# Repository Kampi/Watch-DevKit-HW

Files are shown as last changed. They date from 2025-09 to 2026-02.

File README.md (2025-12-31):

# ZSWatch-Watch-DevKit



## 📑 Table of Contents

- [ZSWatch-Watch-DevKit](#zswatch-watch-devkit)
  - [📑 Table of Contents](#-table-of-contents)
  - [📖 About](#-about)
  - [📂 Directory Breakdown](#-directory-breakdown)
  - [Purchasing](#purchasing)
  - [Ressources](#ressources)
  - [👨‍💻 Maintainer](#-maintainer)

## 📖 About

The **ZSWatch-Watch-DevKit** project provides the hardware design and production files for a smartwatch development board tailored to the ZSWatch ecosystem.
It is built with **KiCad** and integrates a full **CI/CD pipeline** using **KiBot**, ensuring reproducible outputs for documentation, manufacturing, and releases.

Key features:

- 🛠️ Open-source hardware design
- 📦 Automated generation of Gerber, BoM, and documentation via KiBot
- 🔄 Workflow stages (DRAFT → PRELIMINARY → CHECKED → RELEASED) for structured releases
- 📝 Clear documentation and changelog to track progress
- 🌍 Designed with collaboration and transparency in mind

Please check the [wiki](https://github.com/ZSWatch/ZSWatch/wiki) for more information about the project.

You can also view this project on [CADLAB.io](https://cadlab.io/project/29658). 

## 📂 Directory Breakdown

- **`.github`**: GitHub related files
- **`.gitignore`**: Ignored files list
- **`devkit`**: KiCad project for the devkit
- **`production`**: Manufacturing outputs (Gerbers, documentation, etc.)
- **`CHANGELOG.md`**: Version history
- **`LICENSE`**: Project license (GPL-3.0)
- **`README.md`**: Project overview

## Purchasing

TBD

## Ressources

- [KiBot Template](https://github.com/nguyen-v/KDT_Hierarchical_KiBot)

## 👨‍💻 Maintainer

- [Daniel Kampert](mailto:danielkameprt@kampis-elektroecke.de)

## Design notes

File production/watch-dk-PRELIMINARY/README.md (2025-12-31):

<p align="center" width="100%">
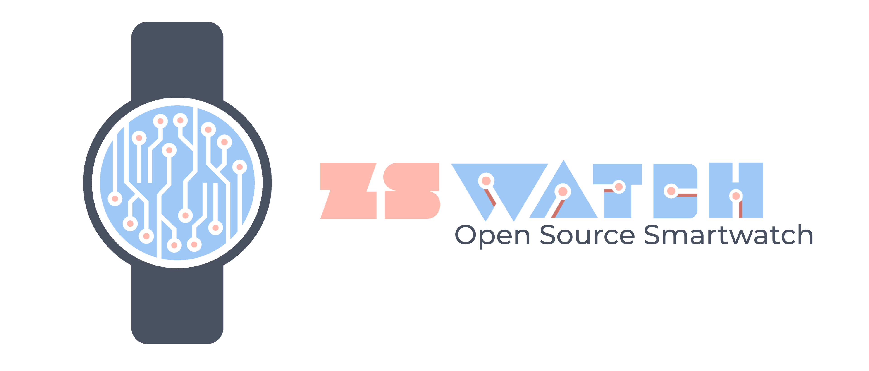
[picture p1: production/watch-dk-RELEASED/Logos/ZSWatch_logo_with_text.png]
  
</p>

<h1 align="center">Watch-DevKit-HW</h1>

<p align="center" width="100%">
  <a href="https://github.com/ZSWatch/Watch-DevKit-HW/actions/workflows/devkit.yaml">
    
  </a>
</p>

***

<p align="center">
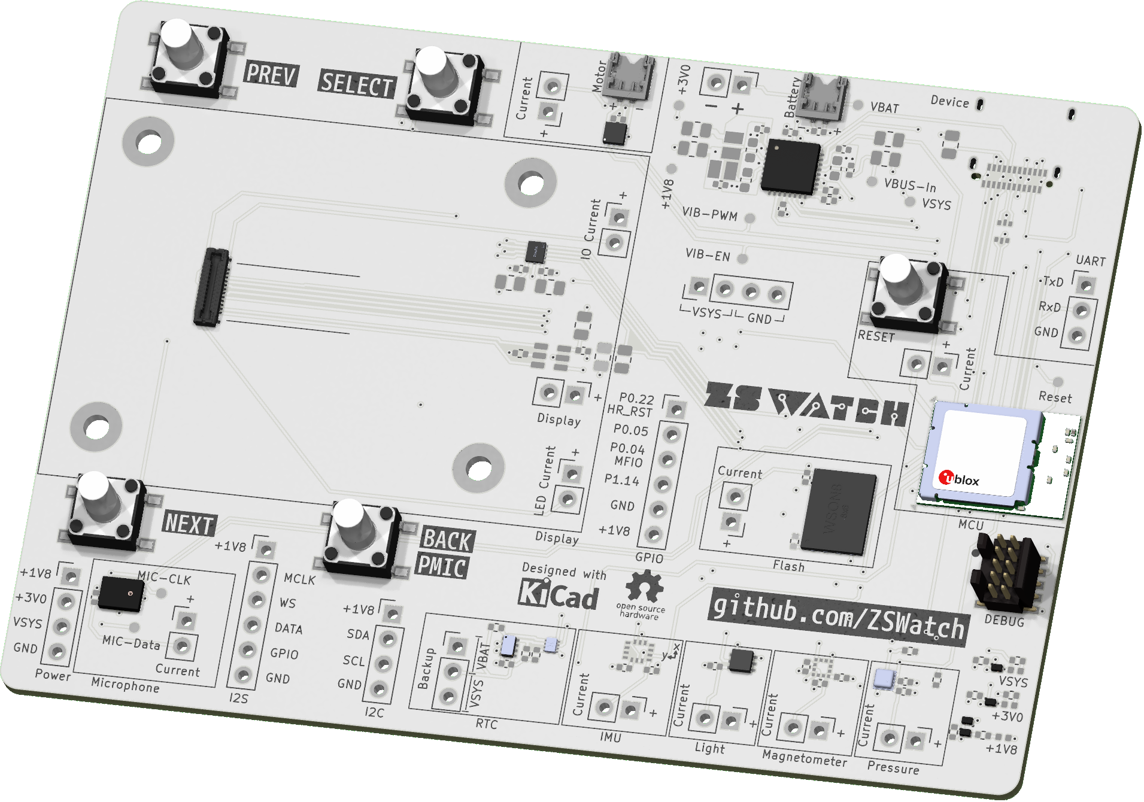
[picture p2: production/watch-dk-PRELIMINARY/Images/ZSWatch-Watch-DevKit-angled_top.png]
3D Top Angled
  
&nbsp; &nbsp; &nbsp; &nbsp;
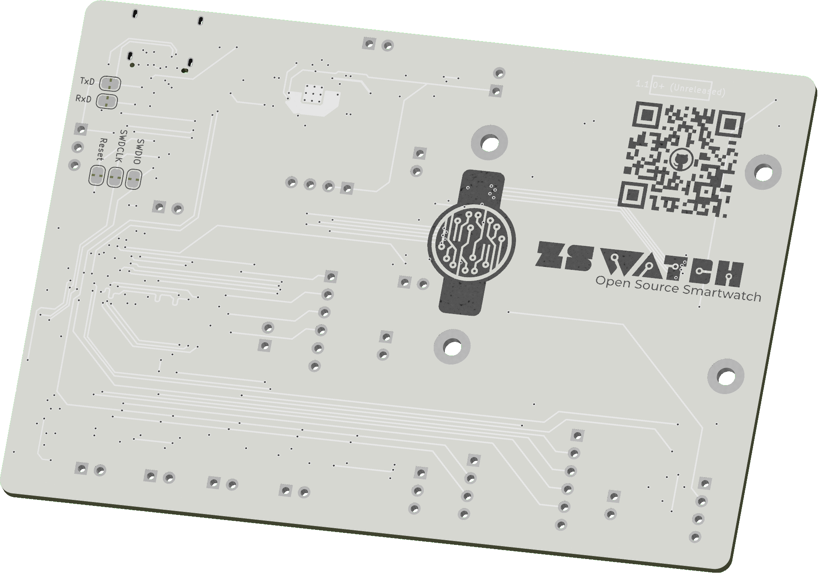
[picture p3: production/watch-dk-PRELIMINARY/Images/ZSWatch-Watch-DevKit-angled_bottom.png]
3D Bottom Angled
  
</p>

***

## SPECIFICATIONS

| Parameter | Value |
| --- | --- |
| Dimensions | 100.0 × 70.0 mm |

***

## DIRECTORY STRUCTURE

    .
    ├─ Computations       # Misc calculations
    ├─ HTML               # HTML files for generated webpage
    ├─ Images             # Pictures and renders
    │
    ├─ kibot_resources    # External resources for KiBot
    │  ├─ colors          # Color theme for KiCad
    │  ├─ fonts           # Fonts used in the project
    │  ├─ scripts         # External scripts used with KiBot
    │  └─ templates       # Templates for KiBot generated reports
    │
    ├─ kibot_yaml         # KiBot YAML config files
    ├─ KiRI               # KiRI (PCB diff viewer) files
    │
    ├─ lib                # KiCad footprint and symbol libraries
    │  ├─ 3d_models       # Component 3D models
    │  ├─ lib_fp          # Footprint libraries
    │  └─ lib_sym         # Symbol libraries
    │
    ├─ logos              # Logos
    │
    ├─ Manufacturing      # Assembly and fabrication documents
    │  ├─ Assembly        # Assembly documents (BoM, pos, notes)
    │  │
    │  └─ Fabrication     # Fabrication documents (ZIP, notes)
    │     ├─ Drill Tables # CSV drill tables
    │     └─ Gerbers      # Gerbers
    │
    ├─ Report             # Reports for ERC/DRC
    ├─ Schematic          # PDF of schematic
    ├─ templates          # Title block templates
    ├─ Testing
    │  └─ Testpoints      # Testpoints tables
    │
    └─ Variants           # Outputs for assembly variants

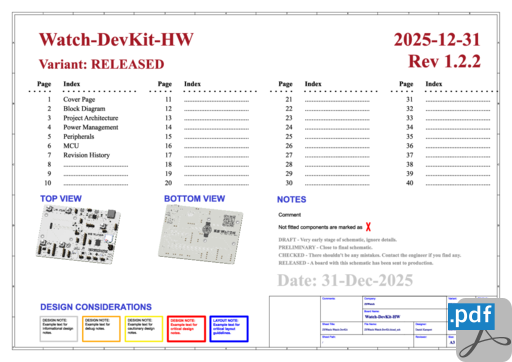
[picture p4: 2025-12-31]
production/watch-dk-RELEASED/HTML/images/cat_pdf_schematic_ZSWatch-Watch-DevKit-schematic.png

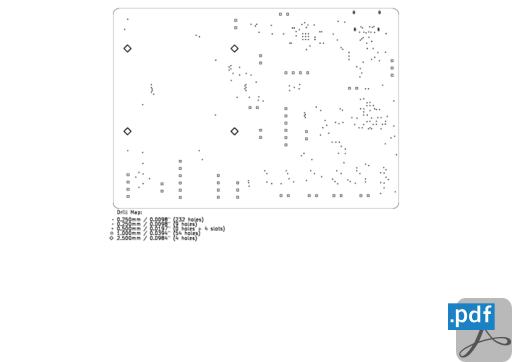
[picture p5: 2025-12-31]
production/watch-dk-RELEASED/HTML/images/cat_pdf_drill_map_ZSWatch-Watch-DevKit-PTH_drill_map.png

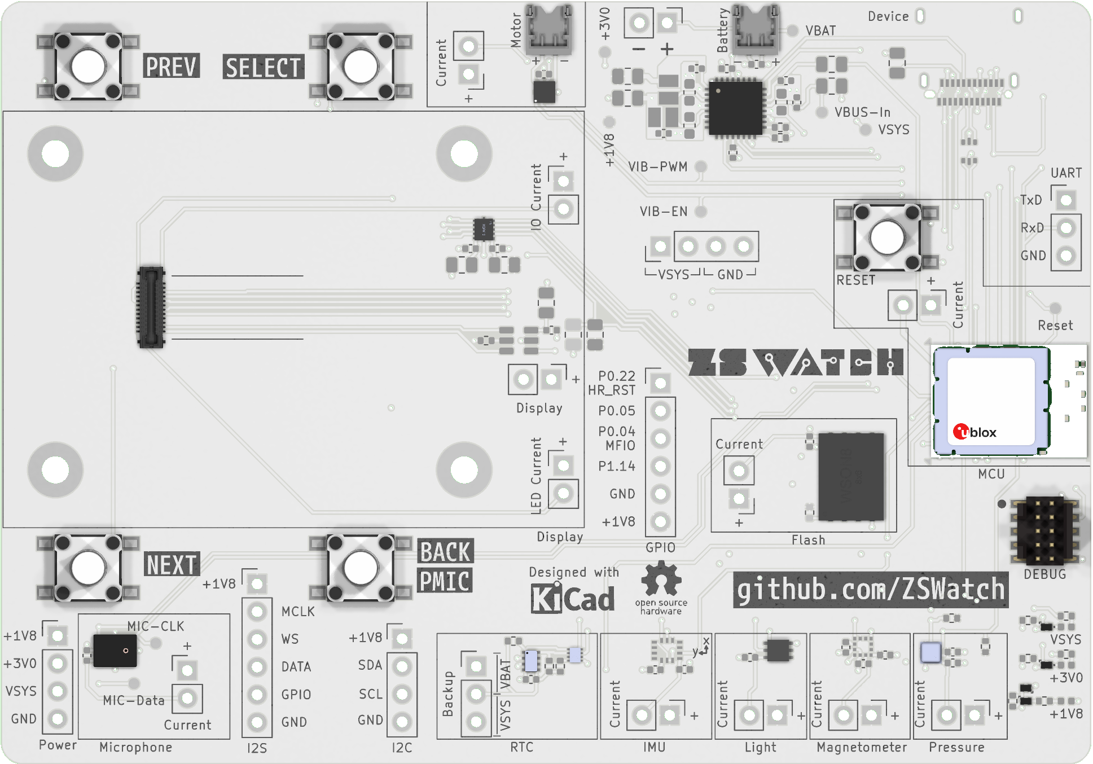
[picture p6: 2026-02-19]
production/watch-dk-PRELIMINARY/Images/ZSWatch-Watch-DevKit-top.png

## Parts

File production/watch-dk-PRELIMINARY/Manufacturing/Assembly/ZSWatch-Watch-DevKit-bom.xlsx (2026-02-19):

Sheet: BoM
Bill of Materials
Schematic: | ZSWatch-Watch-DevKit | Component Groups: | 50
Variant: | PRELIMINARY | Component Count: | 111 (81 SMD/ 19 THT)
Revision: |  | Fitted Components: | 111 (81 SMD/ 19 THT)
Date: | 2025-07-13 | Number of PCBs: | 1
KiCad Version: | 9.0.7+1 | Total Components: | 111
Row | Quantity Per PCB | References | manf | manf# | Datasheet | Footprint | Description
1 | 13 | C402 C501 C502 C503 C504 C507 C508 C509 C510 C511 C602 C603 C604 | KYOCERA AVX | 0402ZC104KAT4A | https://datasheets.kyocera-avx.com/KGM_X7R.pdf | C_0402_1005Metric | Unpolarized capacitor, small symbol
2 | 1 | C505 | KYOCERA AVX | 04023C224KAT2A | https://datasheets.kyocera-avx.com/KGM_X7R.pdf | C_0402_1005Metric | Unpolarized capacitor, small symbol
3 | 3 | C401 C405 C601 | KYOCERA AVX | 04023D105KAT2A | https://datasheets.kyocera-avx.com/cx5r.pdf | C_0402_1005Metric | Unpolarized capacitor, small symbol
4 | 1 | C403 | KYOCERA AVX | 0402ZD225MAT2A | https://datasheets.kyocera-avx.com/cx5r.pdf | C_0402_1005Metric | Unpolarized capacitor, small symbol
5 | 4 | C404 C406 C408 C506 | Murata Electronics | GRJ155R60J106ME11D | https://search.murata.co.jp/Ceramy/image/img/A01X/G101/ENG/GRJ155R60J106ME11-02A.pdf | C_0402_1005Metric | Unpolarized capacitor, small symbol
6 | 3 | C407 C409 C410 | KYOCERA AVX | KGM15CR50J106MT | https://datasheets.kyocera-avx.com/cx5r-KGM.pdf | C_0603_1608Metric | Unpolarized capacitor, small symbol
7 | 1 | D403 | Lumex | SML-LX0402SUGC-TR | https://www.mouser.de/datasheet/3/389/1/SSF-LXH100GD-RP.pdf | LED_0402_1005Metric | Light emitting diode
8 | 1 | D401 | Lumex | SML-LX0402SUGC-TR | https://www.mouser.de/datasheet/3/389/1/SSF-LXH100GD-RP.pdf | LED_0402_1005Metric | Light emitting diode
9 | 1 | D402 | Lumex | SML-LX0402SUGC-TR | https://www.mouser.de/datasheet/3/389/1/SSF-LXH100GD-RP.pdf | LED_0402_1005Metric | Light emitting diode
10 | 1 | IC501 | Broadcom / Avago | APDS-9306-065 | https://docs.broadcom.com/docs/AV02-4755EN | Broadcom_DFN-6_2x2mm_P0.65mm | Ambient Light Sensor, I2C interface, 1.7-3.6V, DFN-6
11 | 1 | IC502 | Bosch | BMI270 | https://www.bosch-sensortec.com/media/boschsensortec/downloads/datasheets/bst-bmi270-ds000.pdf | Bosch_LGA-14_3x2.5mm_P0.5mm_LayoutBorder3x4y
12 | 1 | IC504 | Bosch | BMP581 | https://www.bosch-sensortec.com/media/boschsensortec/downloads/datasheets/bst-bmp581-ds004.pdf | Bosch_LGA-10_2x2mm_P0.5mm_ClockwisePinNumbering
13 | 1 | IC505 | Texas Instruments | DRV2603RUNT | https://www.ti.com/lit/ds/symlink/drv2603.pdf?HQS=dis-mous-null-mousermode-dsf-pf-null-wwe&ts=1692200896697 | WQFN-10_2x2mm_P0.5mm
14 | 1 | IC601 | onsemi / Fairchild | FAN5622SX | https://www.onsemi.com/download/data-sheet/pdf/fan5626-d.pdf | TSOT-23-6
15 | 1 | IC503 | STMicroelectronics | LIS2MDLTR | http://www.st.com/content/ccc/resource/technical/document/datasheet/group3/29/13/d1/e0/9a/4d/4f/30/DM00395193/files/DM00395193.pdf/jcr:content/translations/en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 | LGA-12_2x2mm_P0.5mm
16 | 1 | IC603 | Macronix | MX25U51245GZ4I00 | https://www.mouser.de/datasheet/2/819/MX25U51245G_2c_1_8V_2c_512Mb_2c_v1_4-3371129.pdf | WSON-8-1EP_8x6mm_P1.27mm_EP3.4x4.3mm
17 | 1 | IC604 | NXP Semiconductors | NTS0104GU12,115 | https://www.nxp.com/docs/en/data-sheet/NTS0104.pdf | XQFN-12-1.7x2mm_P0.4mm
18 | 1 | IC506 | NXP Semiconductors | PCA9306JKZ | https://www.nxp.com/docs/en/data-sheet/PCA9306.pdf | XSON-8_0.65x0.17mm_P0.35mm | Dual bidirectional I2C Bus and SMBus voltage level translator
19 | 1 | IC507 | Micro Crystal | RV-8263-C8 32.768kHz-20PPM-TA-QA | https://www.microcrystal.com/fileadmin/Media/Products/RTC/Datasheet/RV-8263-C8.pdf | RV-8263-C8
20 | 1 | IC602 | STMicroelectronics | USBLC6-2P6 | https://www.st.com/resource/en/datasheet/usblc6-2.pdf | SOT-666 | Very low capacitance ESD protection diode, 2 data-line, SOT-666
21 | 1 | IC401 | Nordic Semiconductor | nPM1300-QEAA-R7 | https://infocenter.nordicsemi.com/index.jsp?topic=%2Fstruct_pmic%2Fstruct%2Fnpm1300.html | QFN-32-1EP_5x5mm_P0.5mm_EP3.6x3.6mm_ThermalVias
22 | 11 | J501 J502 J503 J504 J505 J506 J507 J601 J602 J603 J604 | Würth Elektronik | 60900213421 | https://www.we-online.com/katalog/datasheet/60900213421.pdf |  | Generic jumper cap
23 | 2 | L401 L402 | ABRACON | ASMPH-0806-2R2M-T | https://www.mouser.de/datasheet/3/184/1/ASMPH-0806.pdf | L_0806_2016 | Inductor
24 | 1 | M601 | u-blox | NORA-B106-00B | https://www.u-blox.com/docs/UBX-20027119 | NORA-B106
25 | 1 | MK501 | Knowles | SPK0641HT4H-1 | https://www.knowles.com/docs/default-source/default-document-library/sph0645lm4h-1-datasheet.pdf | SPK0641HT4H-1 | Digital MEMS Microphone
26 | 3 | Q401 Q402 Q403 | Nexperia | PMZ550UNEYL | https://assets.nexperia.com/documents/data-sheet/PMZ550UNE.pdf | DFN-1006-3 | 0.59A Id, 30V Vds, N-Channel MOSFET, DFN-1006-3
27 | 1 | Q404 | ROHM Semiconductor | PMZB320UPEYL | https://assets.nexperia.com/documents/data-sheet/PMZB320UPE.pdf | DFN-1006-3 | 1A Id, 30V Vds
28 | 8 | R409 R410 R411 R412 R602 R603 R615 R616 | Bourns | CR0805-J/-000ELF | https://www.mouser.de/datasheet/3/40/1/cr.pdf | R_0805_2012Metric | Resistor, small symbol
29 | 3 | R404 R405 R406 | YAGEO | RC0402FR-07560RL | https://www.mouser.com/catalog/specsheets/YAGEO_PYu_RC_Group_51_RoHS_L_12.pdf | R_0402_1005Metric | Resistor, small symbol
30 | 2 | R501 R502 | YAGEO | RC0402FR-071K8L | https://www.mouser.com/catalog/specsheets/YAGEO_PYu_RC_Group_51_RoHS_L_12.pdf | R_0402_1005Metric | Resistor, small symbol
31 | 2 | R504 R505 | YAGEO | RC0402FR-073K3L | https://www.mouser.com/catalog/specsheets/YAGEO_PYu_RC_Group_51_RoHS_L_12.pdf | R_0402_1005Metric | Resistor, small symbol
32 | 1 | R601 | YAGEO | RC0402FR-0712KL | https://www.mouser.com/catalog/specsheets/YAGEO_PYu_RC_Group_51_RoHS_L_12.pdf | R_0402_1005Metric | Resistor, small symbol
33 | 1 | R407 | YAGEO | RC0402FR-0747KL | https://www.mouser.com/catalog/specsheets/YAGEO_PYu_RC_Group_51_RoHS_L_12.pdf | R_0402_1005Metric | Resistor, small symbol
34 | 4 | R401 R402 R403 R408 | YAGEO | RC0402FR-07100KL | https://www.mouser.com/catalog/specsheets/YAGEO_PYu_RC_Group_51_RoHS_L_12.pdf | R_0402_1005Metric | Resistor, small symbol
35 | 1 | R613 | YAGEO | RC0805FR-07100KL | https://www.mouser.com/catalog/specsheets/YAGEO_PYu_RC_Group_51_RoHS_L_12.pdf | R_0805_2012Metric | Resistor, small symbol
36 | 1 | R503 | YAGEO | RC0402FR-07200KL | https://www.mouser.com/catalog/specsheets/YAGEO_PYu_RC_Group_51_RoHS_L_12.pdf | R_0402_1005Metric | Resistor, small symbol
37 | 1 | S601 | Wurth Elektronik | 430182050816 | https://www.we-online.com/components/products/datasheet/430182050816.pdf | WS-TASV-6x6 | Push button switch, generic, two pins
38 | 1 | S501 | Wurth Elektronik | 430182050816 | https://www.we-online.com/components/products/datasheet/430182050816.pdf | WS-TASV-6x6 | Push button switch, generic, two pins
39 | 1 | S502 | Wurth Elektronik | 430182050816 | https://www.we-online.com/components/products/datasheet/430182050816.pdf | WS-TASV-6x6 | Push button switch, generic, two pins
40 | 1 | S503 | Wurth Elektronik | 430182050816 | https://www.we-online.com/components/products/datasheet/430182050816.pdf | WS-TASV-6x6 | Push button switch, generic, two pins
41 | 1 | S504 | Wurth Elektronik | 430182050816 | https://www.we-online.com/components/products/datasheet/430182050816.pdf | WS-TASV-6x6 | Push button switch, generic, two pins
42 | 12 | X401 X501 X503 X505 X506 X507 X508 X602 X606 X607 X609 X610 | Amphenol FCI | 77311-818-02LF | https://cdn.amphenol-cs.com/media/wysiwyg/files/documentation/datasheet/boardwiretoboard/bwb_bergstik.pdf | PinHeader_1x02_P2.54mm_Vertical | Generic connector, single row, 01x02, script generated (kicad-library-utils/schlib/autogen/connector/)
43 | 2 | X402 X509 | Molex | 78171-0002 | https://www.molex.com/en-us/products/part-detail-pdf/781710002?display=pdf | 78171-0002 | Generic connector, single row, 01x02, script generated (kicad-library-utils/schlib/autogen/connector/)
44 | 2 | X510 X604 | Amphenol FCI | 77311-818-03LF | ~ | PinHeader_1x03_P2.54mm_Vertical | Generic connector, single row, 01x03, script generated (kicad-library-utils/schlib/autogen/connector/)
45 | 1 | X601 | GCT | BD125-10-A-0305-0580-L-B | https://gct.co/files/drawings/BD125.pdf | SHF-105-01-L-D-SM-TR | Cortex Debug Connector, standard ARM Cortex-M SWD and JTAG interface
46 | 1 | X603 | Amphenol Commercial Products | 12401610E4#2A | https://www.usb.org/sites/default/files/documents/usb_type-c.zip | USB_C_Receptacle_Amphenol_12401610E4-2A | USB Full-Featured Type-C Receptacle connector
47 | 1 | X608 | EastRising | OK-24F024-04 | https://www.buydisplay.com/download/manual/ER-TFT1.28-2_Datasheet.pdf | ER-CON0.4-24P
48 | 1 | X605 | Amphenol FCI | 77311-802-06LF | ~https://cdn.amphenol-cs.com/media/wysiwyg/files/documentation/datasheet/boardwiretoboard/bwb_bergstik.pdf | PinHeader_1x06_P2.54mm_Vertical | Generic connector, single row, 01x06, script generated (kicad-library-utils/schlib/autogen/connector/)
49 | 1 | X502 | Amphenol FCI | 77311-818-06LF | ~ | PinHeader_1x06_P2.54mm_Vertical | Generic connector, single row, 01x06, script generated (kicad-library-utils/schlib/autogen/connector/)
50 | 3 | X403 X404 X504 | Amphenol FCI | 77311-818-04LF | https://cdn.amphenol-cs.com/media/wysiwyg/files/documentation/datasheet/boardwiretoboard/bwb_bergstik.pdf | PinHeader_1x04_P2.54mm_Vertical | Generic connector, single row, 01x04, script generated (kicad-library-utils/schlib/autogen/connector/)

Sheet: Costs
Bill of Materials
Schematic: | ZSWatch-Watch-DevKit |  |  |  |  | Board Qty: | 1
Variant: | PRELIMINARY |  |  |  |  | Unit Cost: | $50.52
Revision: |  |  |  |  |  | Total Cost: | $50.52 |  |  |  |  | $50.52 | 45 of 50 parts found
Date: | 2025-07-13
KiCad Version: | 9.0.7+1
Global Part Info |  |  |  |  |  |  |  | Mouser
References | Value | Footprint | Manf | Manf# | Build Quantity | Unit$ | Ext$ | Avail | Purch | Unit$ | MOQ | Ext$ | Cat#
C402 C501 C502 C503 C504 C507 C508 C509 C510 C511 C602 C603 C604 | 100n | C_0402_1005Metric | KYOCERA AVX | 0402ZC104KAT4A (https://datasheets.kyocera-avx.com/KGM_X7R.pdf) | 13 | $0.033 | $0.43 | 137684 |  | $0.033 | 1 | $0.43 | 581-0402ZC104KAT4A (https://www.mouser.de/ProductDetail/KYOCERA-AVX/0402ZC104KAT4A?qs=U0WCSYU1dIfUbdc9rwYMdg%3D%3D)
C505 | 220n | C_0402_1005Metric | KYOCERA AVX | 04023C224KAT2A (https://datasheets.kyocera-avx.com/KGM_X7R.pdf) | 1 | $0.377 | $0.38 | 13143 |  | $0.377 | 1 | $0.38 | 581-04023C224KAT2A (https://www.mouser.de/ProductDetail/KYOCERA-AVX/04023C224KAT2A?qs=5aG0NVq1C4xPiFAUpyWZQQ%3D%3D)
C401 C405 C601 | 1u | C_0402_1005Metric | KYOCERA AVX | 04023D105KAT2A (https://datasheets.kyocera-avx.com/cx5r.pdf) | 3 | $0.184 | $0.55 | 119113 |  | $0.184 | 1 | $0.55 | 581-04023D105KAT2A (https://www.mouser.de/ProductDetail/KYOCERA-AVX/04023D105KAT2A?qs=%252BdQmOuGyFcETexelcKkD5g%3D%3D)
C403 | 2u2 | C_0402_1005Metric | KYOCERA AVX | 0402ZD225MAT2A (https://datasheets.kyocera-avx.com/cx5r.pdf) | 1 | $0.133 | $0.13 | 14420 |  | $0.133 | 1 | $0.13 | 581-0402ZD225MAT2A (https://www.mouser.de/ProductDetail/KYOCERA-AVX/0402ZD225MAT2A?qs=ZBeOGGPQgEESIGO3bvTmzg%3D%3D)
C404 C406 C408 C506 | 10u | C_0402_1005Metric | Murata Electronics | GRJ155R60J106ME11D (https://search.murata.co.jp/Ceramy/image/img/A01X/G101/ENG/GRJ155R60J106ME11-02A.pdf) | 4
C407 C409 C410 | 10u | C_0603_1608Metric | KYOCERA AVX | KGM15CR50J106MT (https://datasheets.kyocera-avx.com/cx5r-KGM.pdf) | 3 | $0.184 | $0.55 | NonStk |  | $0.184 | 1 | $0.55 | 581-KGM15CR50J106MT (https://www.mouser.de/ProductDetail/KYOCERA-AVX/KGM15CR50J106MT?qs=Jm2GQyTW%2Fbif%2Fz3WIqU0uQ%3D%3D)
D403 | +1V8 | LED_0402_1005Metric | Lumex | SML-LX0402SUGC-TR (https://www.mouser.de/datasheet/3/389/1/SSF-LXH100GD-RP.pdf) | 1 | $0.611 | $0.61 | 90351 |  | $0.611 | 1 | $0.61 | 696-SML-LX0402SUGCTR (https://www.mouser.de/ProductDetail/Lumex/SML-LX0402SUGC-TR?qs=CpNDN%2FcFIdcI%252BZNfbfZN3g%3D%3D)
D401 | +3V0 | LED_0402_1005Metric | Lumex | SML-LX0402SUGC-TR (https://www.mouser.de/datasheet/3/389/1/SSF-LXH100GD-RP.pdf) | 1 | $0.611 | $0.61 | 90351 |  | $0.611 | 1 | $0.61 | 696-SML-LX0402SUGCTR (https://www.mouser.de/ProductDetail/Lumex/SML-LX0402SUGC-TR?qs=CpNDN%2FcFIdcI%252BZNfbfZN3g%3D%3D)
D402 | VSYS | LED_0402_1005Metric | Lumex | SML-LX0402SUGC-TR (https://www.mouser.de/datasheet/3/389/1/SSF-LXH100GD-RP.pdf) | 1 | $0.611 | $0.61 | 90351 |  | $0.611 | 1 | $0.61 | 696-SML-LX0402SUGCTR (https://www.mouser.de/ProductDetail/Lumex/SML-LX0402SUGC-TR?qs=CpNDN%2FcFIdcI%252BZNfbfZN3g%3D%3D)
IC501 | APDS-9306-065 | Broadcom_DFN-6_2x2mm_P0.65mm | Broadcom / Avago | APDS-9306-065 (https://docs.broadcom.com/docs/AV02-4755EN) | 1 | $0.999 | $1.00 | 49005 |  | $0.999 | 1 | $1.00 | 630-APDS-9306-065 (https://www.mouser.de/ProductDetail/Broadcom-Avago/APDS-9306-065?qs=JUmsgfbaopRTut8Cx4p19A%3D%3D)
IC502 | BMI270 | Bosch_LGA-14_3x2.5mm_P0.5mm_LayoutBorder3x4y | Bosch | BMI270 (https://www.bosch-sensortec.com/media/boschsensortec/downloads/datasheets/bst-bmi270-ds000.pdf) | 1 | $3.802 | $3.80 | 3646 |  | $3.802 | 1 | $3.80 | 262-BMI270 (https://www.mouser.de/ProductDetail/Bosch-Sensortec/BMI270?qs=u16ybLDytRYIj%252BjQEee88A%3D%3D)
IC504 | BMP581 | Bosch_LGA-10_2x2mm_P0.5mm_ClockwisePinNumbering | Bosch | BMP581 (https://www.bosch-sensortec.com/media/boschsensortec/downloads/datasheets/bst-bmp581-ds004.pdf) | 1 | $3.032 | $3.03 | 3148 |  | $3.032 | 1 | $3.03 | 262-BMP581 (https://www.mouser.de/ProductDetail/Bosch-Sensortec/BMP581?qs=Li%252BoUPsLEntPL9tlFmcgXg%3D%3D)
IC505 | DRV2603RUNT | WQFN-10_2x2mm_P0.5mm | Texas Instruments | DRV2603RUNT (https://www.ti.com/lit/ds/symlink/drv2603.pdf?HQS=dis-mous-null-mousermode-dsf-pf-null-wwe&ts=1692200896697) | 1 | $1.646 | $1.65 | 709 |  | $1.646 | 1 | $1.65 | 595-DRV2603RUNT (https://www.mouser.de/ProductDetail/Texas-Instruments/DRV2603RUNT?qs=y0LsnOHuQQ66fXxKAgGo4A%3D%3D)
IC601 | FAN5622SX | TSOT-23-6 | onsemi / Fairchild | FAN5622SX (https://www.onsemi.com/download/data-sheet/pdf/fan5626-d.pdf) | 1 | $0.662 | $0.66 | 7331 |  | $0.662 | 1 | $0.66 | 512-FAN5622SX (https://www.mouser.de/ProductDetail/onsemi/FAN5622SX?qs=kDD%2FdQe9TTcQ2FOj0Q0xJA%3D%3D)
IC503 | LIS2MDLTR | LGA-12_2x2mm_P0.5mm | STMicroelectronics | LIS2MDLTR (http://www.st.com/content/ccc/resource/technical/document/datasheet/group3/29/13/d1/e0/9a/4d/4f/30/DM00395193/files/DM00395193.pdf/jcr:content/translations/en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) | 1 | $2.594 | $2.59 | NonStk |  | $2.594 | 1 | $2.59 | 511-LIS2MDLTR (https://www.mouser.de/ProductDetail/STMicroelectronics/LIS2MDLTR?qs=5aG0NVq1C4wS0n6b5NiBNQ%3D%3D)
IC603 | MX25U51245GZ4I00 | WSON-8-1EP_8x6mm_P1.27mm_EP3.4x4.3mm | Macronix | MX25U51245GZ4I00 (https://www.mouser.de/datasheet/2/819/MX25U51245G_2c_1_8V_2c_512Mb_2c_v1_4-3371129.pdf) | 1 |  |  | NonStk |  |  | 4800 |  | 95-25U51245GZ4I00T (https://www.mouser.de/ProductDetail/Macronix/MX25U51245GZ4I00-T?qs=mELouGlnn3eDhn5HUfyQFw%3D%3D)
IC604 | NTS0104GU12 | XQFN-12-1.7x2mm_P0.4mm | NXP Semiconductors | NTS0104GU12,115 (https://www.nxp.com/docs/en/data-sheet/NTS0104.pdf) | 1 | $1.100 | $1.10 | 7162 |  | $1.100 | 1 | $1.10 | 771-NTS0104GU12115 (https://www.mouser.de/ProductDetail/NXP-Semiconductors/NTS0104GU12115?qs=A1cBxND5mHLxKBBpk2Em8w%3D%3D)
IC506 | PCA9306JK | XSON-8_0.65x0.17mm_P0.35mm | NXP Semiconductors | PCA9306JKZ (https://www.nxp.com/docs/en/data-sheet/PCA9306.pdf) | 1 | $0.713 | $0.71 | 4843 |  | $0.713 | 1 | $0.71 | 771-PCA9306JKZ (https://www.mouser.de/ProductDetail/NXP-Semiconductors/PCA9306JKZ?qs=2SLPxufLcgDRMLW40GZIdg%3D%3D)
IC507 | RV-8263-C8 | RV-8263-C8 | Micro Crystal | RV-8263-C8 32.768kHz-20PPM-TA-QA (https://www.microcrystal.com/fileadmin/Media/Products/RTC/Datasheet/RV-8263-C8.pdf) | 1 | $2.132 | $2.13 | 190 |  | $2.132 | 1 | $2.13 | 428-204291-MC01 (https://www.mouser.de/ProductDetail/Micro-Crystal/RV-8263-C8-32.768kHz-20PPM-TA-QA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)
IC602 | USBLC6-2P6 | SOT-666 | STMicroelectronics | USBLC6-2P6 (https://www.st.com/resource/en/datasheet/usblc6-2.pdf) | 1 | $0.448 | $0.45 | 77385 |  | $0.448 | 1 | $0.45 | 511-USBLC6-2P6 (https://www.mouser.de/ProductDetail/STMicroelectronics/USBLC6-2P6?qs=6ARB0lp6jlViGcbUSvj1Mw%3D%3D)
IC401 | nPM1300-QEXX | QFN-32-1EP_5x5mm_P0.5mm_EP3.6x3.6mm_ThermalVias | Nordic Semiconductor | nPM1300-QEAA-R7 (https://infocenter.nordicsemi.com/index.jsp?topic=%2Fstruct_pmic%2Fstruct%2Fnpm1300.html) | 1 | $1.564 | $1.56 | 3589 |  | $1.564 | 1 | $1.56 | 949-NPM1300-QEAA-R7 (https://www.mouser.de/ProductDetail/Nordic-Semiconductor/nPM1300-QEAA-R7?qs=3pZoU%2F6IRTj0hxAp51B2zA%3D%3D)
J501 J502 J503 J504 J505 J506 J507 J601 J602 J603 J604 | Jumper |  | Würth Elektronik | 60900213421 (https://www.we-online.com/katalog/datasheet/60900213421.pdf) | 11 | $0.316 | $3.48 | 61104 |  | $0.316 | 1 | $3.48 | 710-60900213421 (https://www.mouser.de/ProductDetail/Wurth-Elektronik/60900213421?qs=W%252B2sBeLta1bsO5t19%2FBN7Q%3D%3D)
L401 L402 | 2u2 | L_0806_2016 | ABRACON | ASMPH-0806-2R2M-T (https://www.mouser.de/datasheet/3/184/1/ASMPH-0806.pdf) | 2 | $0.235 | $0.47 | 4740 |  | $0.235 | 1 | $0.47 | 815-ASMPH-0806-2R2MT (https://www.mouser.de/ProductDetail/ABRACON/ASMPH-0806-2R2M-T?qs=73bO73rho2gUhCeImyNTuw%3D%3D)
M601 | NORA-B106 | NORA-B106 | u-blox | NORA-B106-00B (https://www.u-blox.com/docs/UBX-20027119) | 1 | $9.275 | $9.27 | 2577 |  | $9.275 | 1 | $9.27 | 377-NORA-B106-00B (https://www.mouser.de/ProductDetail/u-blox/NORA-B106-00B?qs=T94vaHKWudSCPE72v3os%252Bg%3D%3D)
MK501 | SPK0641HT4H-1 | SPK0641HT4H-1 | Knowles | SPK0641HT4H-1 (https://www.knowles.com/docs/default-source/default-document-library/sph0645lm4h-1-datasheet.pdf) | 1 | $1.931 | $1.93 | 12260 |  | $1.931 | 1 | $1.93 | 721-SPK0641HT4H-1 (https://www.mouser.de/ProductDetail/Syntiant/SPK0641HT4H-1?qs=fAHHVMwC%252BbgQkuKPcedJGQ%3D%3D)
Q401 Q402 Q403 | PMZ550UNEYL | DFN-1006-3 | Nexperia | PMZ550UNEYL (https://assets.nexperia.com/documents/data-sheet/PMZ550UNE.pdf) | 3 | $0.316 | $0.95 | NonStk |  | $0.316 | 1 | $0.95 | 771-PMZ550UNEYL (https://www.mouser.de/ProductDetail/Nexperia/PMZ550UNEYL?qs=d7b8vw%252BBfo0cI9ZzM5Blzg%3D%3D)
Q404 | PMZB320UPEYL | DFN-1006-3 | ROHM Semiconductor | PMZB320UPEYL (https://assets.nexperia.com/documents/data-sheet/PMZB320UPE.pdf) | 1 | $0.387 | $0.39 | 549 |  | $0.387 | 1 | $0.39 | 771-PMZB320UPEYL (https://www.mouser.de/ProductDetail/Nexperia/PMZB320UPEYL?qs=d7b8vw%252BBfo3qFKLhpfjnHw%3D%3D)
R409 R410 R411 R412 R602 R603 R615 R616 | 0R | R_0805_2012Metric | Bourns | CR0805-J/-000ELF (https://www.mouser.de/datasheet/3/40/1/cr.pdf) | 8 | $0.142 | $1.14 | 58195 |  | $0.142 | 1 | $1.14 | 652-CR0805-J/-000ELF (https://www.mouser.de/ProductDetail/Bourns/CR0805-J-000ELF?qs=wKk%252BLl0qPROQEEzWY8Q13A%3D%3D)
R404 R405 R406 | 560R | R_0402_1005Metric | YAGEO | RC0402FR-07560RL (https://www.mouser.com/catalog/specsheets/YAGEO_PYu_RC_Group_51_RoHS_L_12.pdf) | 3 | $0.102 | $0.31 | 263421 |  | $0.102 | 1 | $0.31 | 603-RC0402FR-07560RL (https://www.mouser.de/ProductDetail/YAGEO/RC0402FR-07560RL?qs=Is6ZsIPfHkaar5c8drXNXg%3D%3D)
R501 R502 | 1k8 | R_0402_1005Metric | YAGEO | RC0402FR-071K8L (https://www.mouser.com/catalog/specsheets/YAGEO_PYu_RC_Group_51_RoHS_L_12.pdf) | 2 | $0.102 | $0.20 | 152031 |  | $0.102 | 1 | $0.20 | 603-RC0402FR-071K8L (https://www.mouser.de/ProductDetail/YAGEO/RC0402FR-071K8L?qs=YUgVZYePFqBqgTt42z3XkQ%3D%3D)
R504 R505 | 3k3 | R_0402_1005Metric | YAGEO | RC0402FR-073K3L (https://www.mouser.com/catalog/specsheets/YAGEO_PYu_RC_Group_51_RoHS_L_12.pdf) | 2 | $0.102 | $0.20 | 1102854 |  | $0.102 | 1 | $0.20 | 603-RC0402FR-073K3L (https://www.mouser.de/ProductDetail/YAGEO/RC0402FR-073K3L?qs=V1yeUXFNrkl65xQvAbNjdg%3D%3D)
R601 | 12k | R_0402_1005Metric | YAGEO | RC0402FR-0712KL (https://www.mouser.com/catalog/specsheets/YAGEO_PYu_RC_Group_51_RoHS_L_12.pdf) | 1 | $0.102 | $0.10 | 111624 |  | $0.102 | 1 | $0.10 | 603-RC0402FR-0712KL (https://www.mouser.de/ProductDetail/YAGEO/RC0402FR-0712KL?qs=sxZXDnvRBEiY5XbuK7n6Dw%3D%3D)
R407 | 47k | R_0402_1005Metric | YAGEO | RC0402FR-0747KL (https://www.mouser.com/catalog/specsheets/YAGEO_PYu_RC_Group_51_RoHS_L_12.pdf) | 1 | $0.102 | $0.10 | 1441673 |  | $0.102 | 1 | $0.10 | 603-RC0402FR-0747KL (https://www.mouser.de/ProductDetail/YAGEO/RC0402FR-0747KL?qs=V1yeUXFNrklslMUO6Zhx5g%3D%3D)
R401 R402 R403 R408 | 100k | R_0402_1005Metric | YAGEO | RC0402FR-07100KL (https://www.mouser.com/catalog/specsheets/YAGEO_PYu_RC_Group_51_RoHS_L_12.pdf) | 4 | $0.102 | $0.41 | 4336570 |  | $0.102 | 1 | $0.41 | 603-RC0402FR-07100KL (https://www.mouser.de/ProductDetail/YAGEO/RC0402FR-07100KL?qs=mnq%2FyloZIXzTlUn7JAHSWg%3D%3D)
R613 | 100k | R_0805_2012Metric | YAGEO | RC0805FR-07100KL (https://www.mouser.com/catalog/specsheets/YAGEO_PYu_RC_Group_51_RoHS_L_12.pdf) | 1 | $0.102 | $0.10 | 407165 |  | $0.102 | 1 | $0.10 | 603-RC0805FR-07100KL (https://www.mouser.de/ProductDetail/YAGEO/RC0805FR-07100KL?qs=8Y8p%252BasKcI7rEWn6FcVdAA%3D%3D)
R503 | 200k | R_0402_1005Metric | YAGEO | RC0402FR-07200KL (https://www.mouser.com/catalog/specsheets/YAGEO_PYu_RC_Group_51_RoHS_L_12.pdf) | 1 | $0.113 | $0.11 | 85713 |  | $0.113 | 1 | $0.11 | 603-RC0402FR-07200KL (https://www.mouser.de/ProductDetail/YAGEO/RC0402FR-07200KL?qs=V1yeUXFNrkmv6KaPQn%2FXDg%3D%3D)
S601 | RESET | WS-TASV-6x6 | Wurth Elektronik | 430182050816 (https://www.we-online.com/components/products/datasheet/430182050816.pdf) | 1 | $0.540 | $0.54 | 5724 |  | $0.540 | 1 | $0.54 | 710-430182050816 (https://www.mouser.de/ProductDetail/Wurth-Elektronik/430182050816?qs=wr8lucFkNMUyle0jQPgWGw%3D%3D)
S501 | SW1 | WS-TASV-6x6 | Wurth Elektronik | 430182050816 (https://www.we-online.com/components/products/datasheet/430182050816.pdf) | 1 | $0.540 | $0.54 | 5724 |  | $0.540 | 1 | $0.54 | 710-430182050816 (https://www.mouser.de/ProductDetail/Wurth-Elektronik/430182050816?qs=wr8lucFkNMUyle0jQPgWGw%3D%3D)
S502 | SW2 | WS-TASV-6x6 | Wurth Elektronik | 430182050816 (https://www.we-online.com/components/products/datasheet/430182050816.pdf) | 1 | $0.540 | $0.54 | 5724 |  | $0.540 | 1 | $0.54 | 710-430182050816 (https://www.mouser.de/ProductDetail/Wurth-Elektronik/430182050816?qs=wr8lucFkNMUyle0jQPgWGw%3D%3D)
S503 | SW3 | WS-TASV-6x6 | Wurth Elektronik | 430182050816 (https://www.we-online.com/components/products/datasheet/430182050816.pdf) | 1 | $0.540 | $0.54 | 5724 |  | $0.540 | 1 | $0.54 | 710-430182050816 (https://www.mouser.de/ProductDetail/Wurth-Elektronik/430182050816?qs=wr8lucFkNMUyle0jQPgWGw%3D%3D)
S504 | SW4 | WS-TASV-6x6 | Wurth Elektronik | 430182050816 (https://www.we-online.com/components/products/datasheet/430182050816.pdf) | 1 | $0.540 | $0.54 | 5724 |  | $0.540 | 1 | $0.54 | 710-430182050816 (https://www.mouser.de/ProductDetail/Wurth-Elektronik/430182050816?qs=wr8lucFkNMUyle0jQPgWGw%3D%3D)
X401 X501 X503 X505 X506 X507 X508 X602 X606 X607 X609 X610 | Battery | PinHeader_1x02_P2.54mm_Vertical | Amphenol FCI | 77311-818-02LF (https://cdn.amphenol-cs.com/media/wysiwyg/files/documentation/datasheet/boardwiretoboard/bwb_bergstik.pdf) | 12 | $0.162 | $1.95 | 11486 |  | $0.162 | 1 | $1.95 | 649-77311-818-02LF (https://www.mouser.de/ProductDetail/Amphenol-FCI/77311-818-02LF?qs=xJiur%252Bgubk3jL1kv%252BllNUg%3D%3D)
X402 X509 | Battery | 78171-0002 | Molex | 78171-0002 (https://www.molex.com/en-us/products/part-detail-pdf/781710002?display=pdf) | 2 | $0.529 | $1.06 | 151277 |  | $0.529 | 1 | $1.06 | 538-78171-0002 (https://www.mouser.de/ProductDetail/Molex/78171-0002?qs=Gs2o0dzr3RhBbmnwhRVwhg%3D%3D)
X510 X604 | Current | PinHeader_1x03_P2.54mm_Vertical | Amphenol FCI | 77311-818-03LF | 2 | $0.244 | $0.49 | 18083 |  | $0.244 | 1 | $0.49 | 649-77311-818-03LF (https://www.mouser.de/ProductDetail/Amphenol-FCI/77311-818-03LF?qs=xJiur%252Bgubk0LOJz9%252B0pvdw%3D%3D)
X601 | DEBUG | SHF-105-01-L-D-SM-TR | GCT | BD125-10-A-0305-0580-L-B (https://gct.co/files/drawings/BD125.pdf) | 1 | $1.386 | $1.39 | 11268 |  | $1.386 | 1 | $1.39 | 640-BD12510A305580LB (https://www.mouser.de/ProductDetail/GCT/BD125-10-A-0305-0580-L-B?qs=amGC7iS6iy%252BPUE%252B5wV8wFA%3D%3D)
X603 | Device | USB_C_Receptacle_Amphenol_12401610E4-2A | Amphenol Commercial Products | 12401610E4#2A (https://www.usb.org/sites/default/files/documents/usb_type-c.zip) | 1 | $1.208 | $1.21 | 21611 |  | $1.208 | 1 | $1.21 | 523-12401610E4#2A (https://www.mouser.de/ProductDetail/Amphenol-Commercial-Products/12401610E42A?qs=EgDjlb95zqAWvChv41w5lg%3D%3D)
X608 | Display | ER-CON0.4-24P | EastRising | OK-24F024-04 (https://www.buydisplay.com/download/manual/ER-TFT1.28-2_Datasheet.pdf) | 1
X605 | GPIO | PinHeader_1x06_P2.54mm_Vertical | Amphenol FCI | 77311-802-06LF | 1
X502 | I2S | PinHeader_1x06_P2.54mm_Vertical | Amphenol FCI | 77311-818-06LF | 1
X403 X404 X504 | Power | PinHeader_1x04_P2.54mm_Vertical | Amphenol FCI | 77311-818-04LF (https://cdn.amphenol-cs.com/media/wysiwyg/files/documentation/datasheet/boardwiretoboard/bwb_bergstik.pdf) | 3
 | USD($)/EUR(€): | 1.1845 |  |  |  | Total Purchase: | $0.00 | Buy here (https://mouser.com/bom/) |  |  |  | $0.00
 |  |  |  |  |  | Purchase description:
Created: | 2026-02-19 11:29:11
KiCost® v1.1.20 + KiBot v1.8.5

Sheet: Colors
Columns colors
KiCad Fields (default)
Generated Fields
User Fields
Empty Fields
Costs sheet colors
Best price
No manufacturer or distributor code
Not available
Purchase quantity is more than what is available
Minimum order quantity not respected
Total available part quantity is less than needed
Total purchased part quantity is less than needed
This part is obsolete
This part is listed but is not normally stocked

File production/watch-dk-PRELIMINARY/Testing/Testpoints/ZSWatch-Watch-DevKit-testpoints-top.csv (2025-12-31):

Ref. | Net | X [mm] | Y [mm]
TP401 | VBUS-In | 233.30 | -124.20
TP402 | VBAT | 230.60 | -116.72
TP403 | VSYS | 237.30 | -125.80
TP404 | +1V8 | 213.80 | -125.10
TP405 | +3V0 | 213.40 | -118.70
TP501 | MIC-CLK | 172.20 | -172.90
TP502 | MIC-DATA | 170.20 | -176.60
TP503 | VIB-EN | 222.20 | -133.30
TP504 | VIB-PWM | 222.20 | -129.20
TP601 | RESETn | 254.70 | -142.20

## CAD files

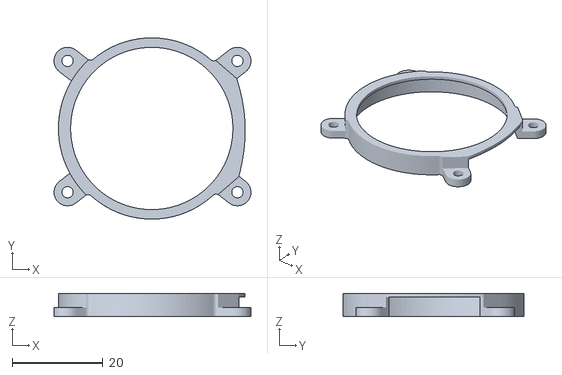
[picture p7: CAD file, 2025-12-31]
cad/Display_Holder.stl
43.5 x 40.0 x 5.13

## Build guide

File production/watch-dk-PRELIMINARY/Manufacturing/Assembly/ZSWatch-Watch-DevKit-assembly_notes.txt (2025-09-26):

ASSEMBLY NOTES (UNLESS OTHERWISE SPECIFIED)

1)	DO NOT POPULATE PARTS ARE MARKED WITH A RED CROSS.

2)	DO NOT POPULATE PARTS ARE NOT PRESENT IN THE BOM.

3)	IF CONFLICTING INFORMATION IS FOUND BETWEEN THE ASSEMBLY
	FILE AND BOM, BOM SHOULD BE USED AS THE MAIN SOURCE.

4)	CONFORMAL COATING IS NOT REQUIRED.

5)	DOT IDENTIFIES PIN #1 LOCATION AND DEVICE ORIENTATION
	WHEN VIEWED FROM THE TOP.

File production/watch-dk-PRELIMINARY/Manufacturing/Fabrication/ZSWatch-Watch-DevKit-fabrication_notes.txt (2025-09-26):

FABRICATION NOTES (UNLESS OTHERWISE SPECIFIED)

1)	FABRICATE PER IPC-6012A CLASS 2.

2)	OUTLINE DEFINED IN SEPARATE GERBER FILE WITH
	"Edge_Cuts.GBR" SUFFIX.

	DIMENSIONS OF CIRCUMSIZED RECTANGLE SHOWN ON THIS
	DRAWING FOR REFERENCE ONLY.

3)	SEE SEPARATE DRILL FILES WITH ".DRL" SUFFIX 
	FOR HOLE LOCATIONS.

	SELECTED HOLE LOCATIONS SHOWN ON THIS DRAWING 
	FOR REFERENCE ONLY.

4)	SURFACE FINISH: HAL LEAD-FREE

5)	SOLDERMASK ON BOTH SIDES OF THE BOARD SHALL 
	BE LPI, COLOR WHITE.

6)	SILK SCREEN LEGEND TO BE APPLIED PER LAYER 
	STACKUP USING BLACK NON-CONDUCTIVE EPOXY INK.

7)	ALL VIAS ARE TENTED ON BOTH SIDES UNLESS 
	SOLDERMASK OPENED IN GERBER.

8)	VENDOR SHOULD FOLLOW ROHS COMPLIANT PROCESS 
	AND Pb FREE FOR MANUFACTURING

9)	PCB MATERIAL REQUIREMENTS:

	A.	FLAMMABILITY RATING MUST MEET OR EXCEED 
		UL94V-0 REQUIREMENTS.
	B.	Tg 150 C OR EQUIVALENT.

10)	DESIGN GEOMETRY MINIMUM FEATURE SIZES:

	BOARD SIZE				100.000 × 70.000 mm
	BOARD THICKNESS		1.582 mm
	TRACE WIDTH			0.127 mm
	TRACE TO TRACE		0.125 mm
	MIN. HOLE (PTH)			0.250 mm
	MIN. HOLE (NPTH)		0.650 mm
	ANNULAR RING			0.100 mm
	COPPER TO HOLE		0.125 mm
	COPPER TO EDGE		0.125 mm
	HOLE TO HOLE			0.250 mm

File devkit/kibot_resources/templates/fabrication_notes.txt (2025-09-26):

FABRICATION NOTES (UNLESS OTHERWISE SPECIFIED)

1)	FABRICATE PER IPC-6012A CLASS 2.

2)	OUTLINE DEFINED IN SEPARATE GERBER FILE WITH
	"Edge_Cuts.GBR" SUFFIX.

	DIMENSIONS OF CIRCUMSIZED RECTANGLE SHOWN ON THIS
	DRAWING FOR REFERENCE ONLY.

3)	SEE SEPARATE DRILL FILES WITH ".DRL" SUFFIX 
	FOR HOLE LOCATIONS.

	SELECTED HOLE LOCATIONS SHOWN ON THIS DRAWING 
	FOR REFERENCE ONLY.

4)	SURFACE FINISH: ${pcb_finish_cap}

5)	SOLDERMASK ON BOTH SIDES OF THE BOARD SHALL 
	BE LPI, COLOR ${solder_mask_color_text_cap}.

6)	SILK SCREEN LEGEND TO BE APPLIED PER LAYER 
	STACKUP USING ${silk_screen_color_text_cap} NON-CONDUCTIVE EPOXY INK.

7)	ALL VIAS ARE TENTED ON BOTH SIDES UNLESS 
	SOLDERMASK OPENED IN GERBER.

8)	VENDOR SHOULD FOLLOW ROHS COMPLIANT PROCESS 
	AND Pb FREE FOR MANUFACTURING

9)	PCB MATERIAL REQUIREMENTS:

	A.	FLAMMABILITY RATING MUST MEET OR EXCEED 
		UL94V-0 REQUIREMENTS.
	B.	Tg 150 C OR EQUIVALENT.

10)	DESIGN GEOMETRY MINIMUM FEATURE SIZES:

	BOARD SIZE				${bb_w_mm} × ${bb_h_mm} mm
	BOARD THICKNESS		${thickness_mm} mm
	TRACE WIDTH			${track_mm} mm
	TRACE TO TRACE		${clearance_mm} mm
	MIN. HOLE (PTH)			${drill_pth_real_mm} mm
	MIN. HOLE (NPTH)		${drill_npth_real_mm} mm
	ANNULAR RING			${oar_mm} mm
	COPPER TO HOLE		${c2h_mm} mm
	COPPER TO EDGE		${c2e_mm} mm
	HOLE TO HOLE			${h2h_mm} mm
#?stackup and impedance_controlled

#?stackup and impedance_controlled
11)	REFER TO IMPEDANCE TABLE FOR IMPEDANCE CONTROL REQUIREMENTS.
#?stackup and impedance_controlled

#?stackup and impedance_controlled
12)	CONFIRM SPACE WIDTHS AND SPACINGS.

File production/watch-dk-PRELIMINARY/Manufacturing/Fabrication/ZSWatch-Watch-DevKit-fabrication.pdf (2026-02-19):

# Top Fabrication (Scale 1:1)

# Watch-DevKit-HW Fabrication Document

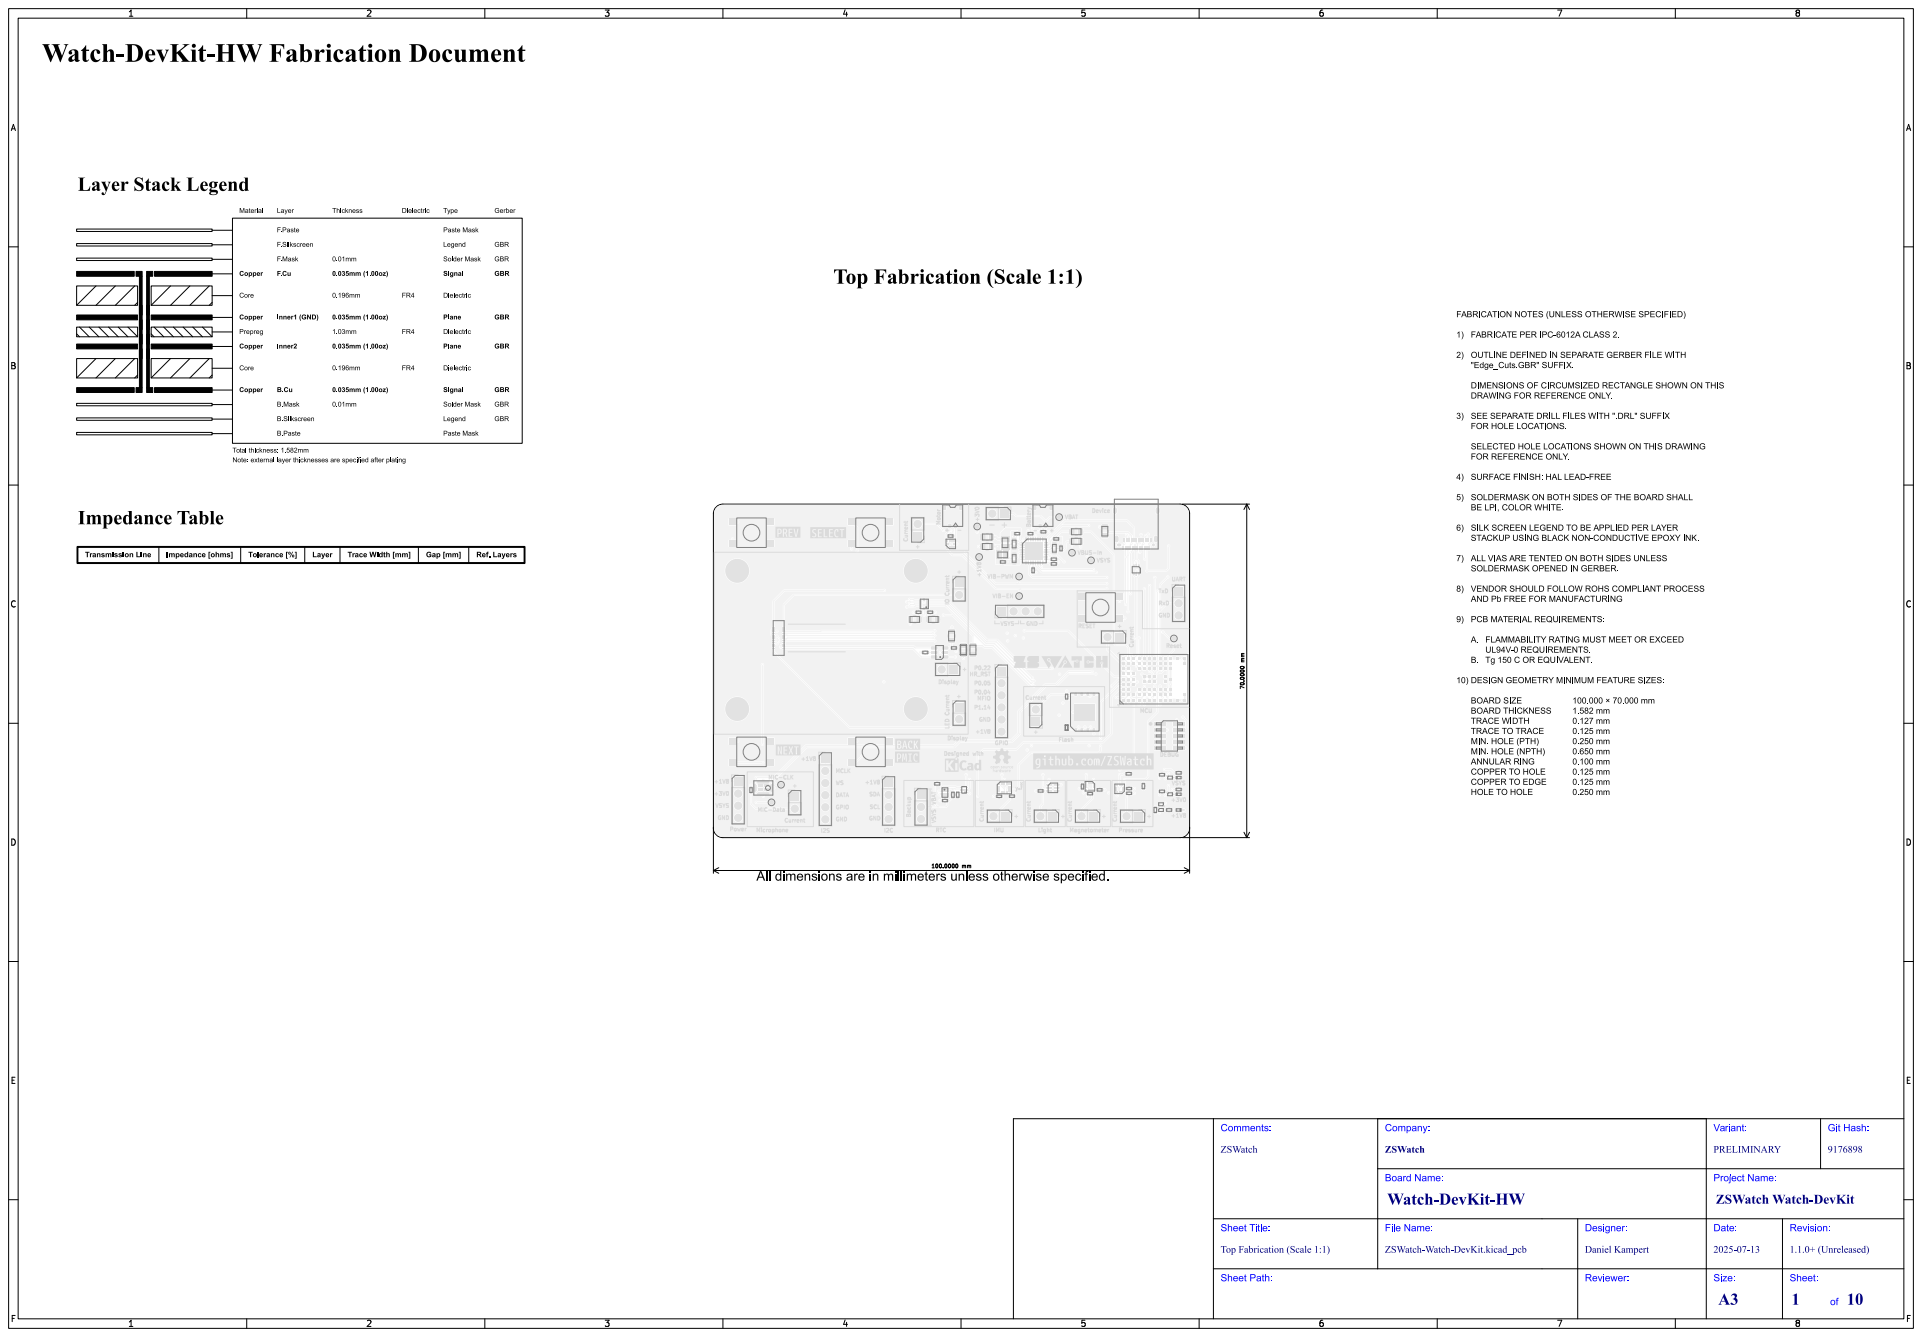
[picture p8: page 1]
Git Hash:; ZSWatch; Comments:; Sheet Path:; Sheet Title:; File Name:; Watch-DevKit-HW; ZSWatch Watch-DevKit; Company:; PRELIMINARY; Variant:; Board Name:; ZSWatch-Watch-DevKit.kicad_pcb; Daniel Kampert; Designer:; Reviewer:; Project Name:; Date:; 1.1.0+ (Unreleased); Revision:; Size:; Sheet:; Current; RESET; VSYS; VBUS-In; VBAT; GPIO; MIC-Data; Display; MIC-CLK; Reset; Device; VIB-EN; Battery; UART; IO Current; Power; LED Current; Motor; DEBUG; VIB-PWM; HR_RST; DATA; Pressure; GND; Flash; RxD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

Top Fabrication (Scale 1:1)

# Bottom Fabrication (Scale 1:1)

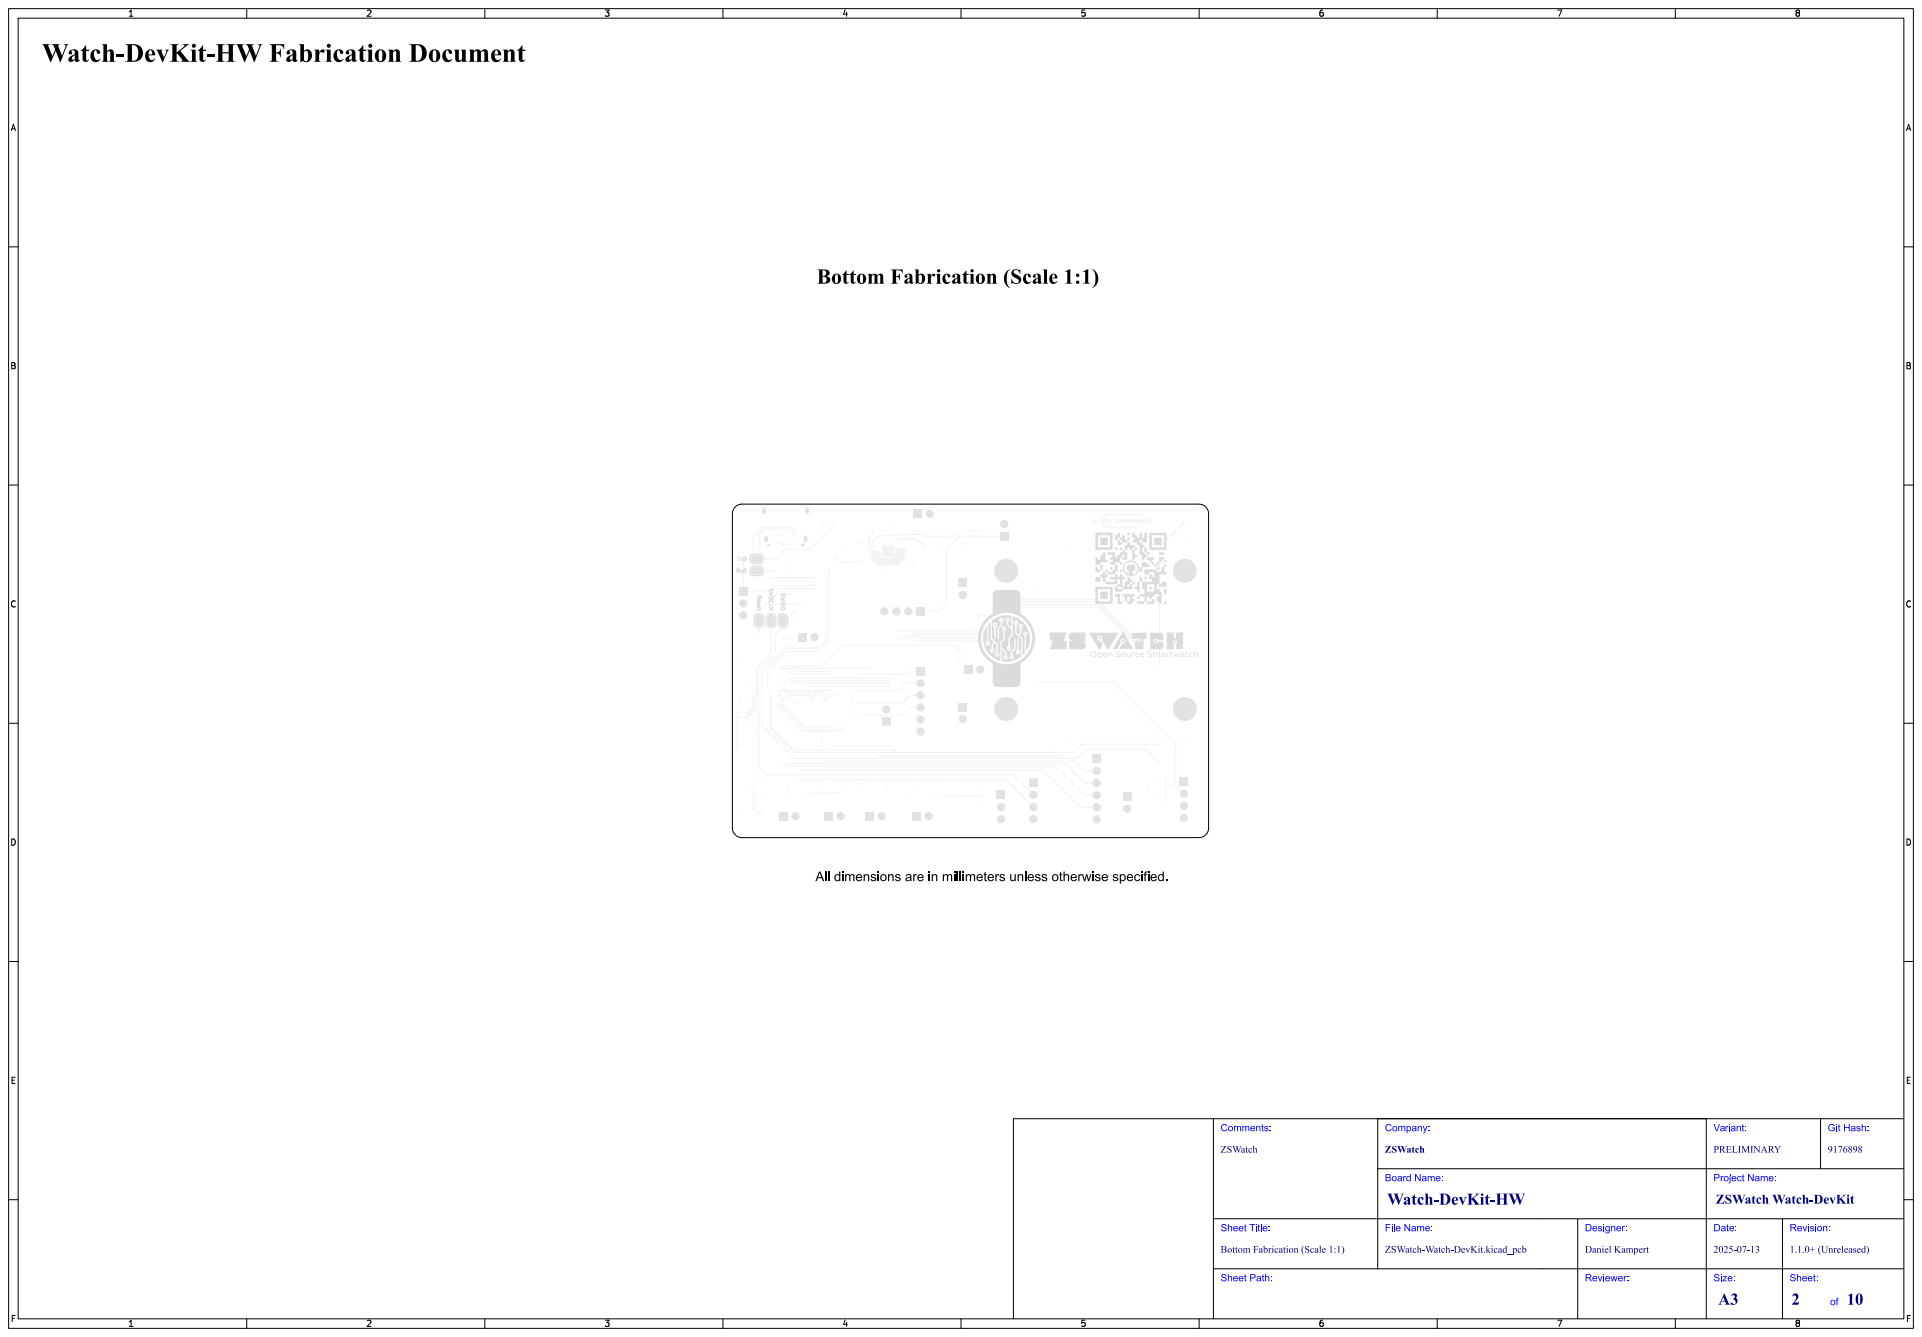
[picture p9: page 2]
Git; Hash:; ZSWatch; Comments:; Sheet Title:; File Name:; Watch-DevKit-HW; ZSWatch Watch-DevKit; Company:; PRELIMINARY; Variant:; Board Name:; ZSWatch-Watch-DevKit.kicad_pcb; Daniel Kampert; Designer:; Project Name:; Date:; 1.1.0+ (Unreleased); Revision:; 8 Reset; SWDIO; TxD; SWDCLK; RxD

Bottom Fabrication (Scale 1:1)

# Drill Drawing L1 - L4 (Scale 1:1)

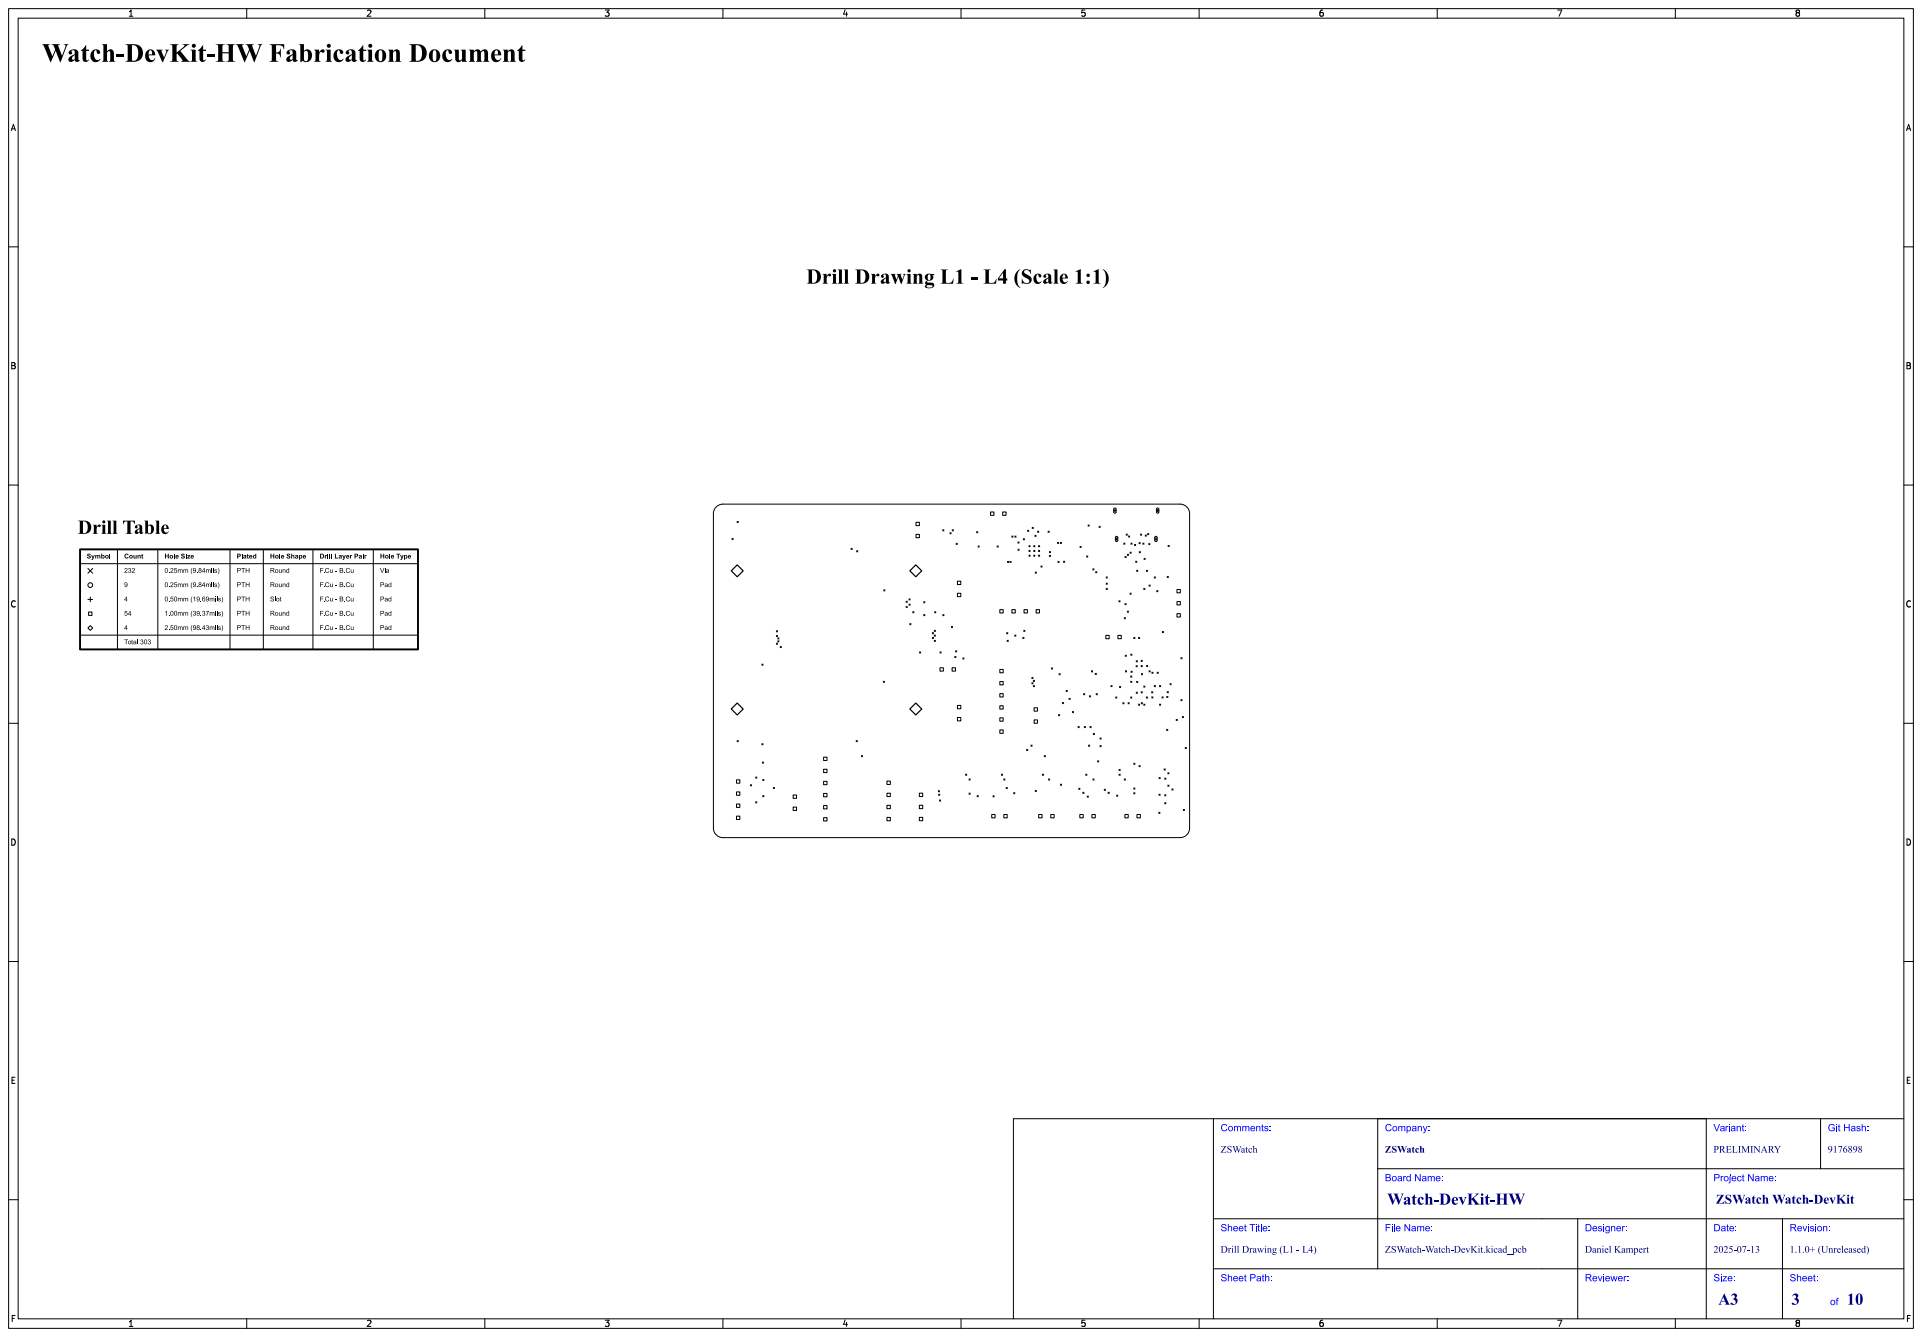
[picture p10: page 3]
Git; Hash:; ZSWatch; Comments:; Drill Drawing (L1 - L4); Sheet Title:; File Name:; Watch-DevKit-HW; ZSWatch Watch-DevKit; Company:; PRELIMINARY; Variant:; Board Name:; ZSWatch-Watch-DevKit.kicad_pcb; Daniel Kampert; Designer:; Project Name:; Date:; 1.1.0+ (Unreleased); Revision:

# Drill Drawing L1 - L4 (Scale 1:1)

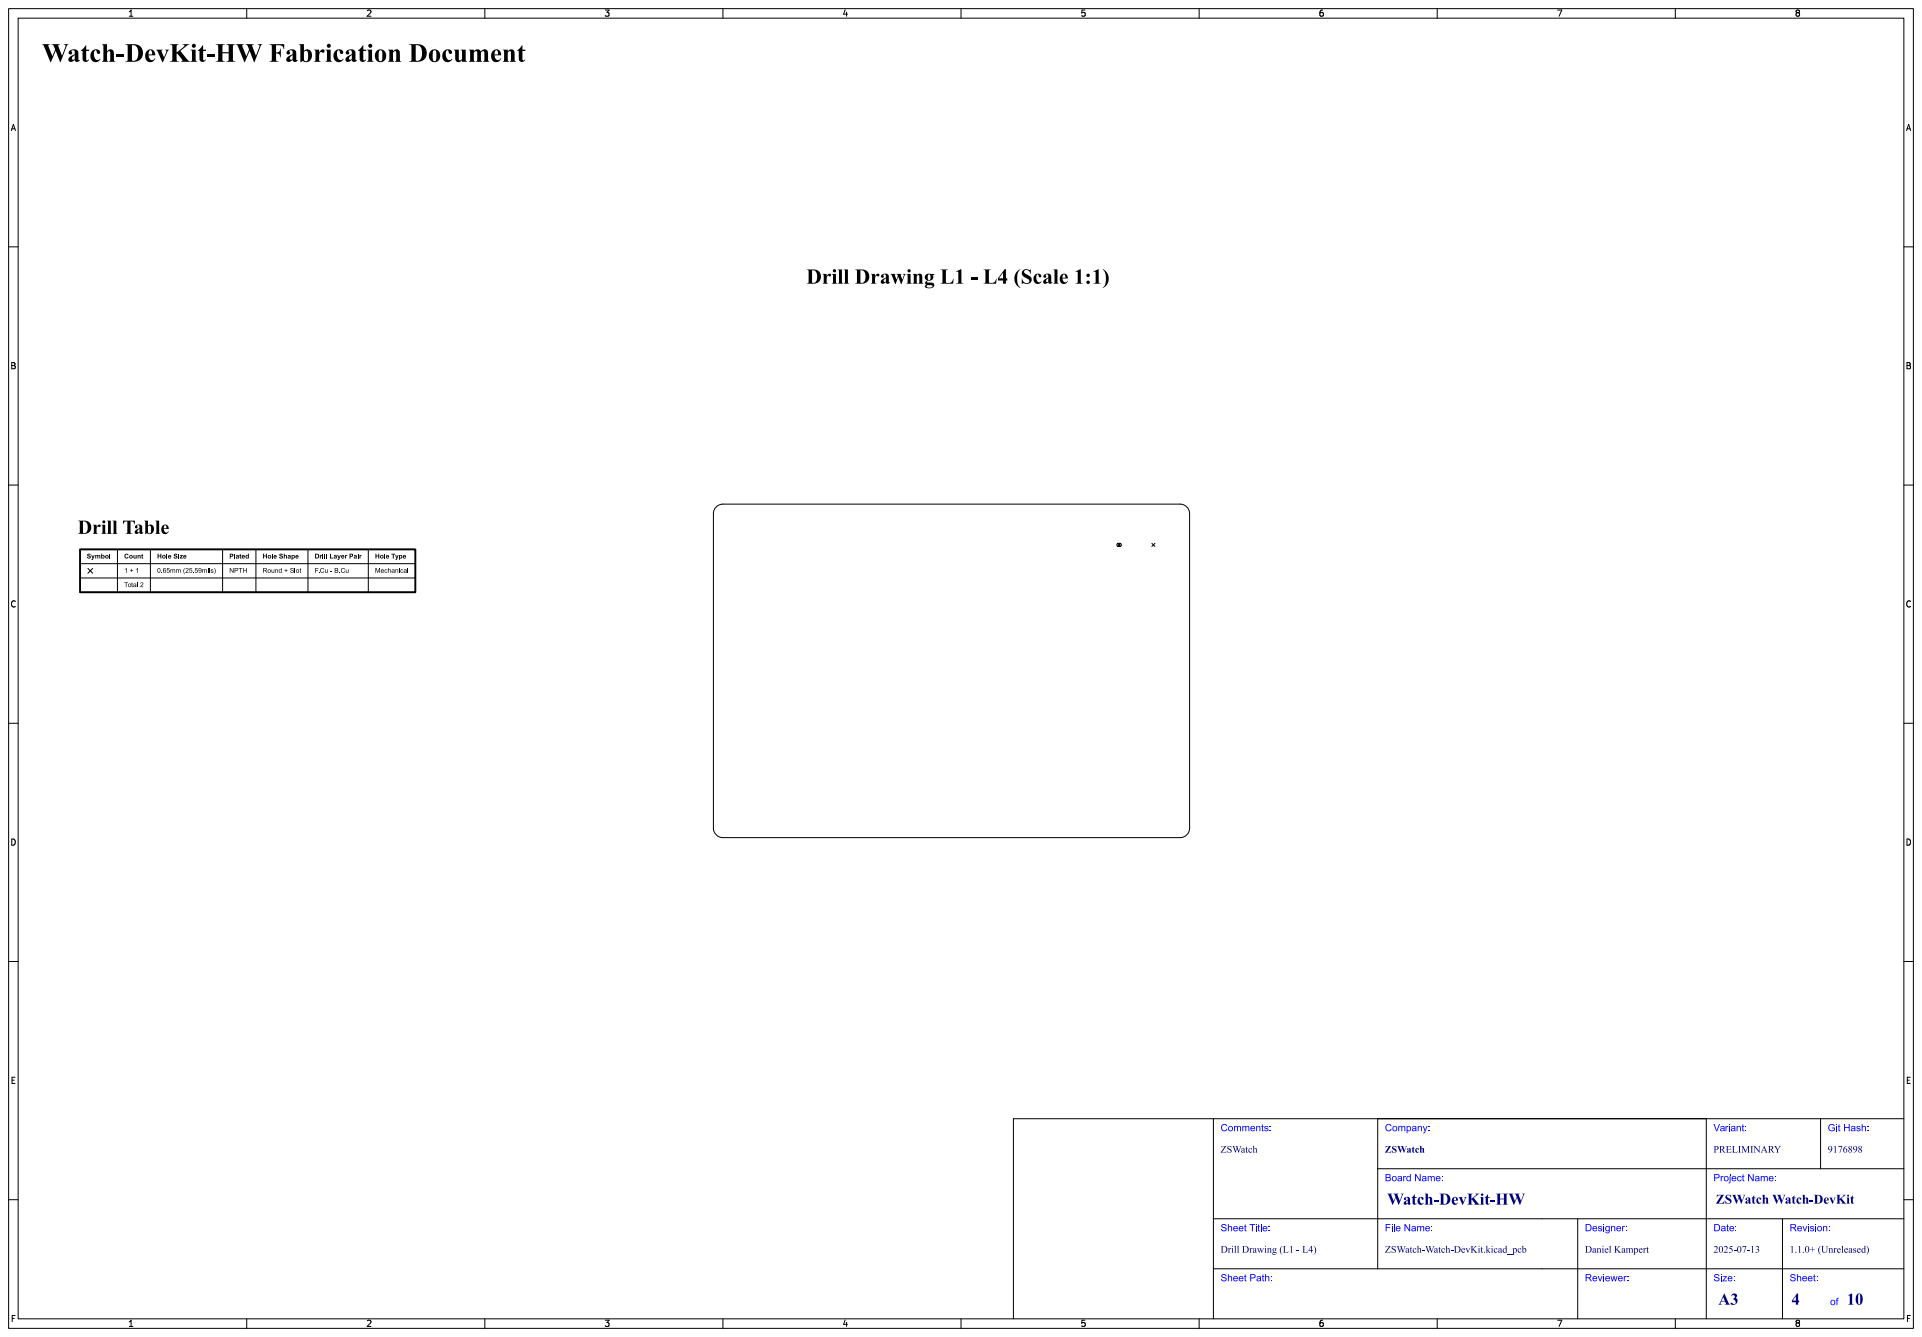
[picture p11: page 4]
Git; Hash:; ZSWatch; Comments:; Drill Drawing (L1 - L4); Sheet Title:; File Name:; Watch-DevKit-HW; ZSWatch Watch-DevKit; Company:; PRELIMINARY; Variant:; Board Name:; ZSWatch-Watch-DevKit.kicad_pcb; Daniel Kampert; Designer:; Project Name:; Date:; 1.1.0+ (Unreleased); Revision:

# Top Test Points (Scale 1:1)

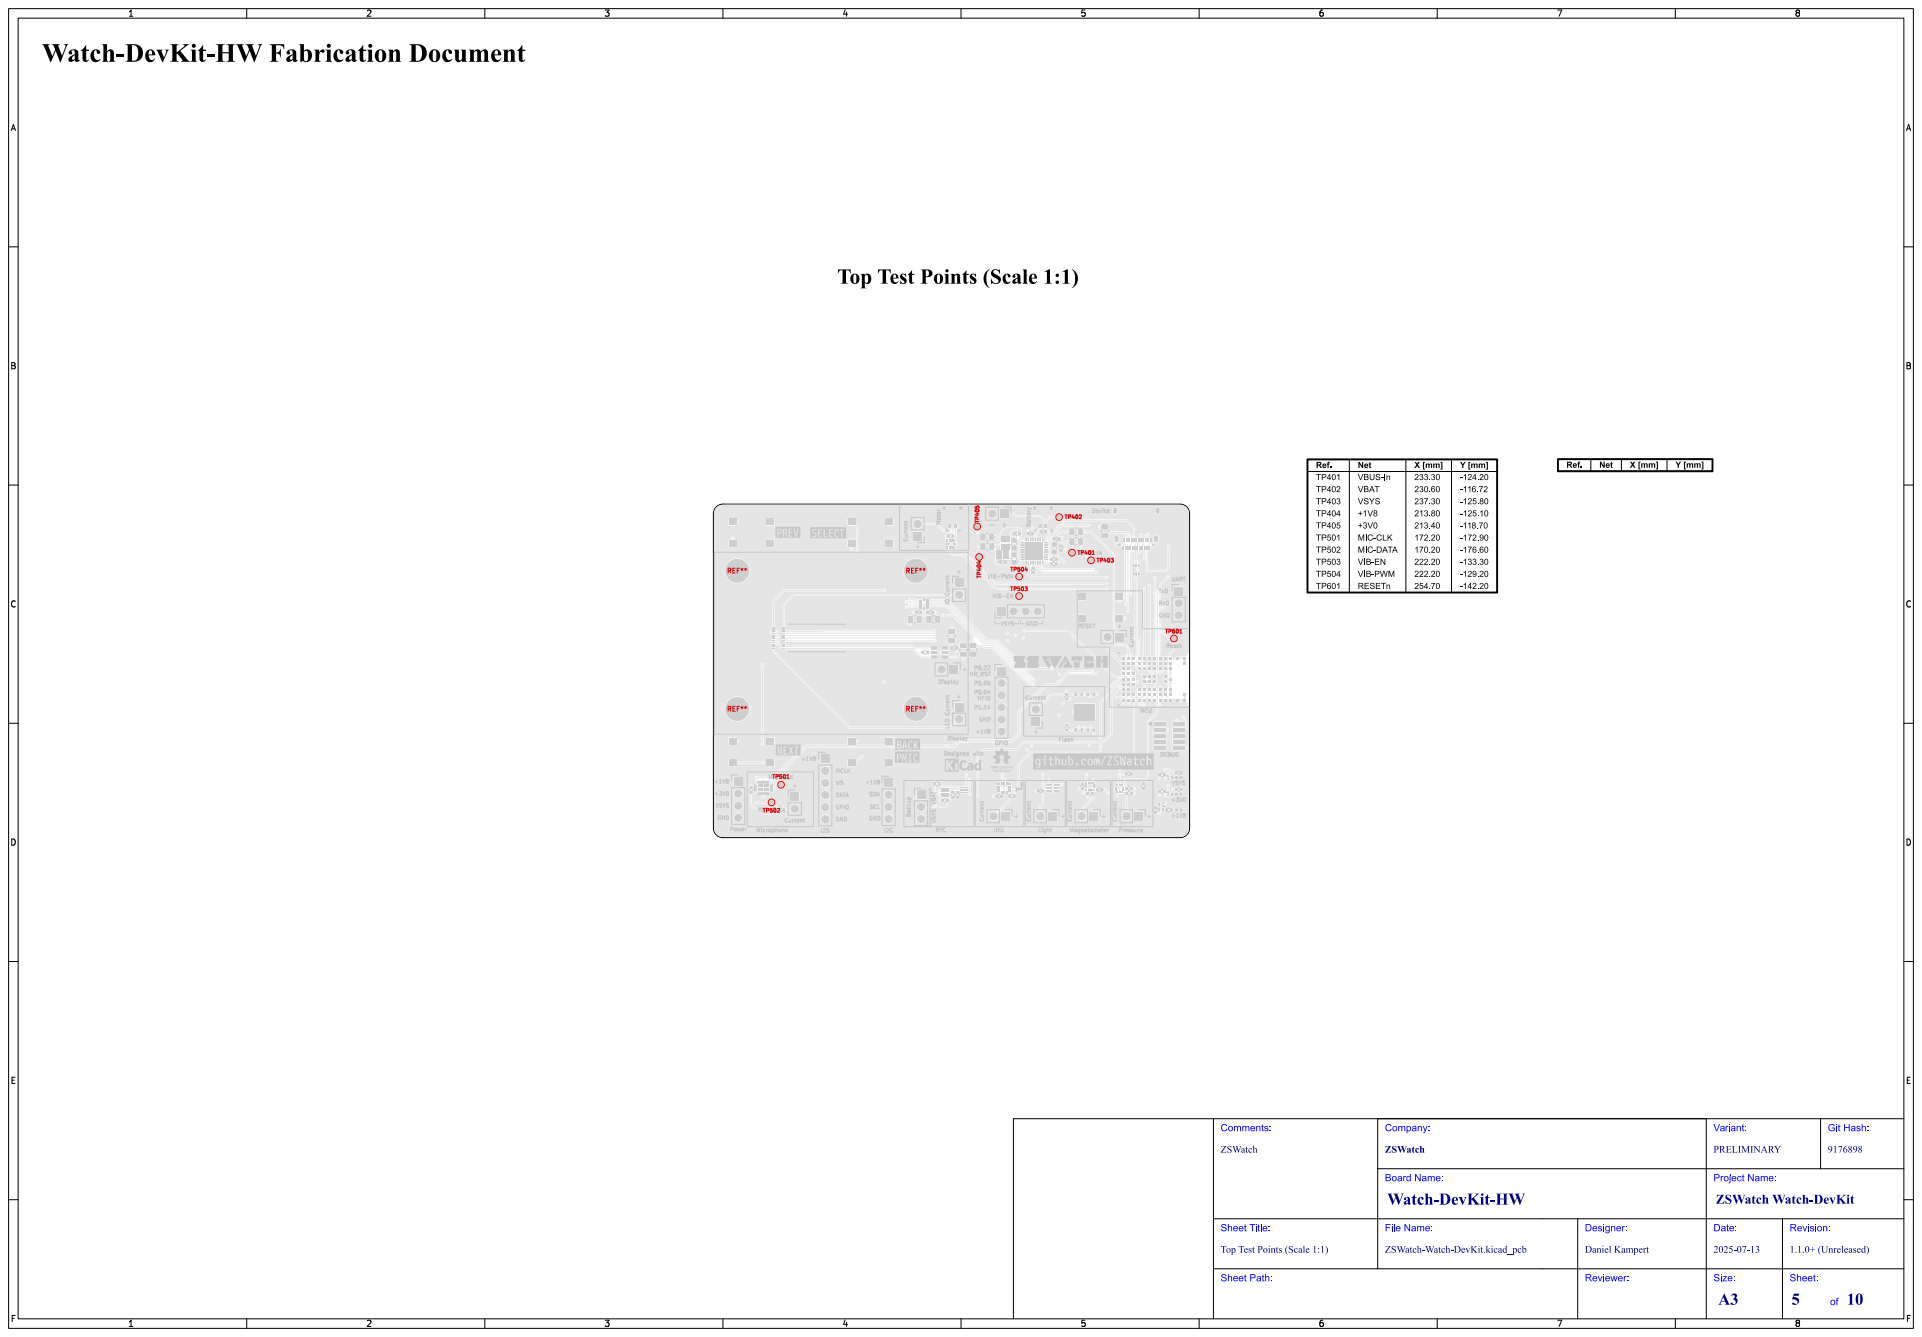
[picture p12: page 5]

Top Test Points (Scale 1:1)

# Bottom Test Points (Scale 1:1)

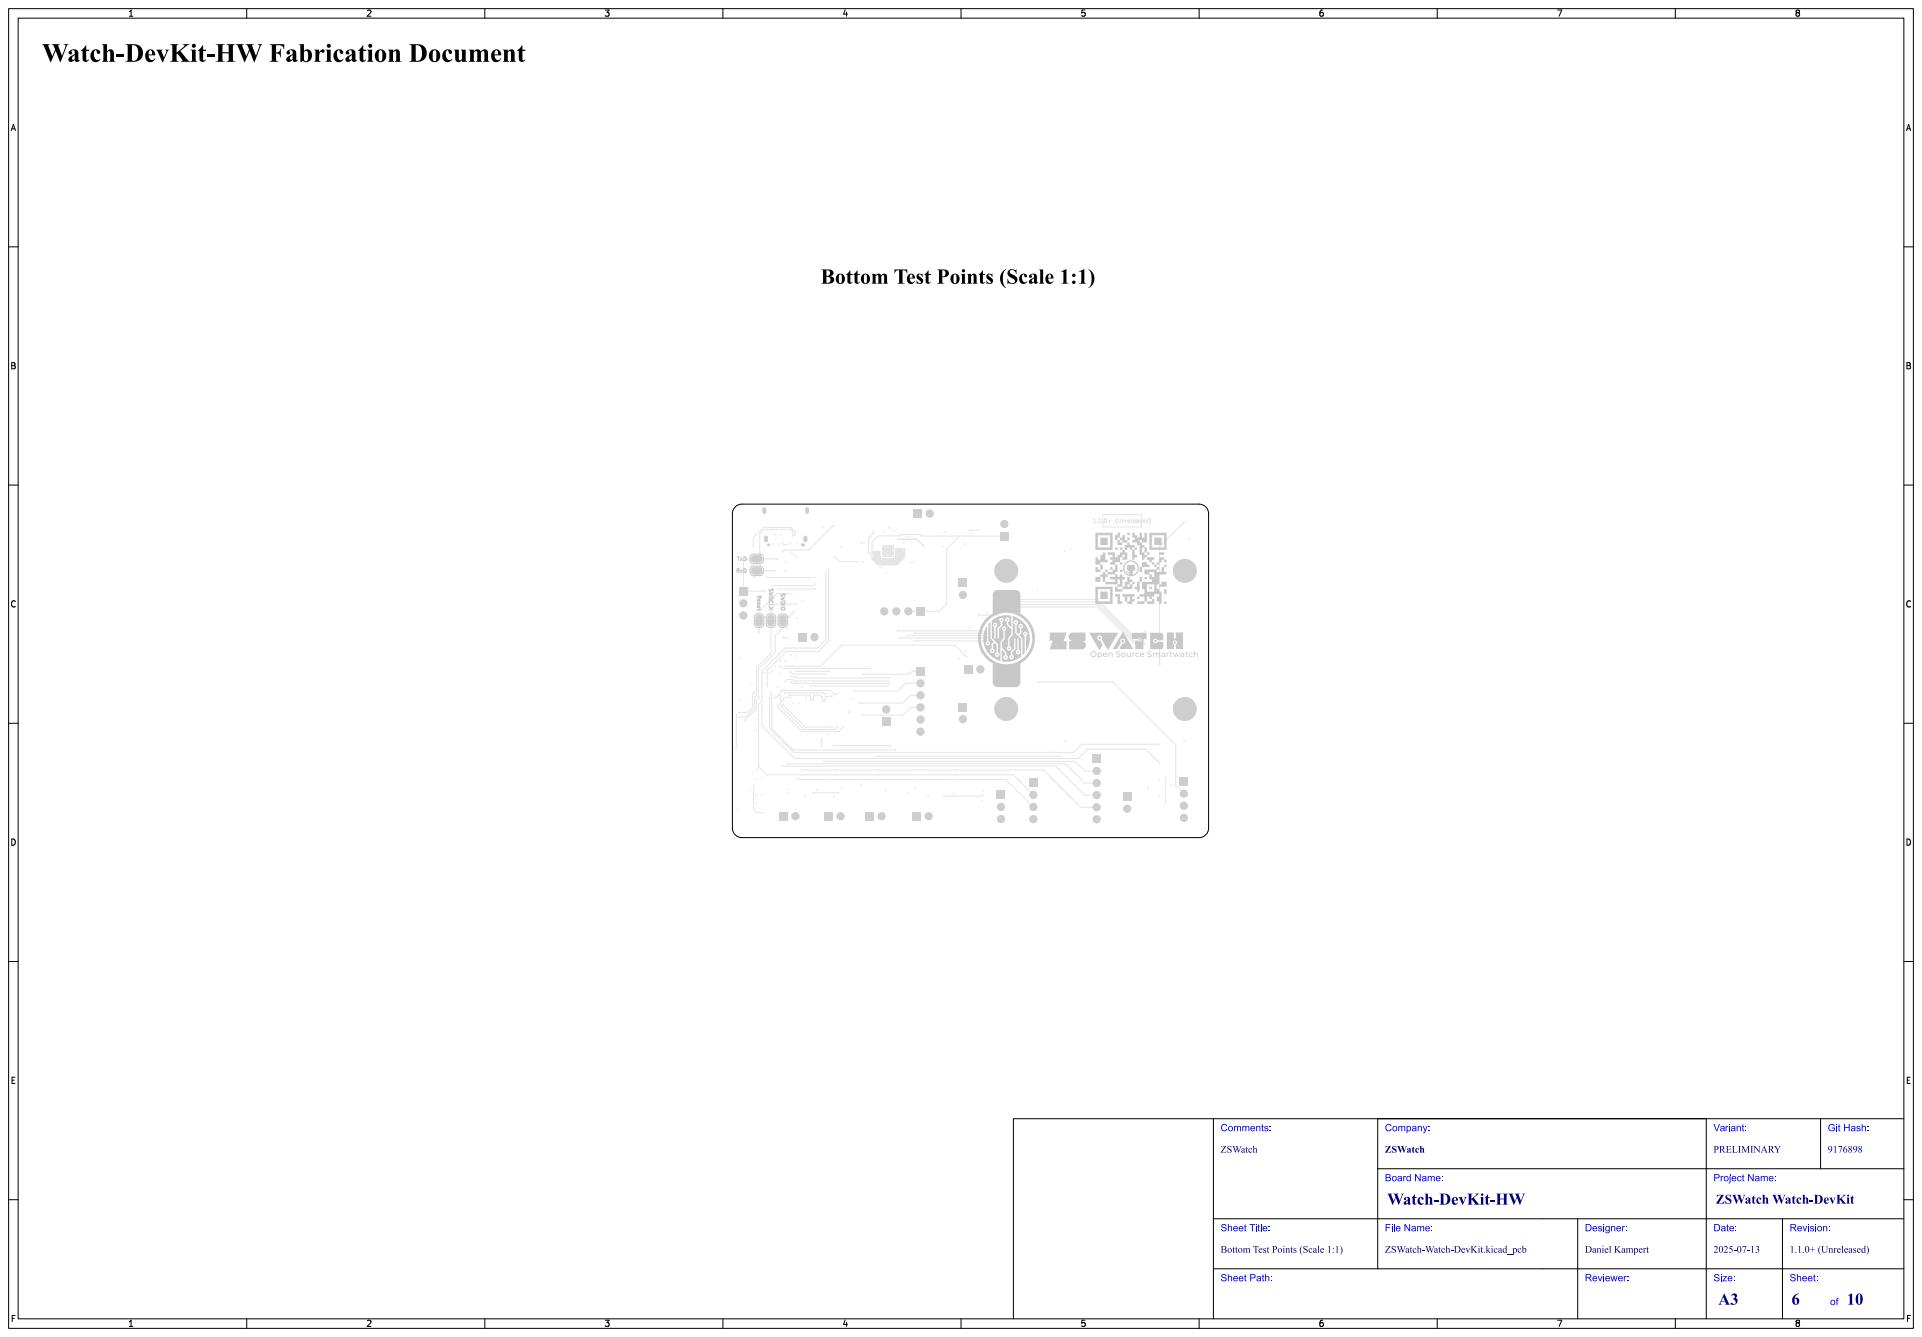
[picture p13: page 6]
Git; Hash:; ZSWatch; Comments:; Sheet Title:; File Name:; Watch-DevKit-HW; ZSWatch Watch-DevKit; Company:; PRELIMINARY; Variant:; Board Name:; ZSWatch-Watch-DevKit.kicad_pcb; Daniel Kampert; Designer:; Project Name:; Date:; 1.1.0+ (Unreleased); Revision:; 8 Reset; SWDIO; TxD; SWDCLK; RxD

Bottom Test Points (Scale 1:1)

# F.Cu (Scale 1:1)

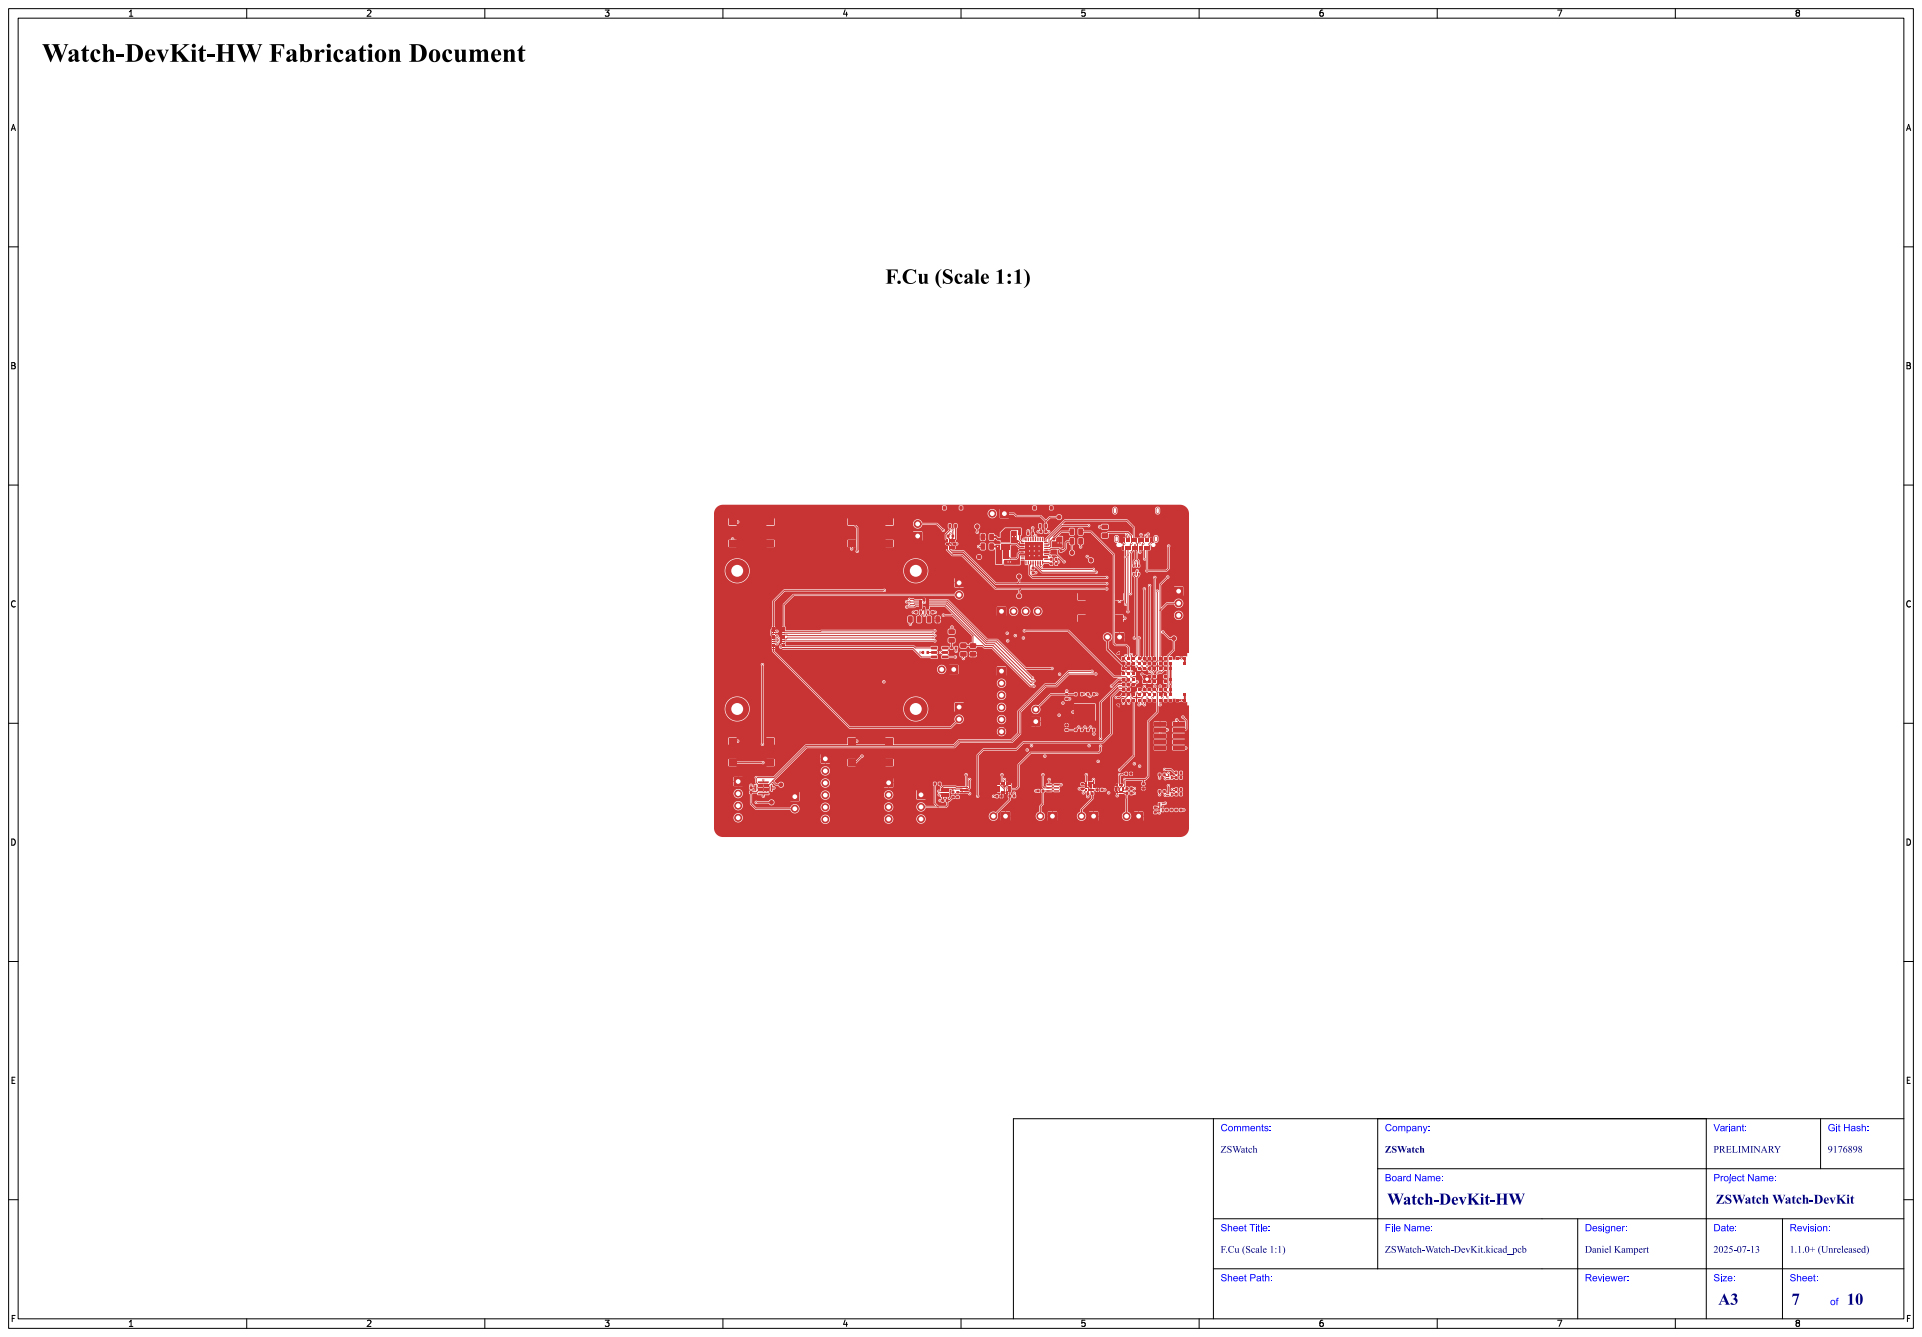
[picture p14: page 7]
Git; Hash:; ZSWatch; Comments:; F.Cu (Scale 1:1); Sheet Title:; File Name:; Watch-DevKit-HW; ZSWatch Watch-DevKit; Company:; PRELIMINARY; Variant:; Board Name:; ZSWatch-Watch-DevKit.kicad_pcb; Daniel Kampert; Designer:; Project Name:; Date:; 1.1.0+ (Unreleased); Revision:

# Inner1 (GND) (Scale 1:1)

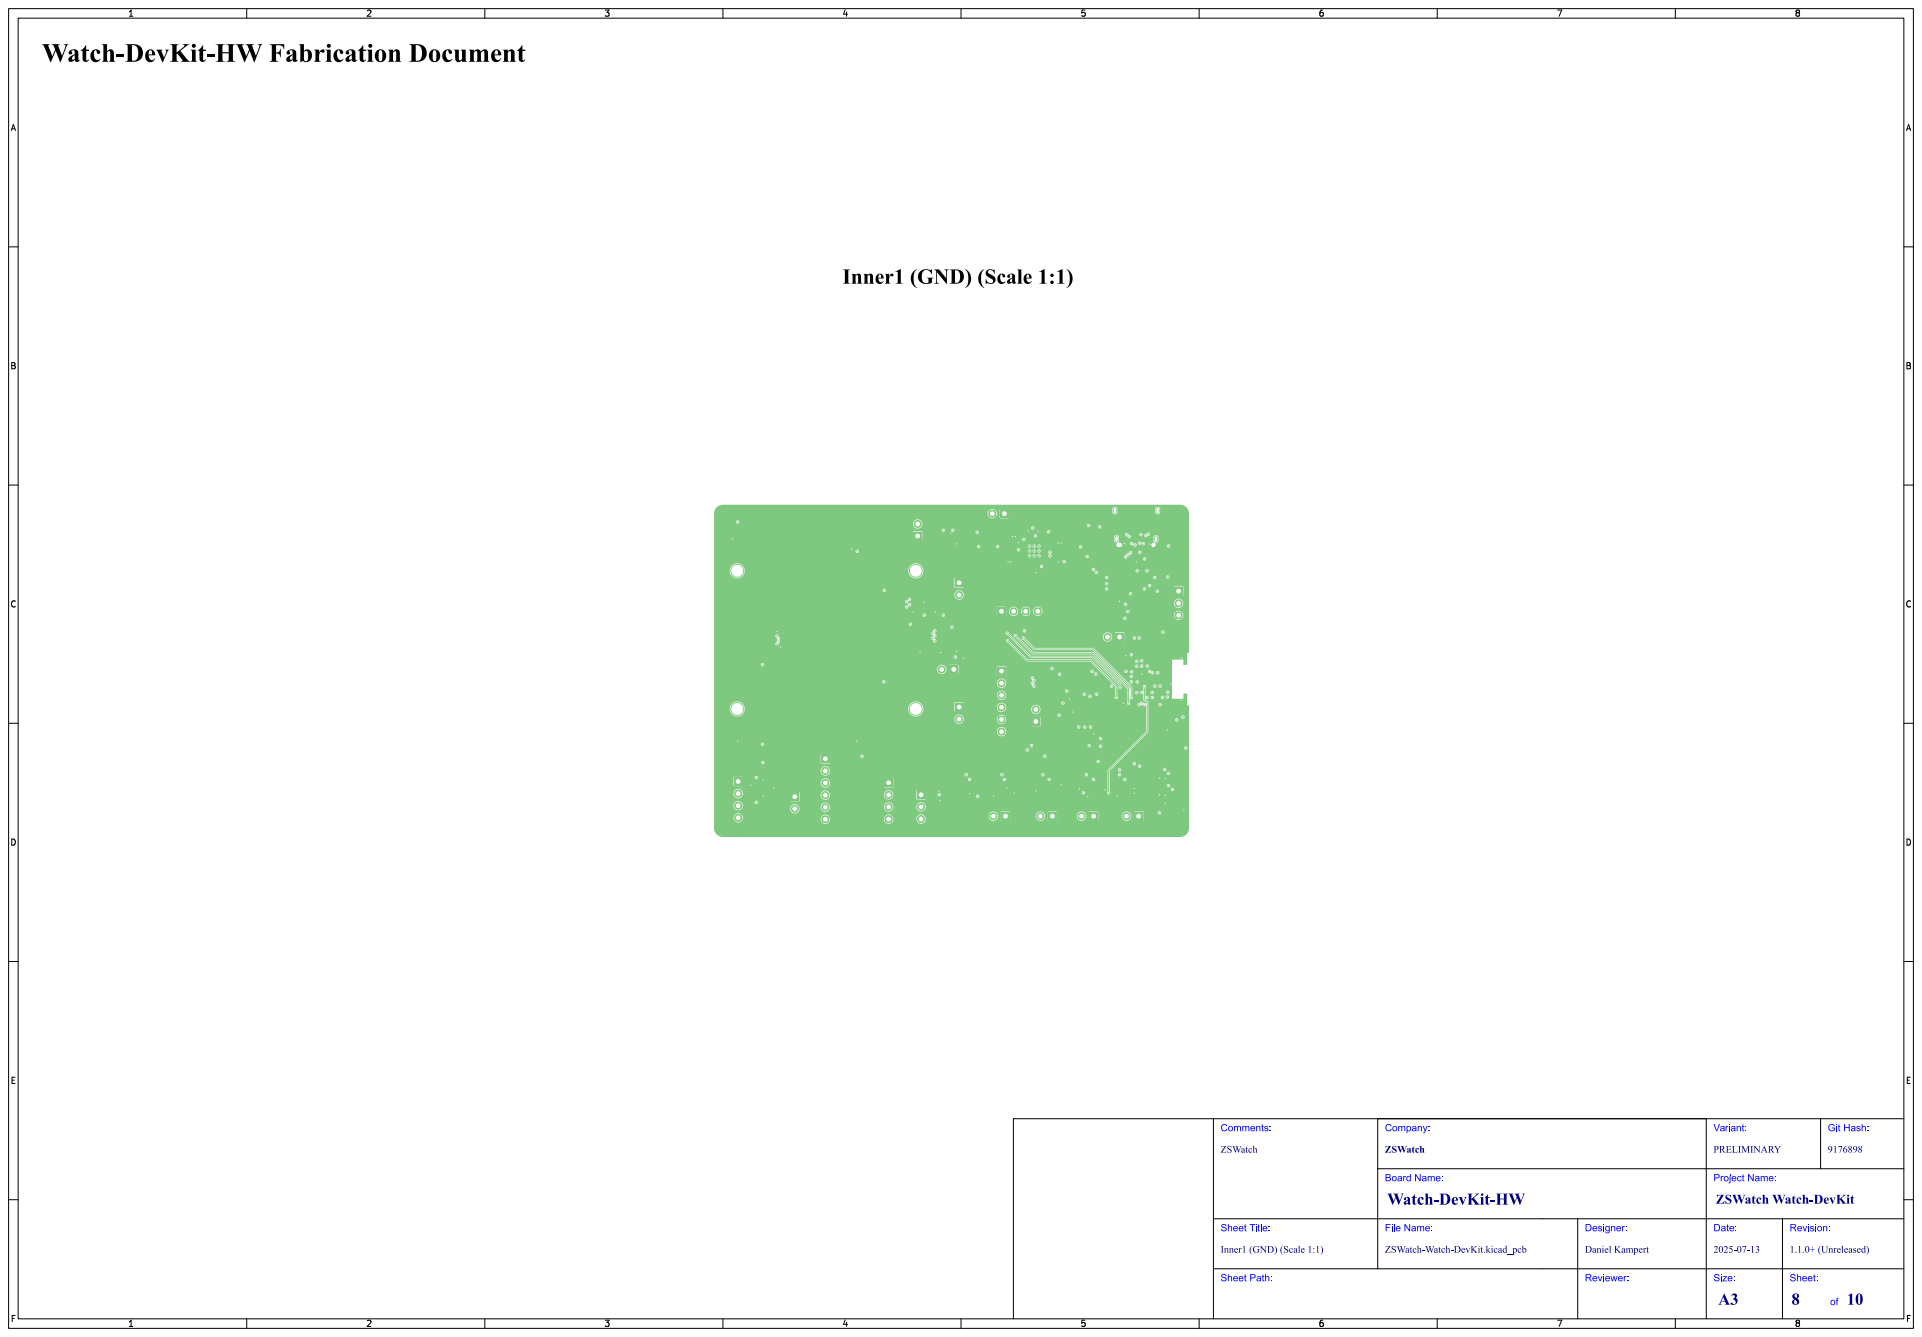
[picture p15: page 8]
Git; Hash:; ZSWatch; Comments:; Inner1 (GND) (Scale 1:1); Sheet Title:; File Name:; Watch-DevKit-HW; ZSWatch Watch-DevKit; Company:; PRELIMINARY; Variant:; Board Name:; ZSWatch-Watch-DevKit.kicad_pcb; Daniel Kampert; Designer:; Project Name:; Date:; 1.1.0+ (Unreleased); Revision:

# Inner2 (Scale 1:1)

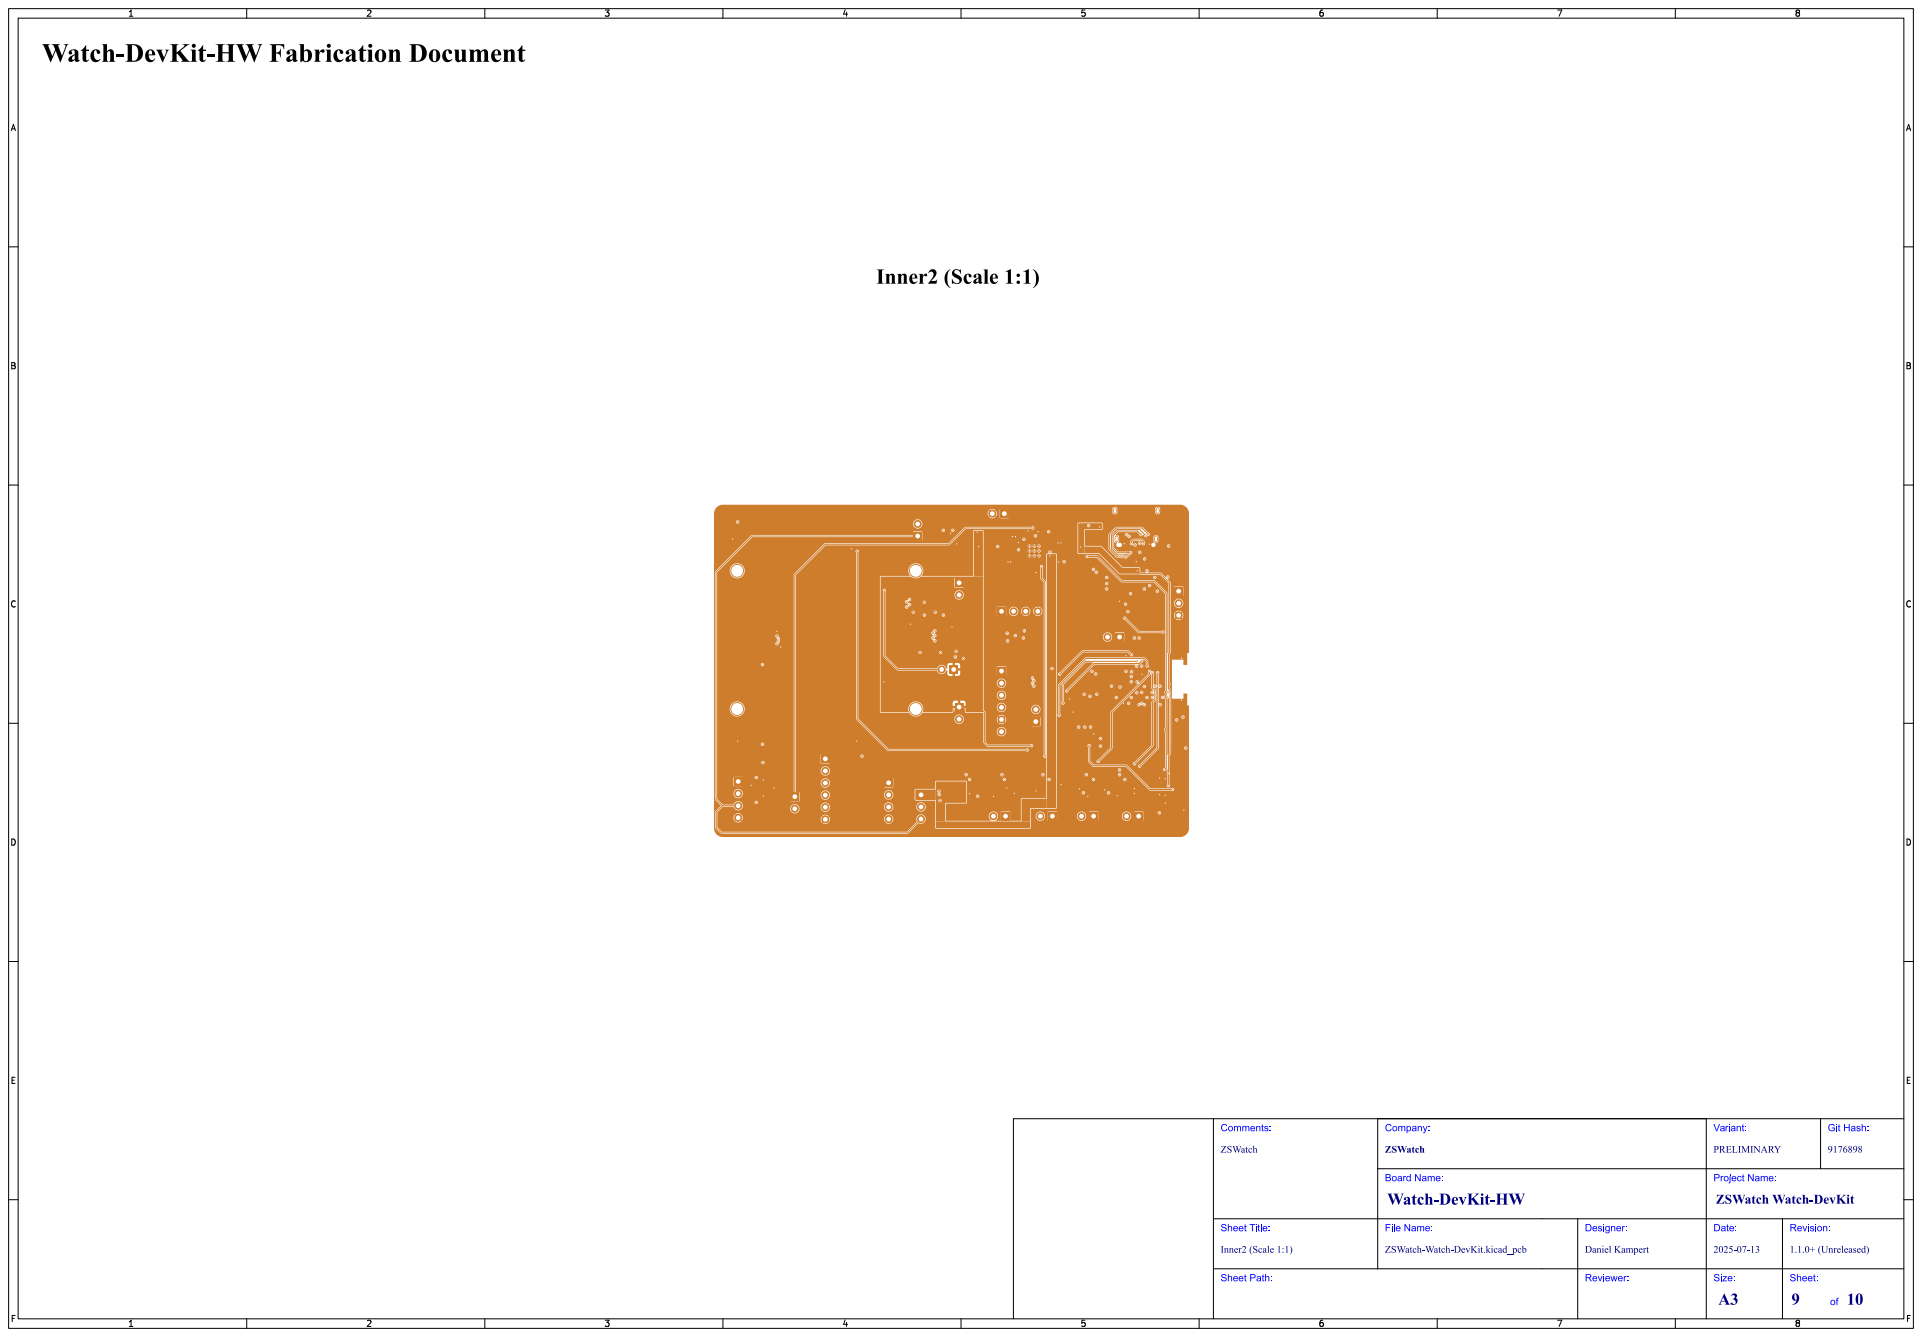
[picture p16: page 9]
Git; Hash:; ZSWatch; Comments:; Inner2 (Scale 1:1); Sheet Title:; File Name:; Watch-DevKit-HW; ZSWatch Watch-DevKit; Company:; PRELIMINARY; Variant:; Board Name:; ZSWatch-Watch-DevKit.kicad_pcb; Daniel Kampert; Designer:; Project Name:; Date:; 1.1.0+ (Unreleased); Revision:

# B.Cu (Scale 1:1)

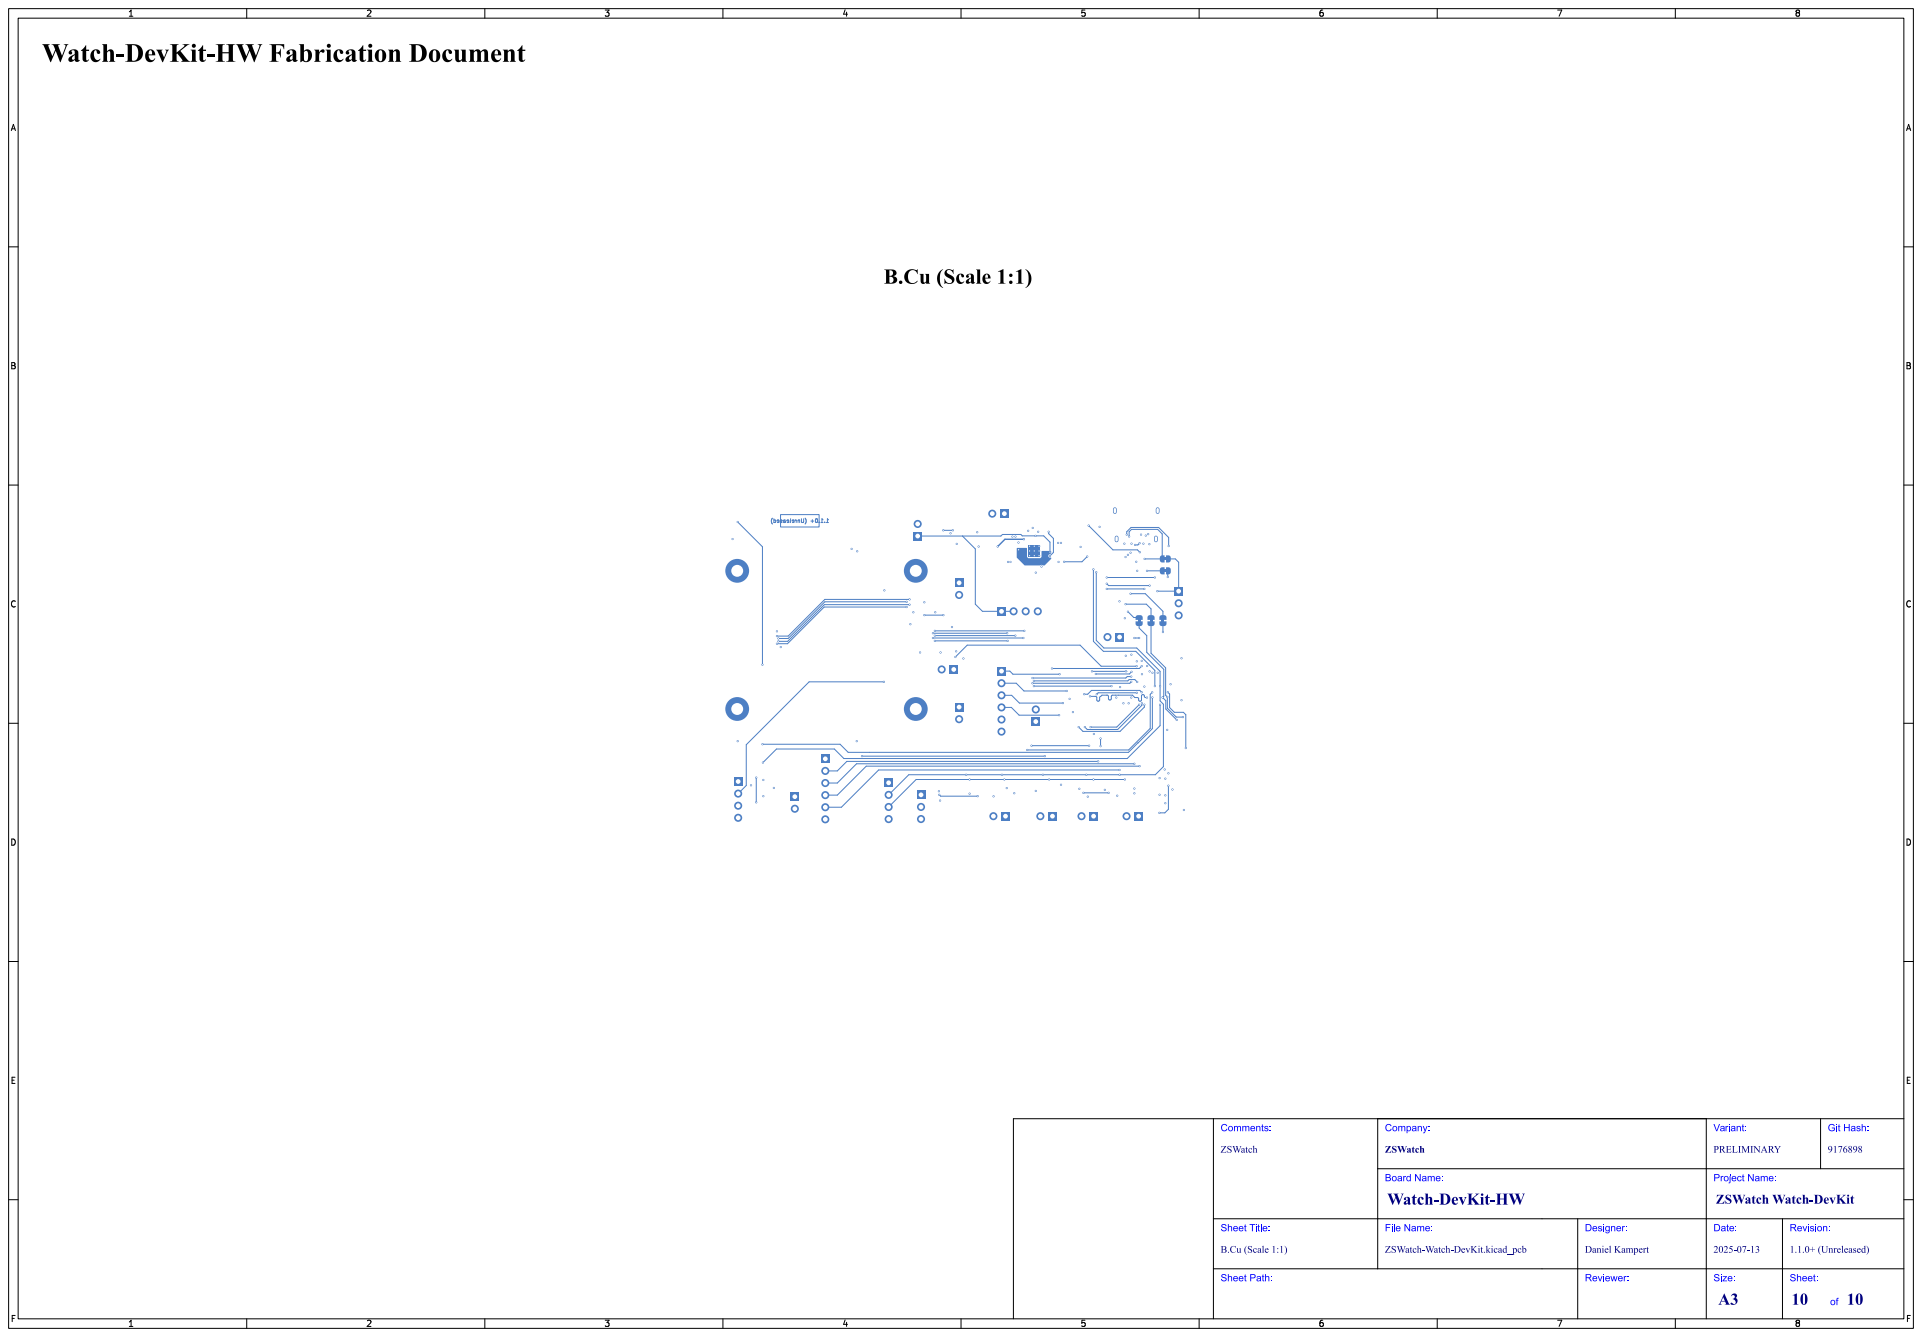
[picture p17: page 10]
Git; Hash:; ZSWatch; Comments:; B.Cu (Scale 1:1); Sheet Title:; File Name:; Watch-DevKit-HW; ZSWatch Watch-DevKit; Company:; PRELIMINARY; Variant:; Board Name:; ZSWatch-Watch-DevKit.kicad_pcb; Daniel Kampert; Designer:; Project Name:; Date:; 1.1.0+ (Unreleased); Revision:

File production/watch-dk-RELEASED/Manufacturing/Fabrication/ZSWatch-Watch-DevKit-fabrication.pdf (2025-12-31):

# Top Fabrication (Scale 1:1)

# Watch-DevKit-HW Fabrication Document

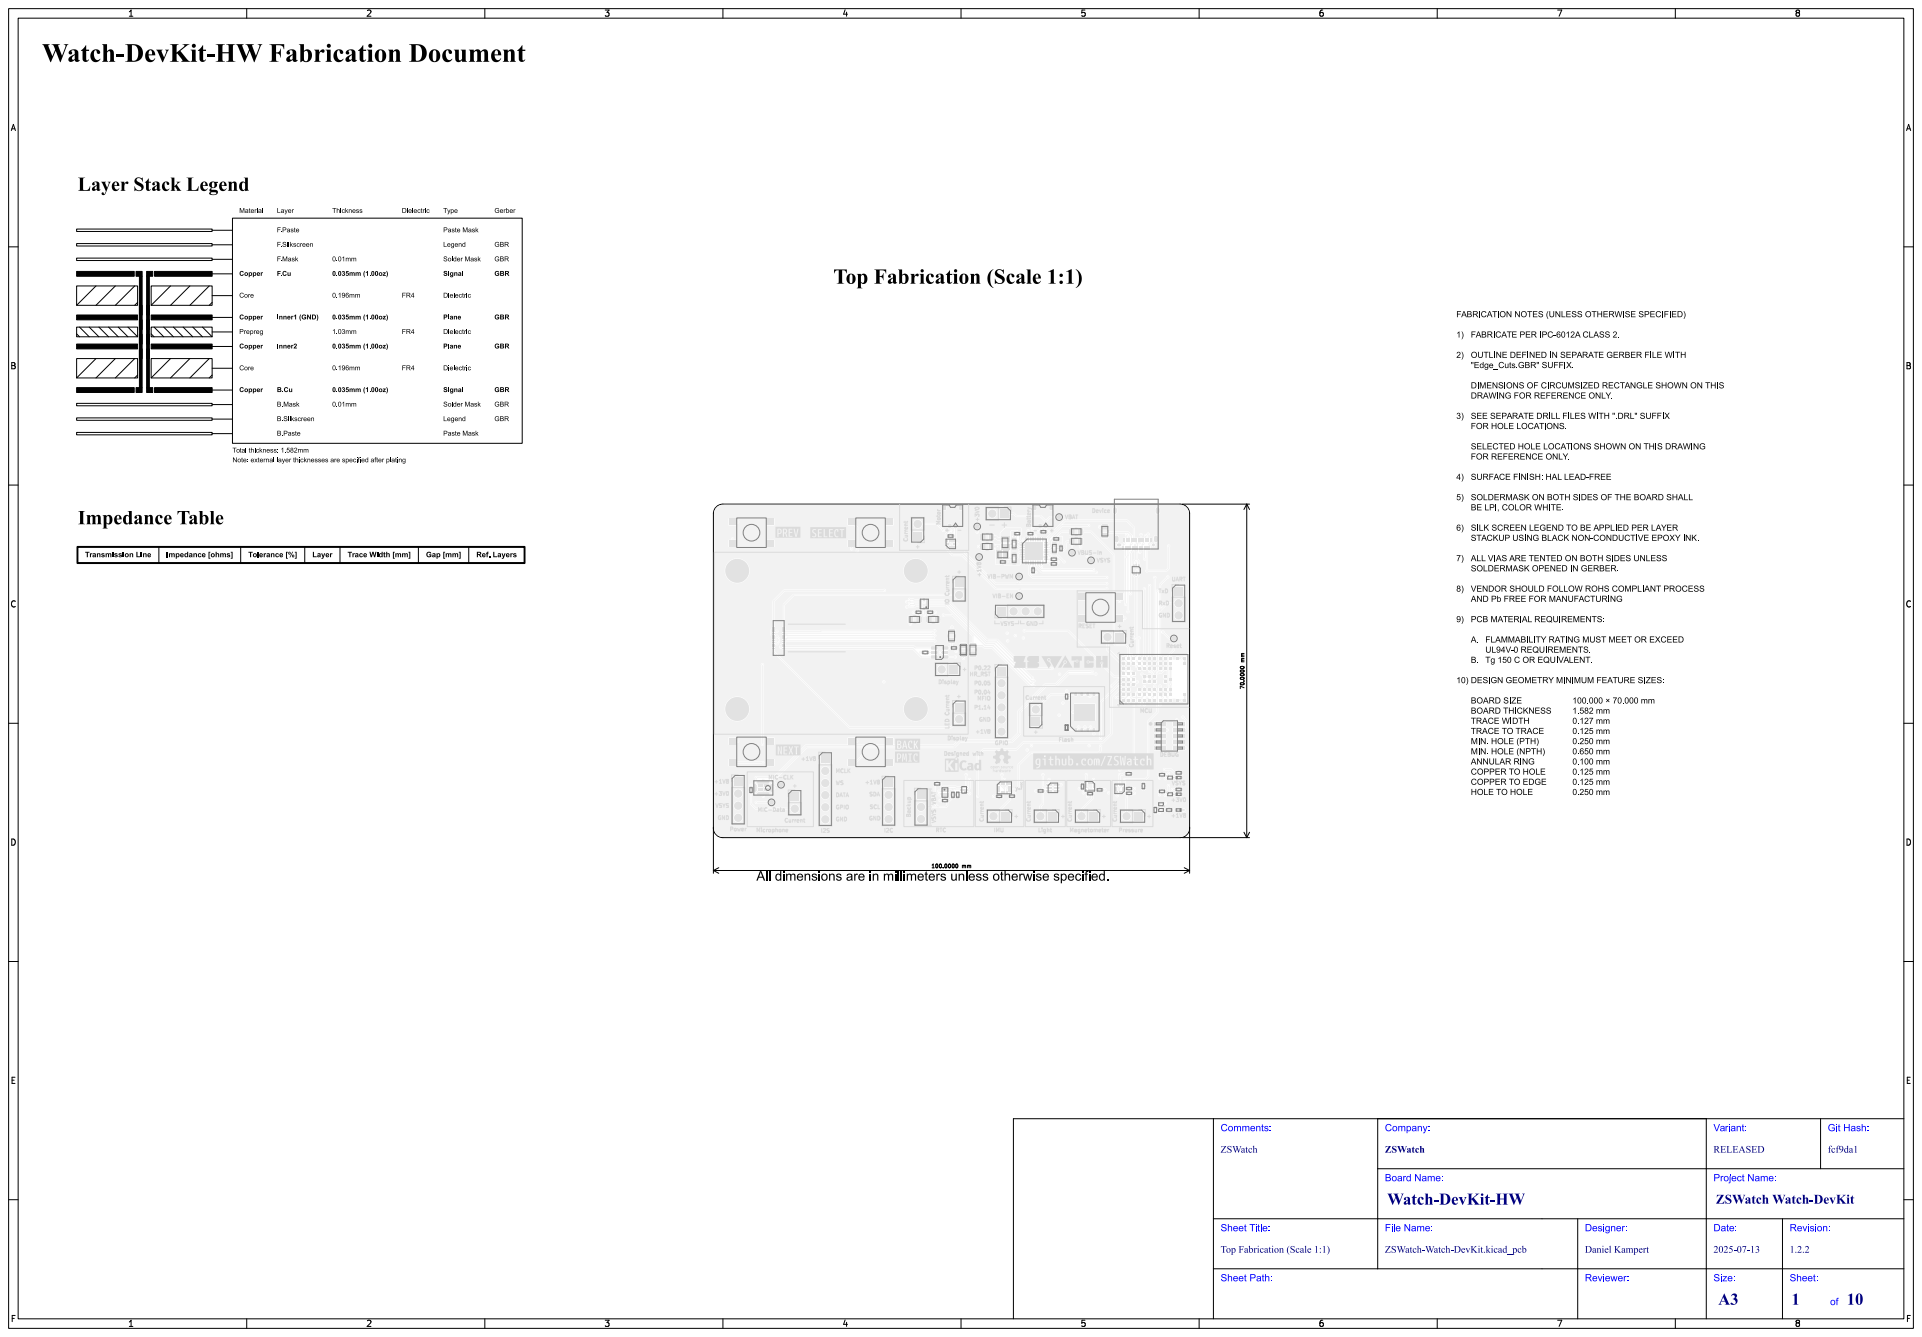
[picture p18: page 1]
Git Hash:; fcf9da1; ZSWatch; Comments:; Sheet Path:; Sheet Title:; File Name:; Watch-DevKit-HW; ZSWatch Watch-DevKit; Company:; RELEASED; Variant:; Board Name:; ZSWatch-Watch-DevKit.kicad_pcb; Daniel Kampert; Designer:; Reviewer:; Project Name:; Date:; Revision:; Size:; Sheet:; Current; RESET; VSYS; VBUS-In; VBAT; GPIO; MIC-Data; Display; MIC-CLK; Reset; Device; VIB-EN; Battery; UART; IO Current; Power; LED Current; Motor; DEBUG; VIB-PWM; HR_RST; DATA; Pressure; GND; Flash; RxD; Light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

Top Fabrication (Scale 1:1)

# Bottom Fabrication (Scale 1:1)

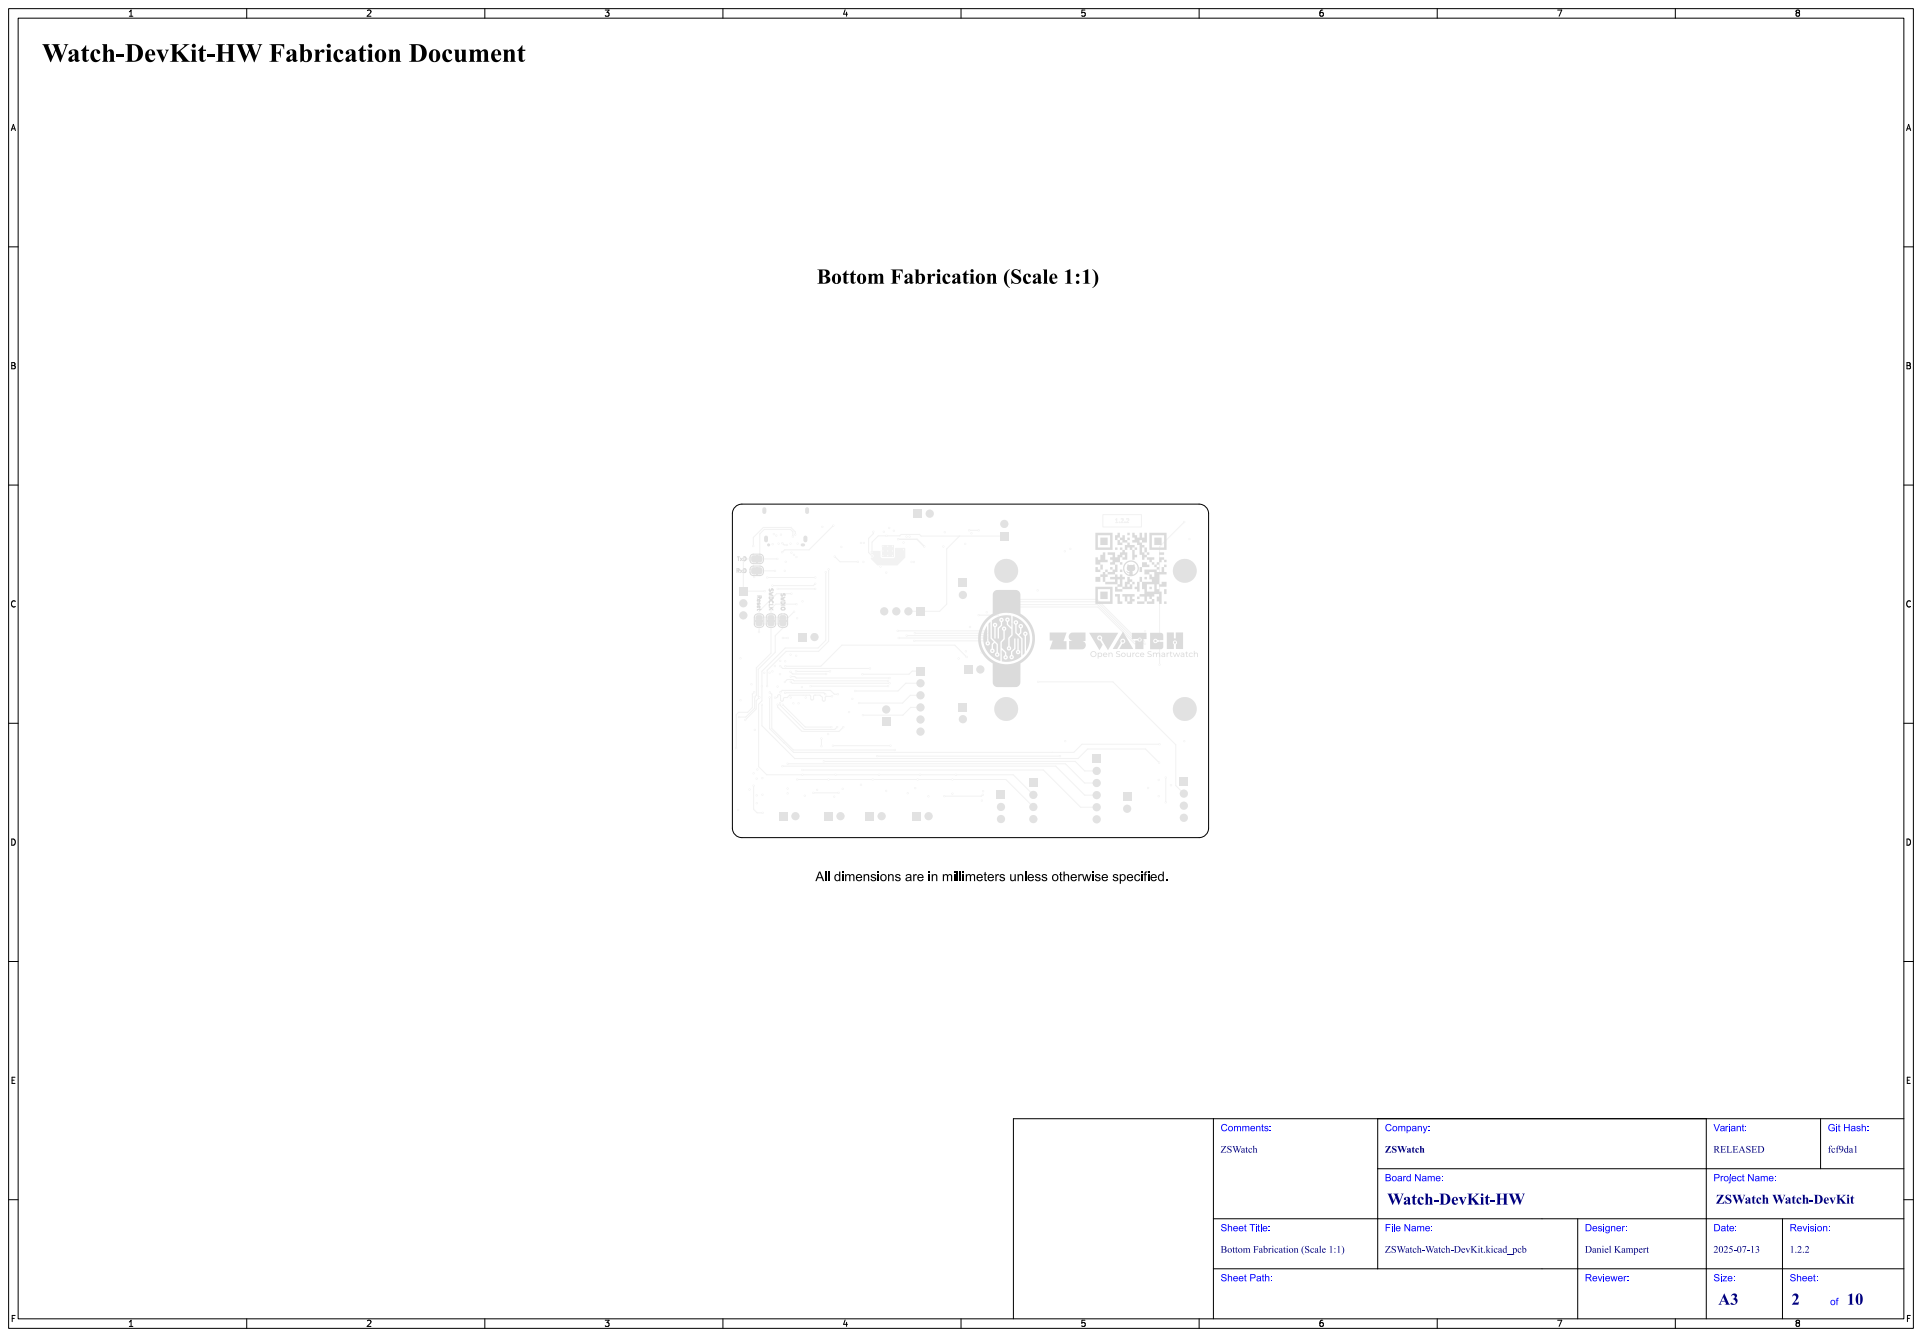
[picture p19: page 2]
Git; Hash:; fcf9da1; ZSWatch; Comments:; Sheet Title:; File Name:; Watch-DevKit-HW; ZSWatch Watch-DevKit; Company:; RELEASED; Variant:; Board Name:; ZSWatch-Watch-DevKit.kicad_pcb; Daniel Kampert; Designer:; Project Name:; Date:; Revision:; 8 Reset; SWDIO; TxD; SWDCLK; RxD

Bottom Fabrication (Scale 1:1)

# Drill Drawing L1 - L4 (Scale 1:1)

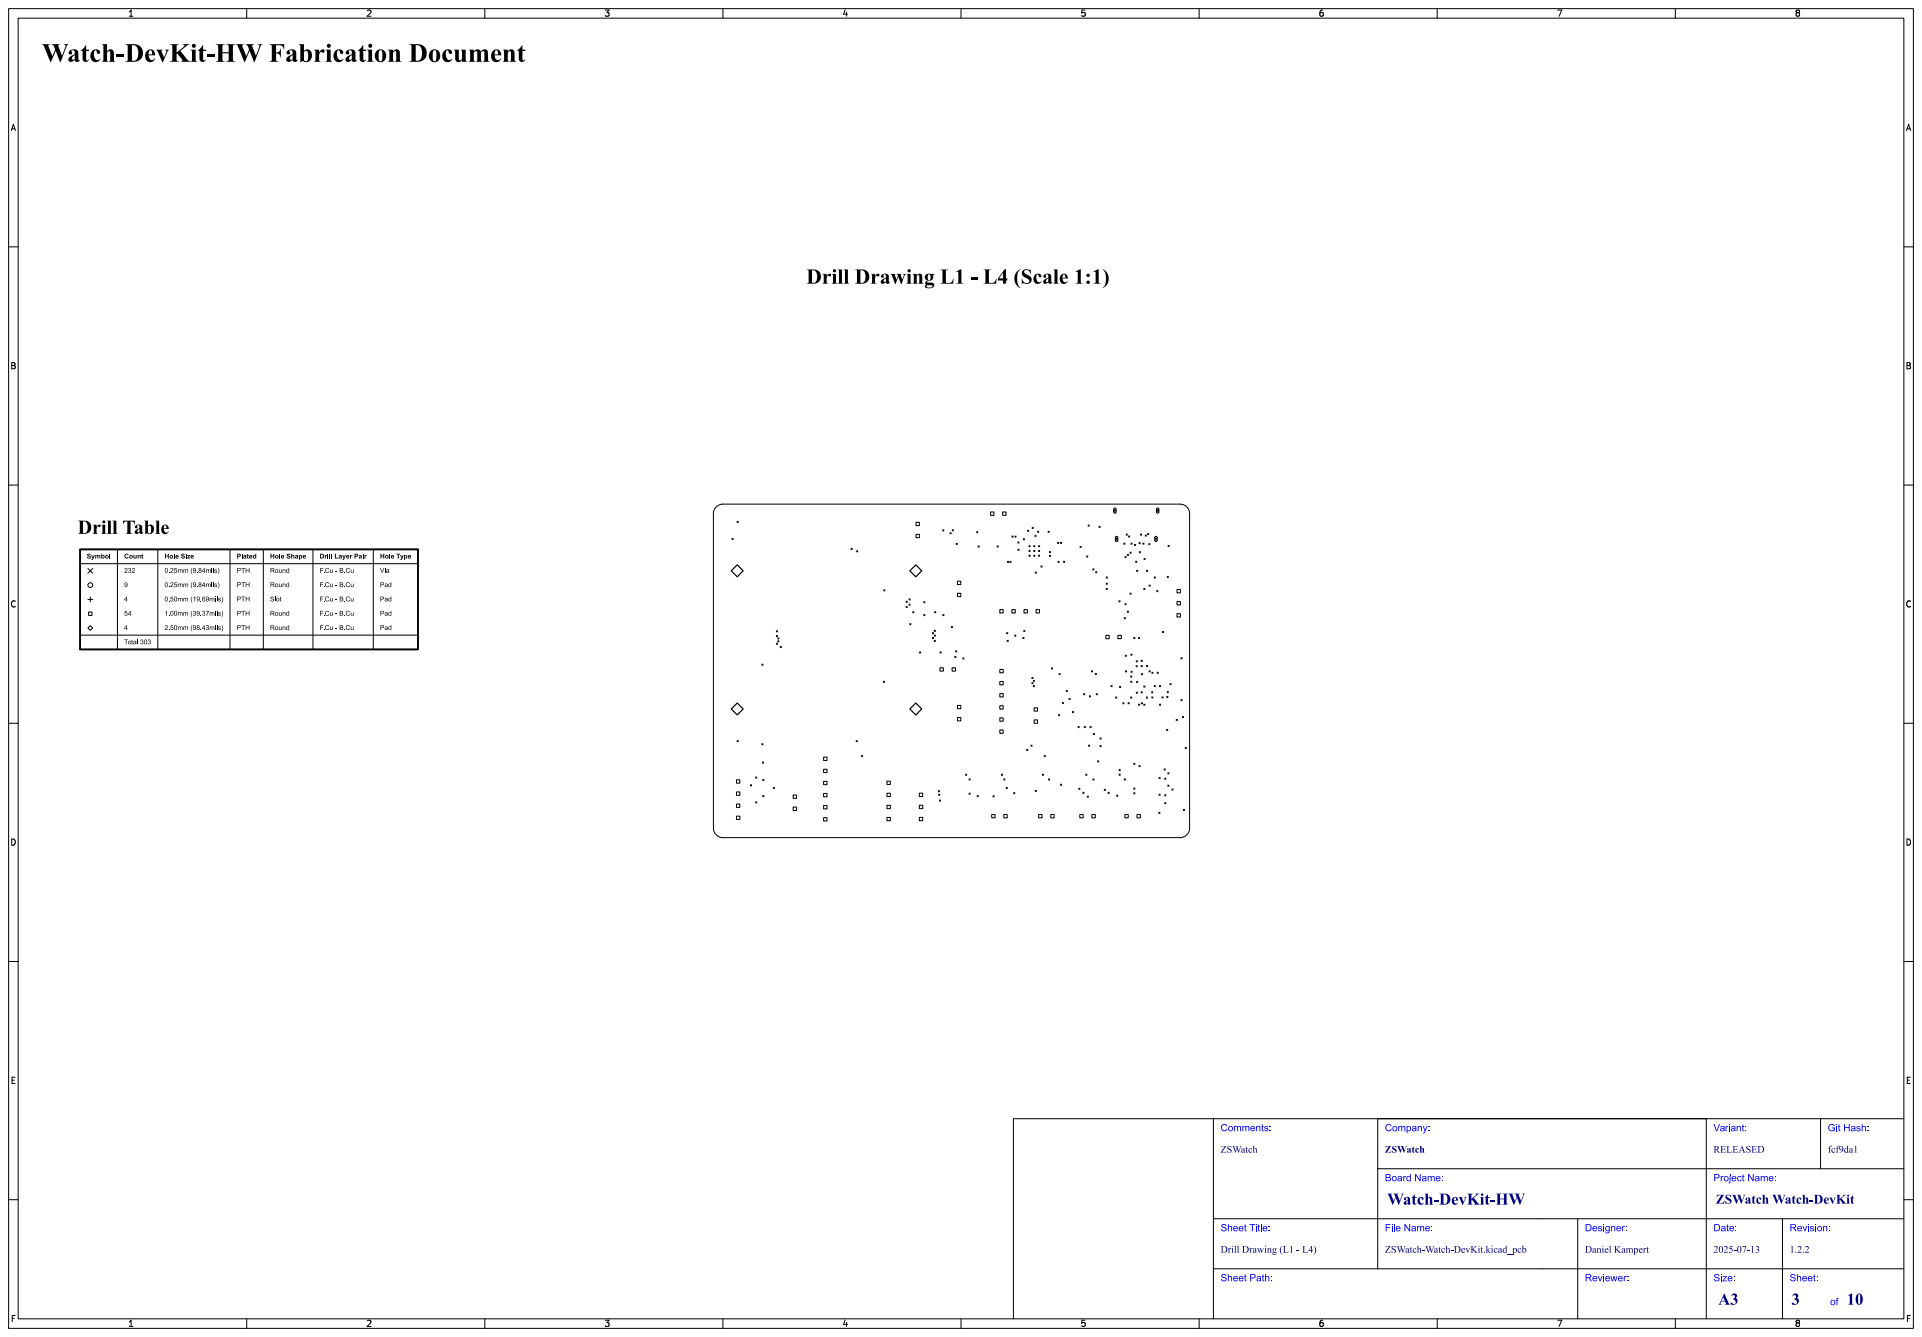
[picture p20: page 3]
Git; Hash:; fcf9da1; ZSWatch; Comments:; Drill Drawing (L1 - L4); Sheet Title:; File Name:; Watch-DevKit-HW; ZSWatch Watch-DevKit; Company:; RELEASED; Variant:; Board Name:; ZSWatch-Watch-DevKit.kicad_pcb; Daniel Kampert; Designer:; Project Name:; Date:; Revision:

# Drill Drawing L1 - L4 (Scale 1:1)

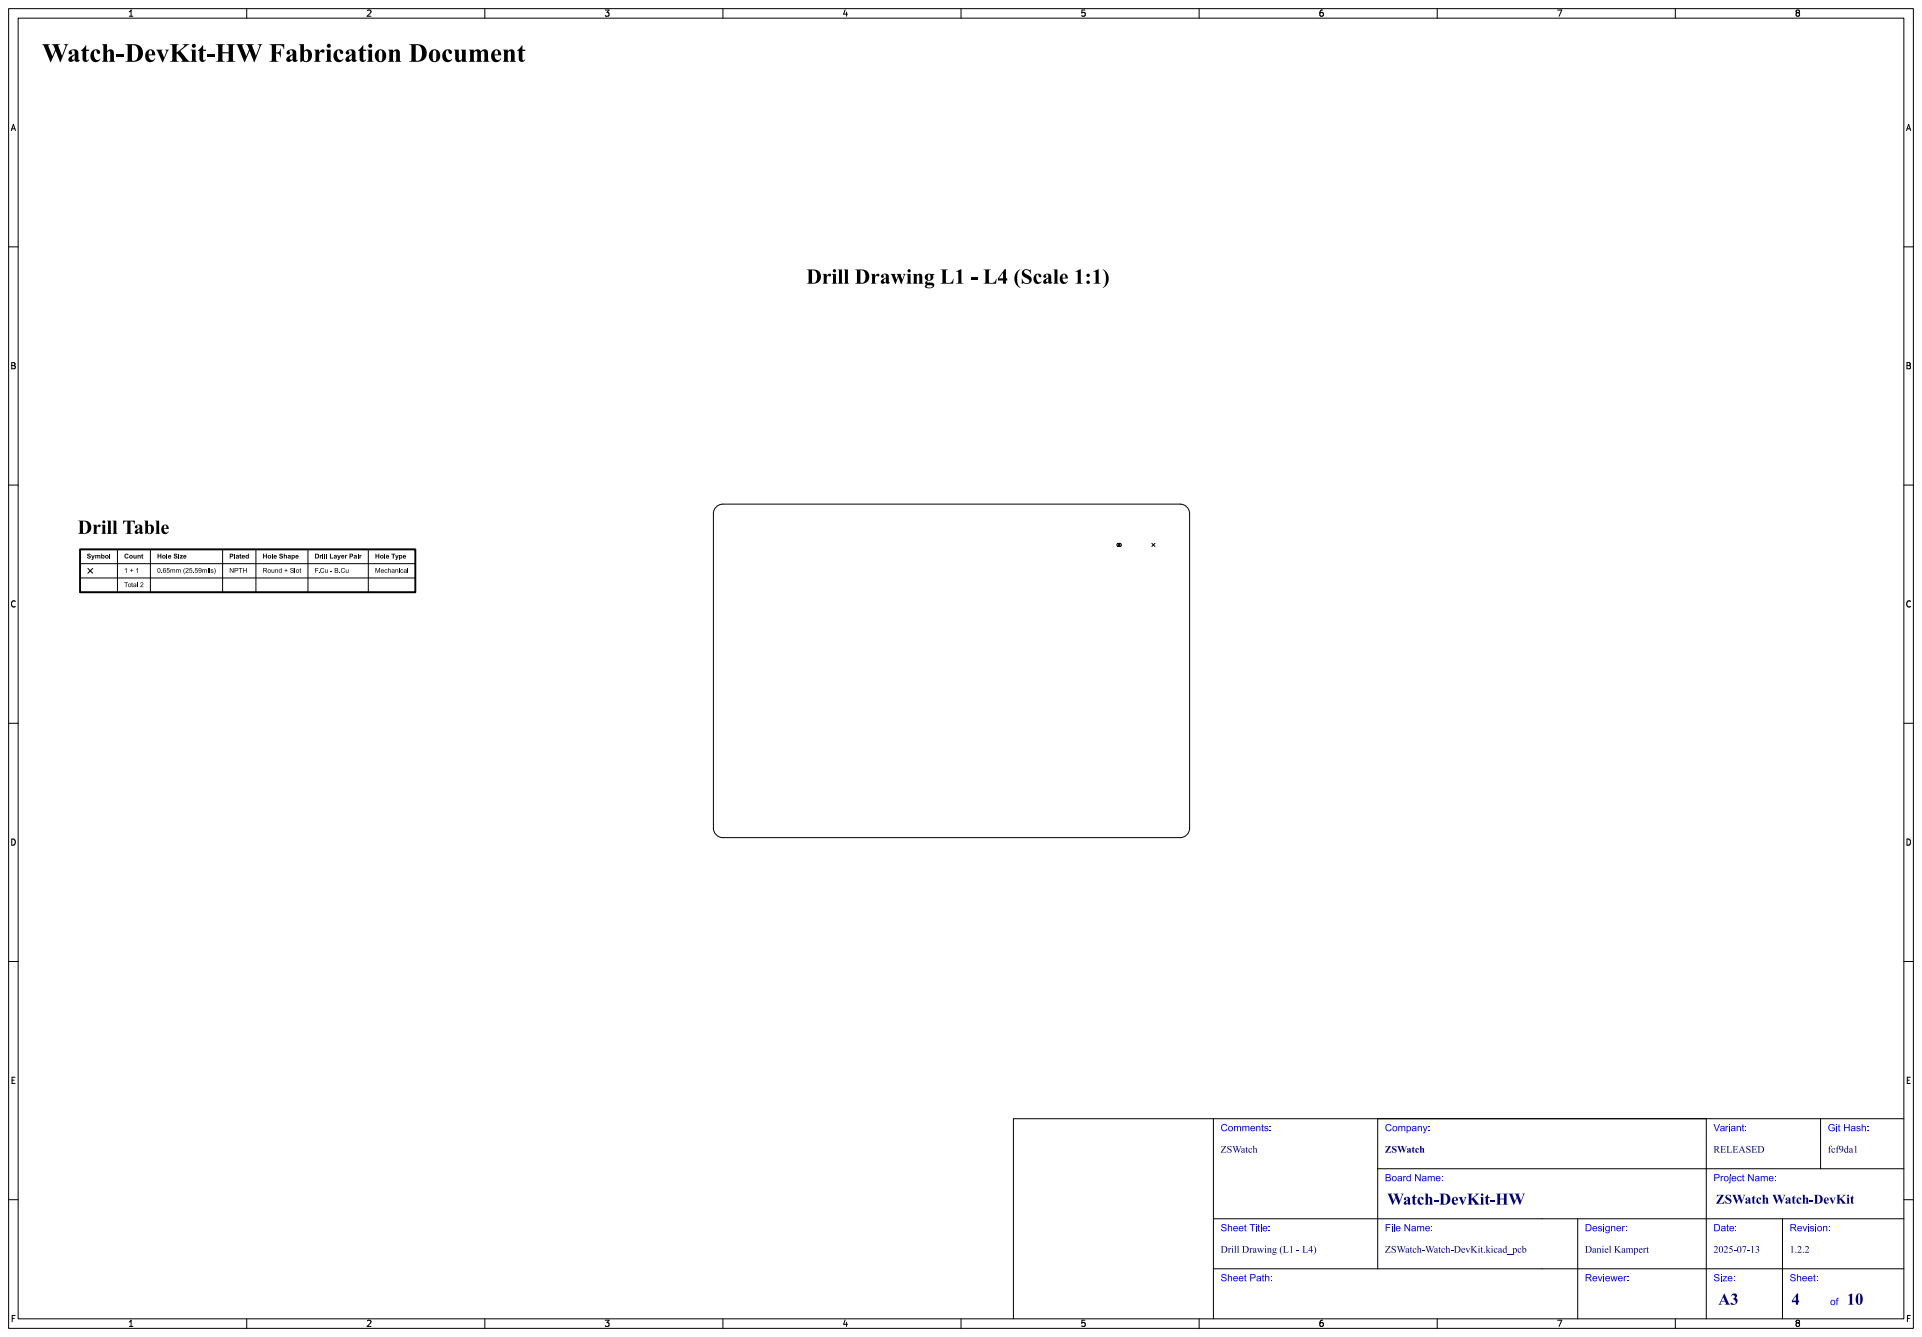
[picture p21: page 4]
Git; Hash:; fcf9da1; ZSWatch; Comments:; Drill Drawing (L1 - L4); Sheet Title:; File Name:; Watch-DevKit-HW; ZSWatch Watch-DevKit; Company:; RELEASED; Variant:; Board Name:; ZSWatch-Watch-DevKit.kicad_pcb; Daniel Kampert; Designer:; Project Name:; Date:; Revision:

# Top Test Points (Scale 1:1)

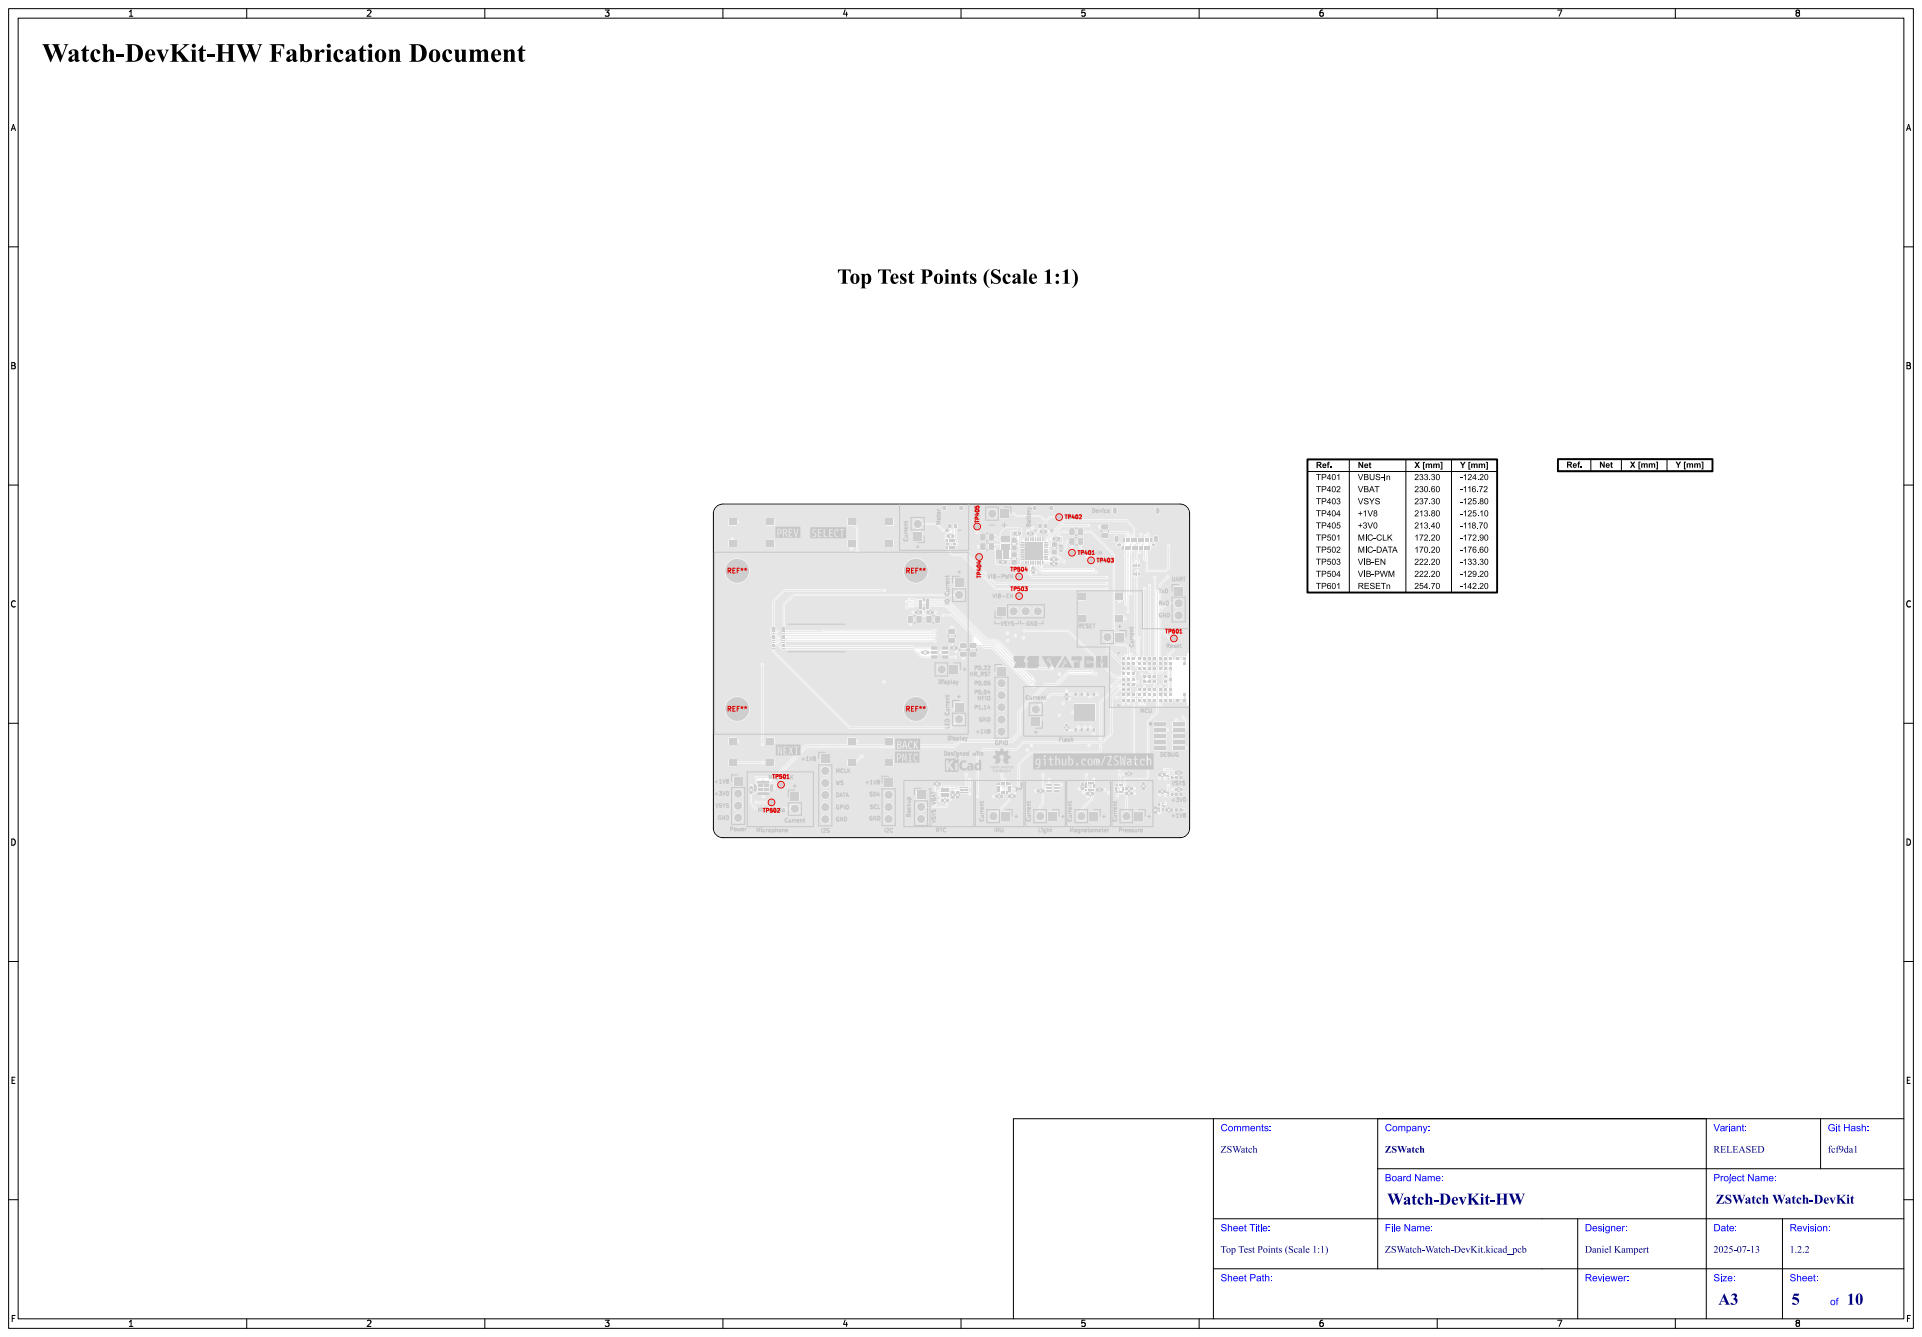
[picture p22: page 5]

Top Test Points (Scale 1:1)

# Bottom Test Points (Scale 1:1)

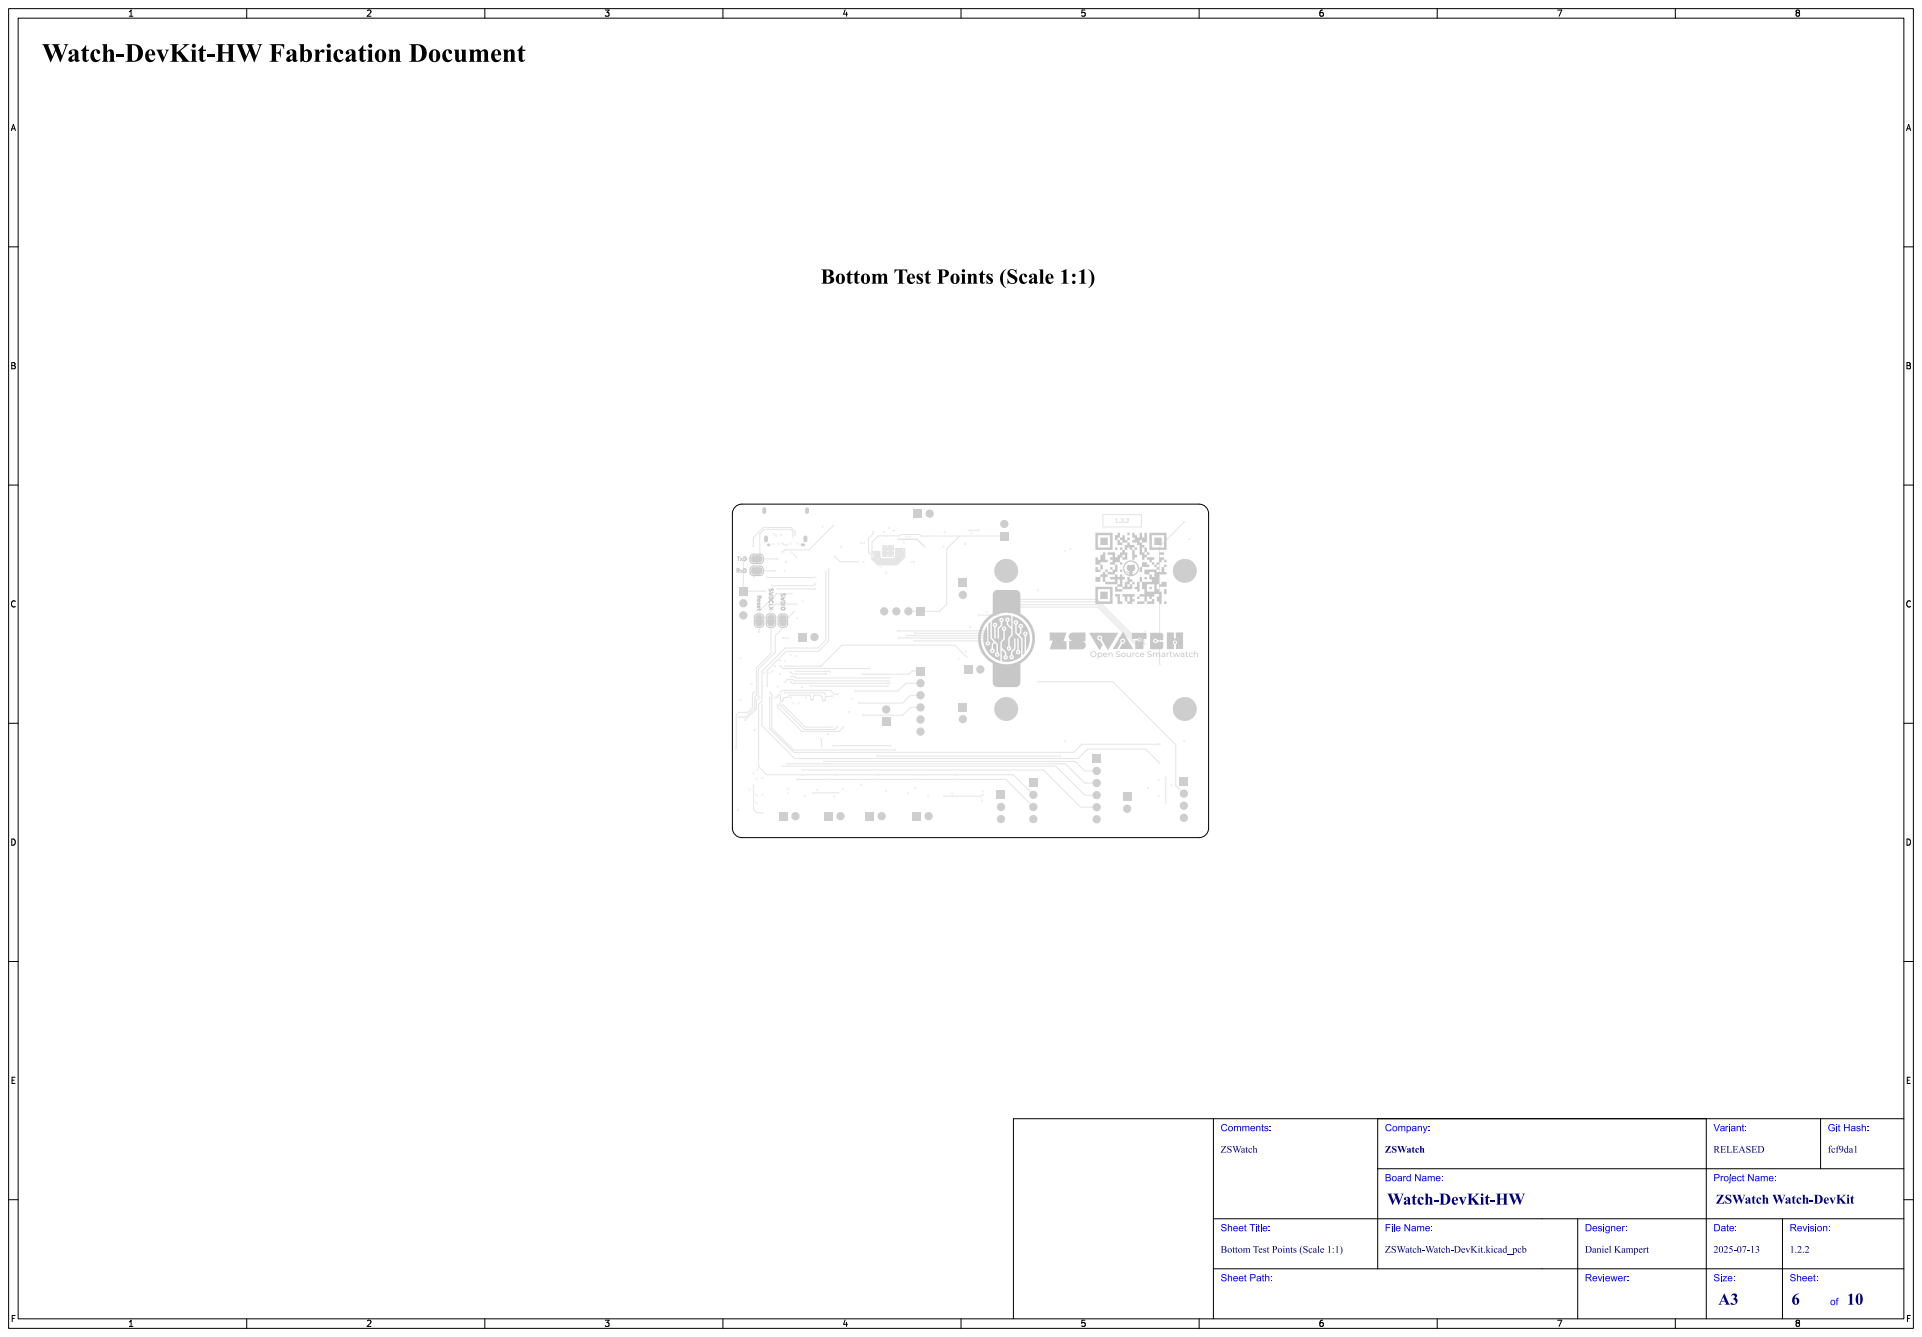
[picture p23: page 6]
Git; Hash:; fcf9da1; ZSWatch; Comments:; Sheet Title:; File Name:; Watch-DevKit-HW; ZSWatch Watch-DevKit; Company:; RELEASED; Variant:; Board Name:; ZSWatch-Watch-DevKit.kicad_pcb; Daniel Kampert; Designer:; Project Name:; Date:; Revision:; 8 Reset; SWDIO; TxD; SWDCLK; RxD

Bottom Test Points (Scale 1:1)

# F.Cu (Scale 1:1)

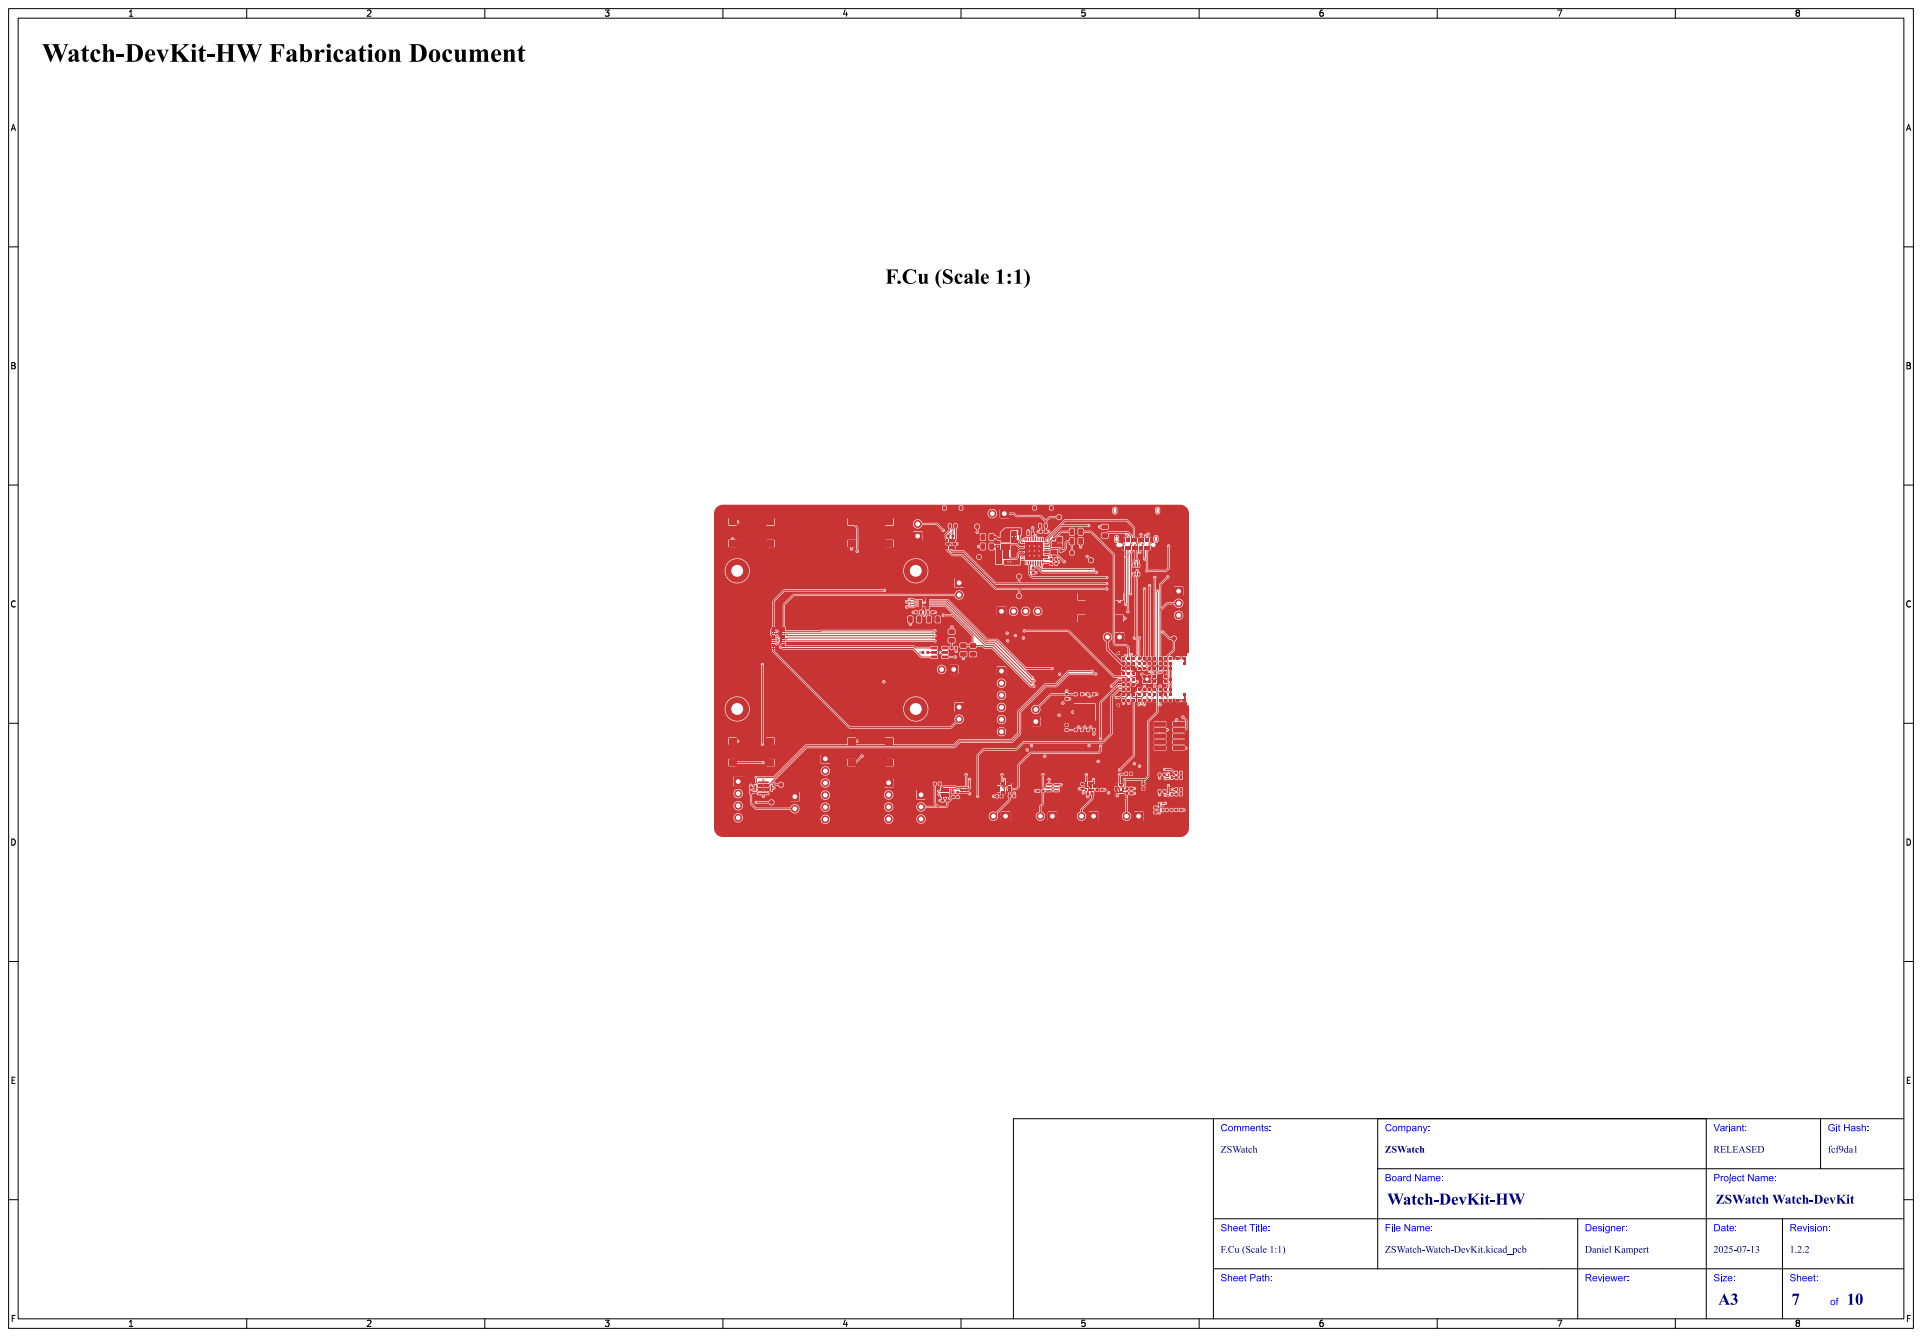
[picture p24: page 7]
Git; Hash:; fcf9da1; ZSWatch; Comments:; F.Cu (Scale 1:1); Sheet Title:; File Name:; Watch-DevKit-HW; ZSWatch Watch-DevKit; Company:; RELEASED; Variant:; Board Name:; ZSWatch-Watch-DevKit.kicad_pcb; Daniel Kampert; Designer:; Project Name:; Date:; Revision:

# Inner1 (GND) (Scale 1:1)

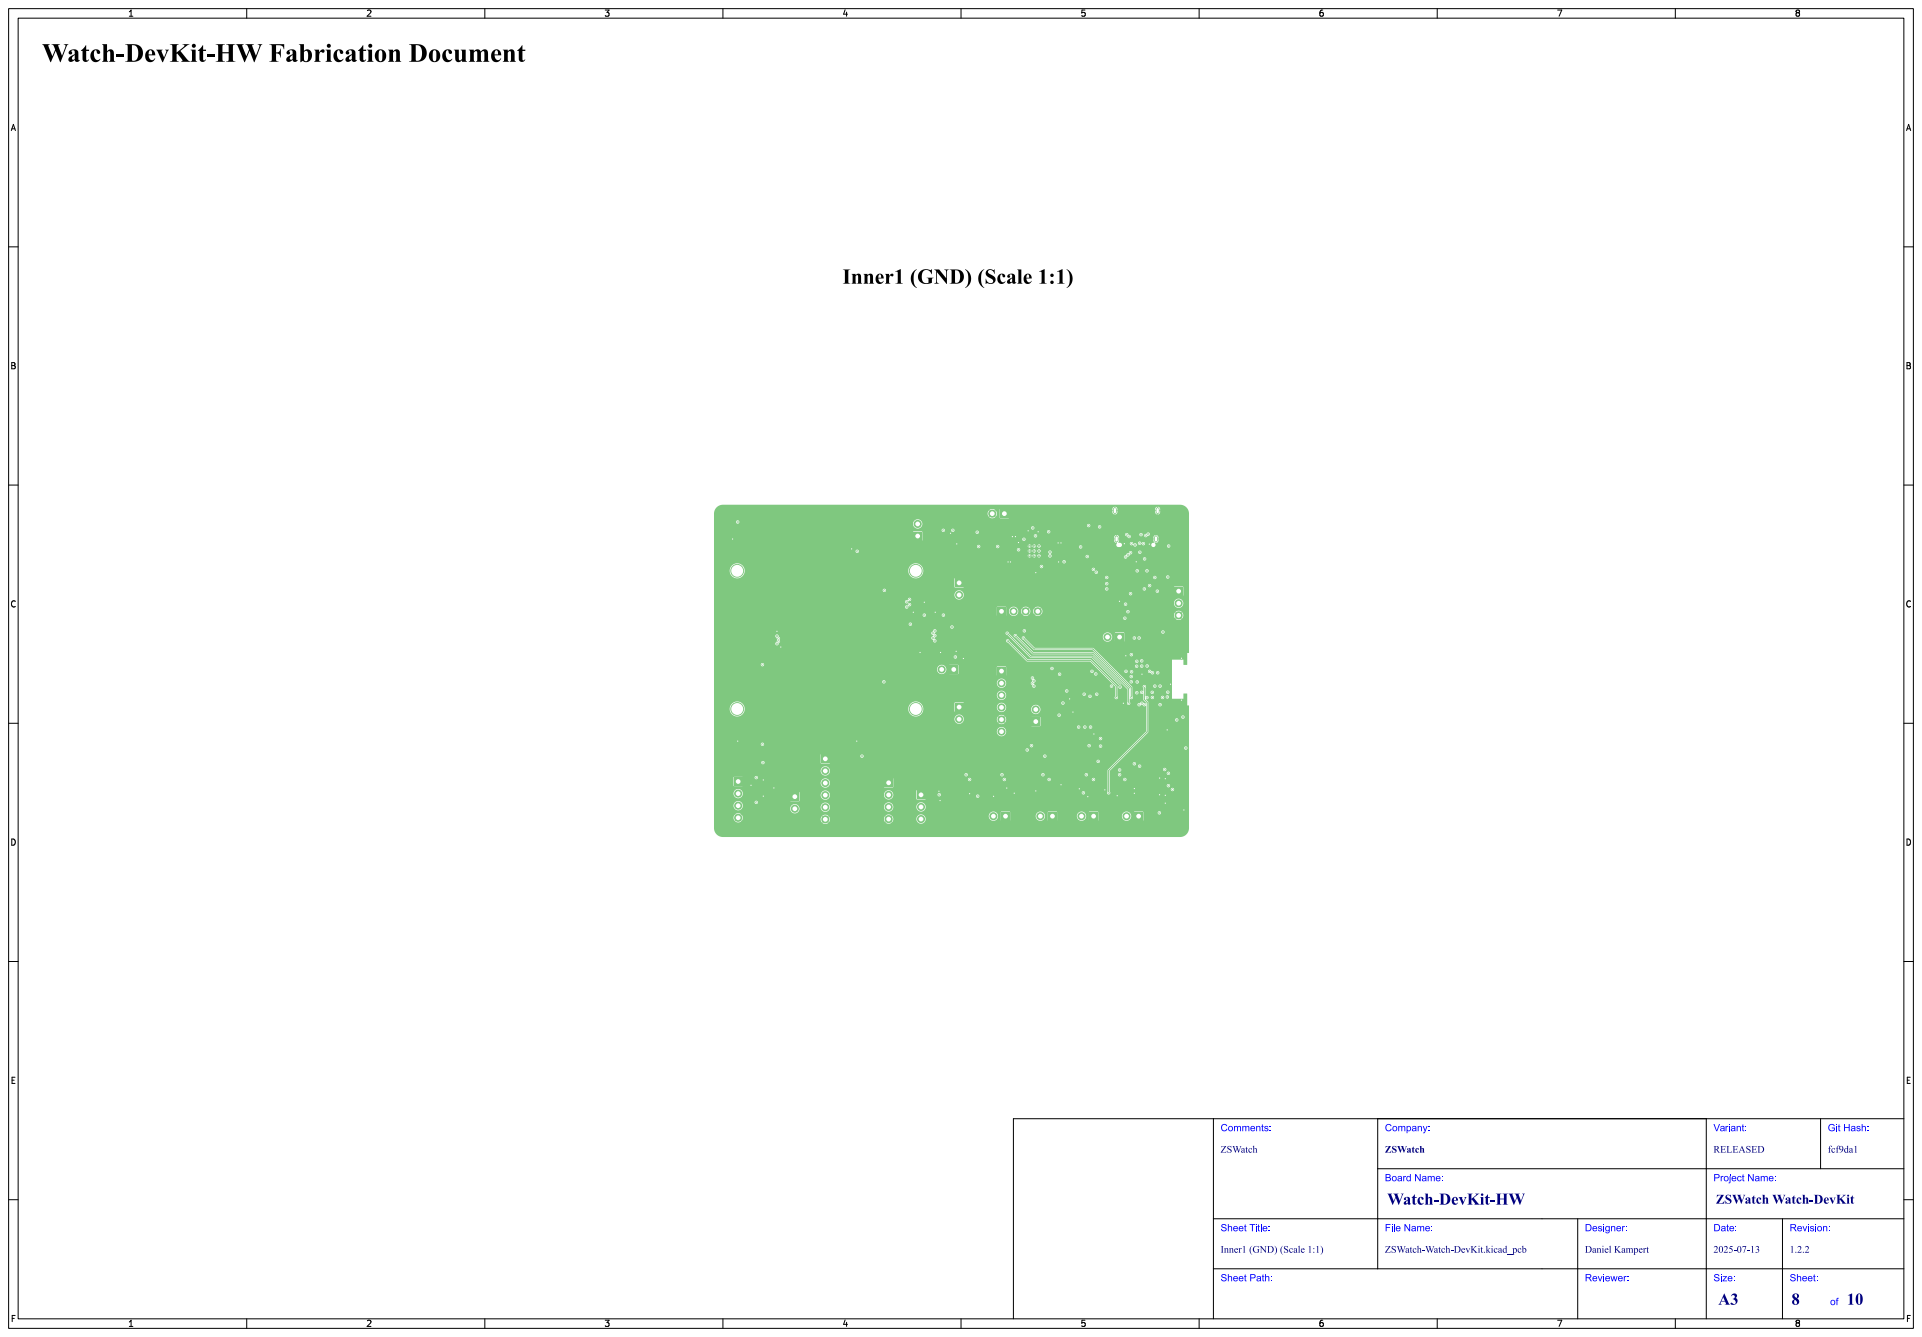
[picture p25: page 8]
Git; Hash:; fcf9da1; ZSWatch; Comments:; Inner1 (GND) (Scale 1:1); Sheet Title:; File Name:; Watch-DevKit-HW; ZSWatch Watch-DevKit; Company:; RELEASED; Variant:; Board Name:; ZSWatch-Watch-DevKit.kicad_pcb; Daniel Kampert; Designer:; Project Name:; Date:; Revision:

# Inner2 (Scale 1:1)

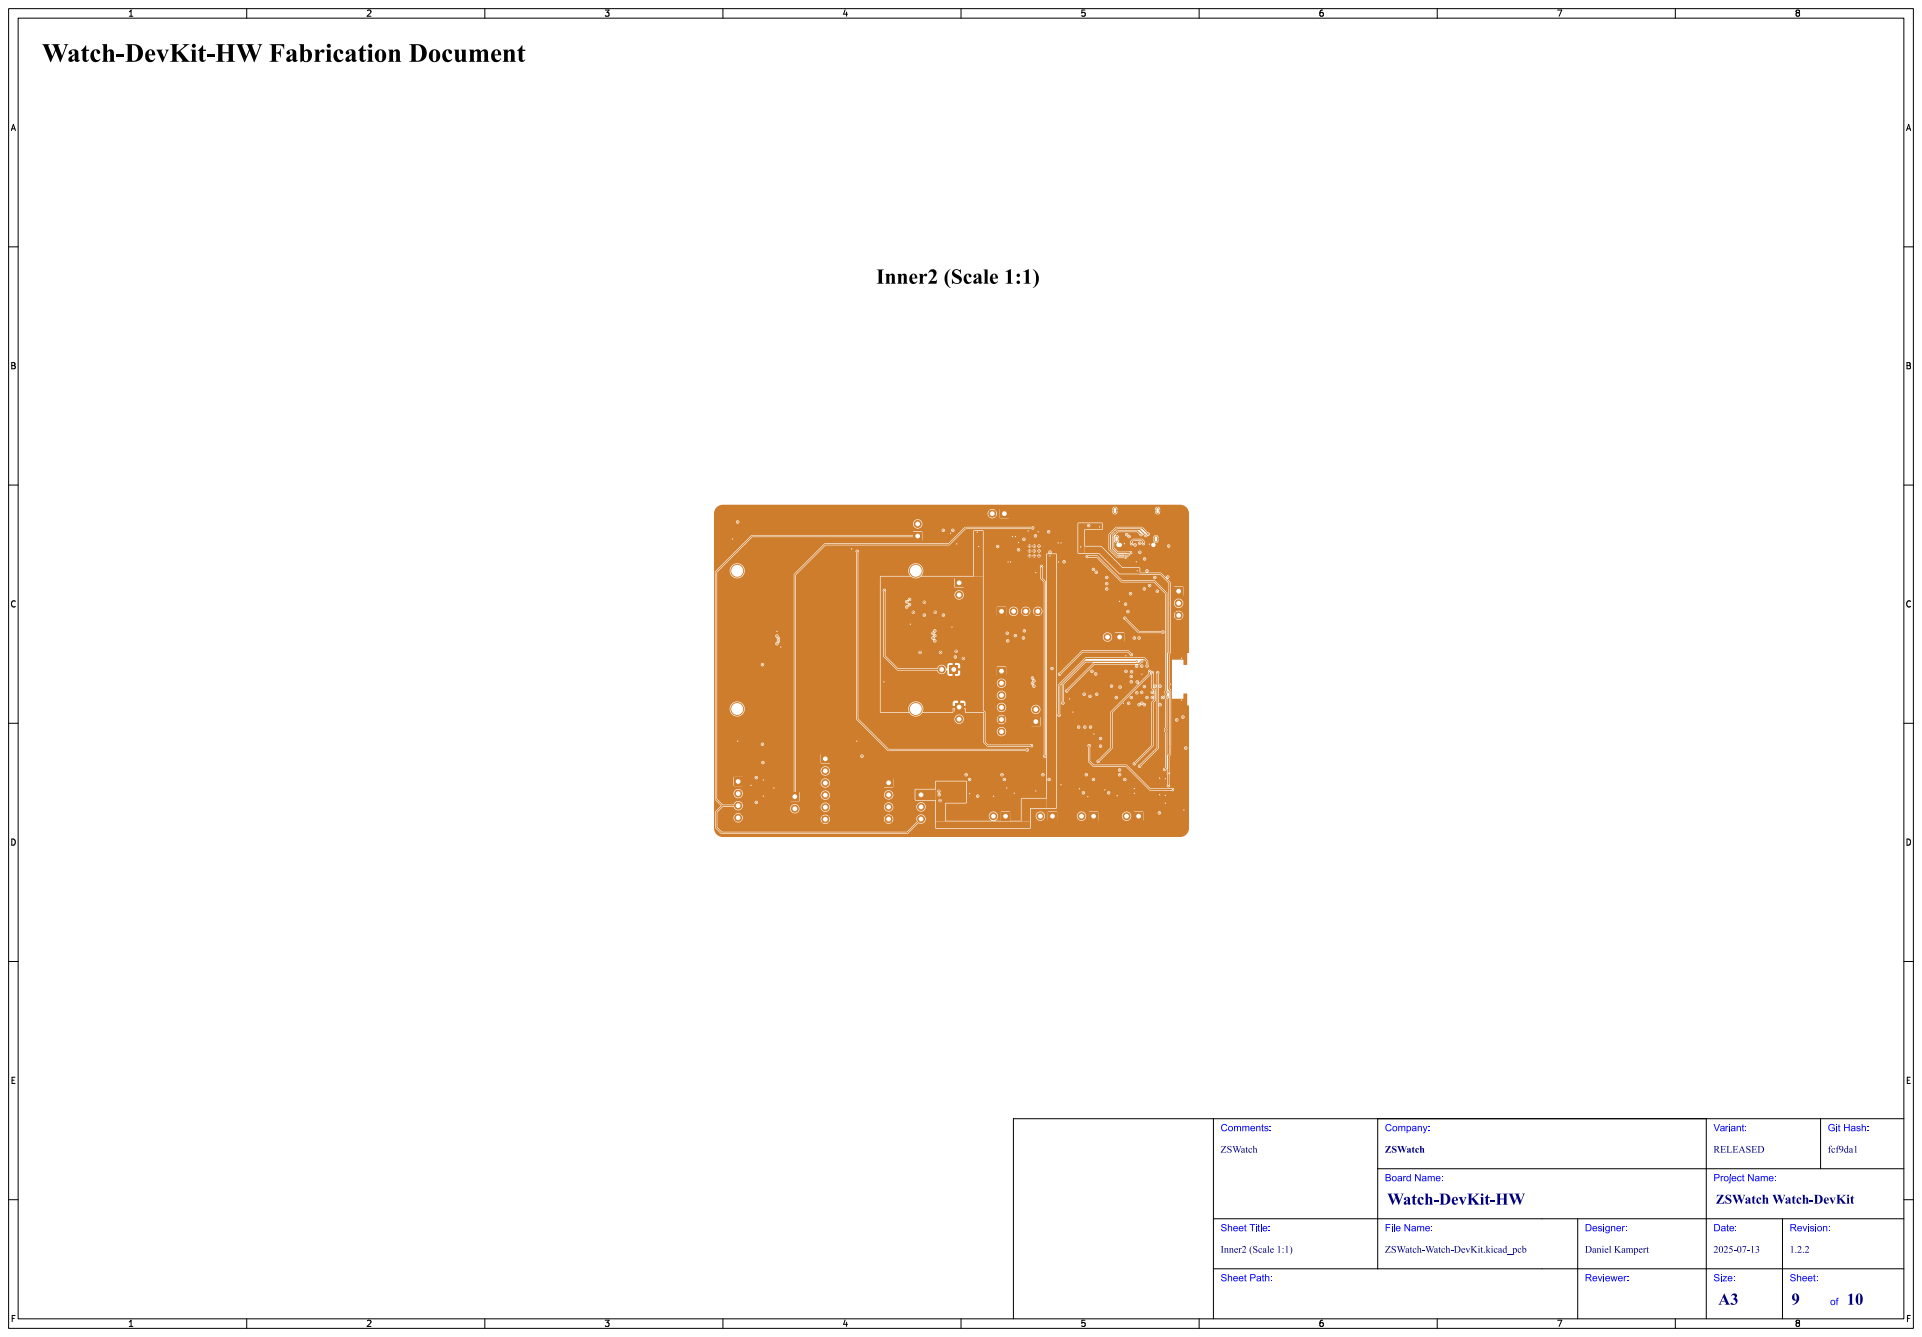
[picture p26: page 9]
Git; Hash:; fcf9da1; ZSWatch; Comments:; Inner2 (Scale 1:1); Sheet Title:; File Name:; Watch-DevKit-HW; ZSWatch Watch-DevKit; Company:; RELEASED; Variant:; Board Name:; ZSWatch-Watch-DevKit.kicad_pcb; Daniel Kampert; Designer:; Project Name:; Date:; Revision:

# B.Cu (Scale 1:1)

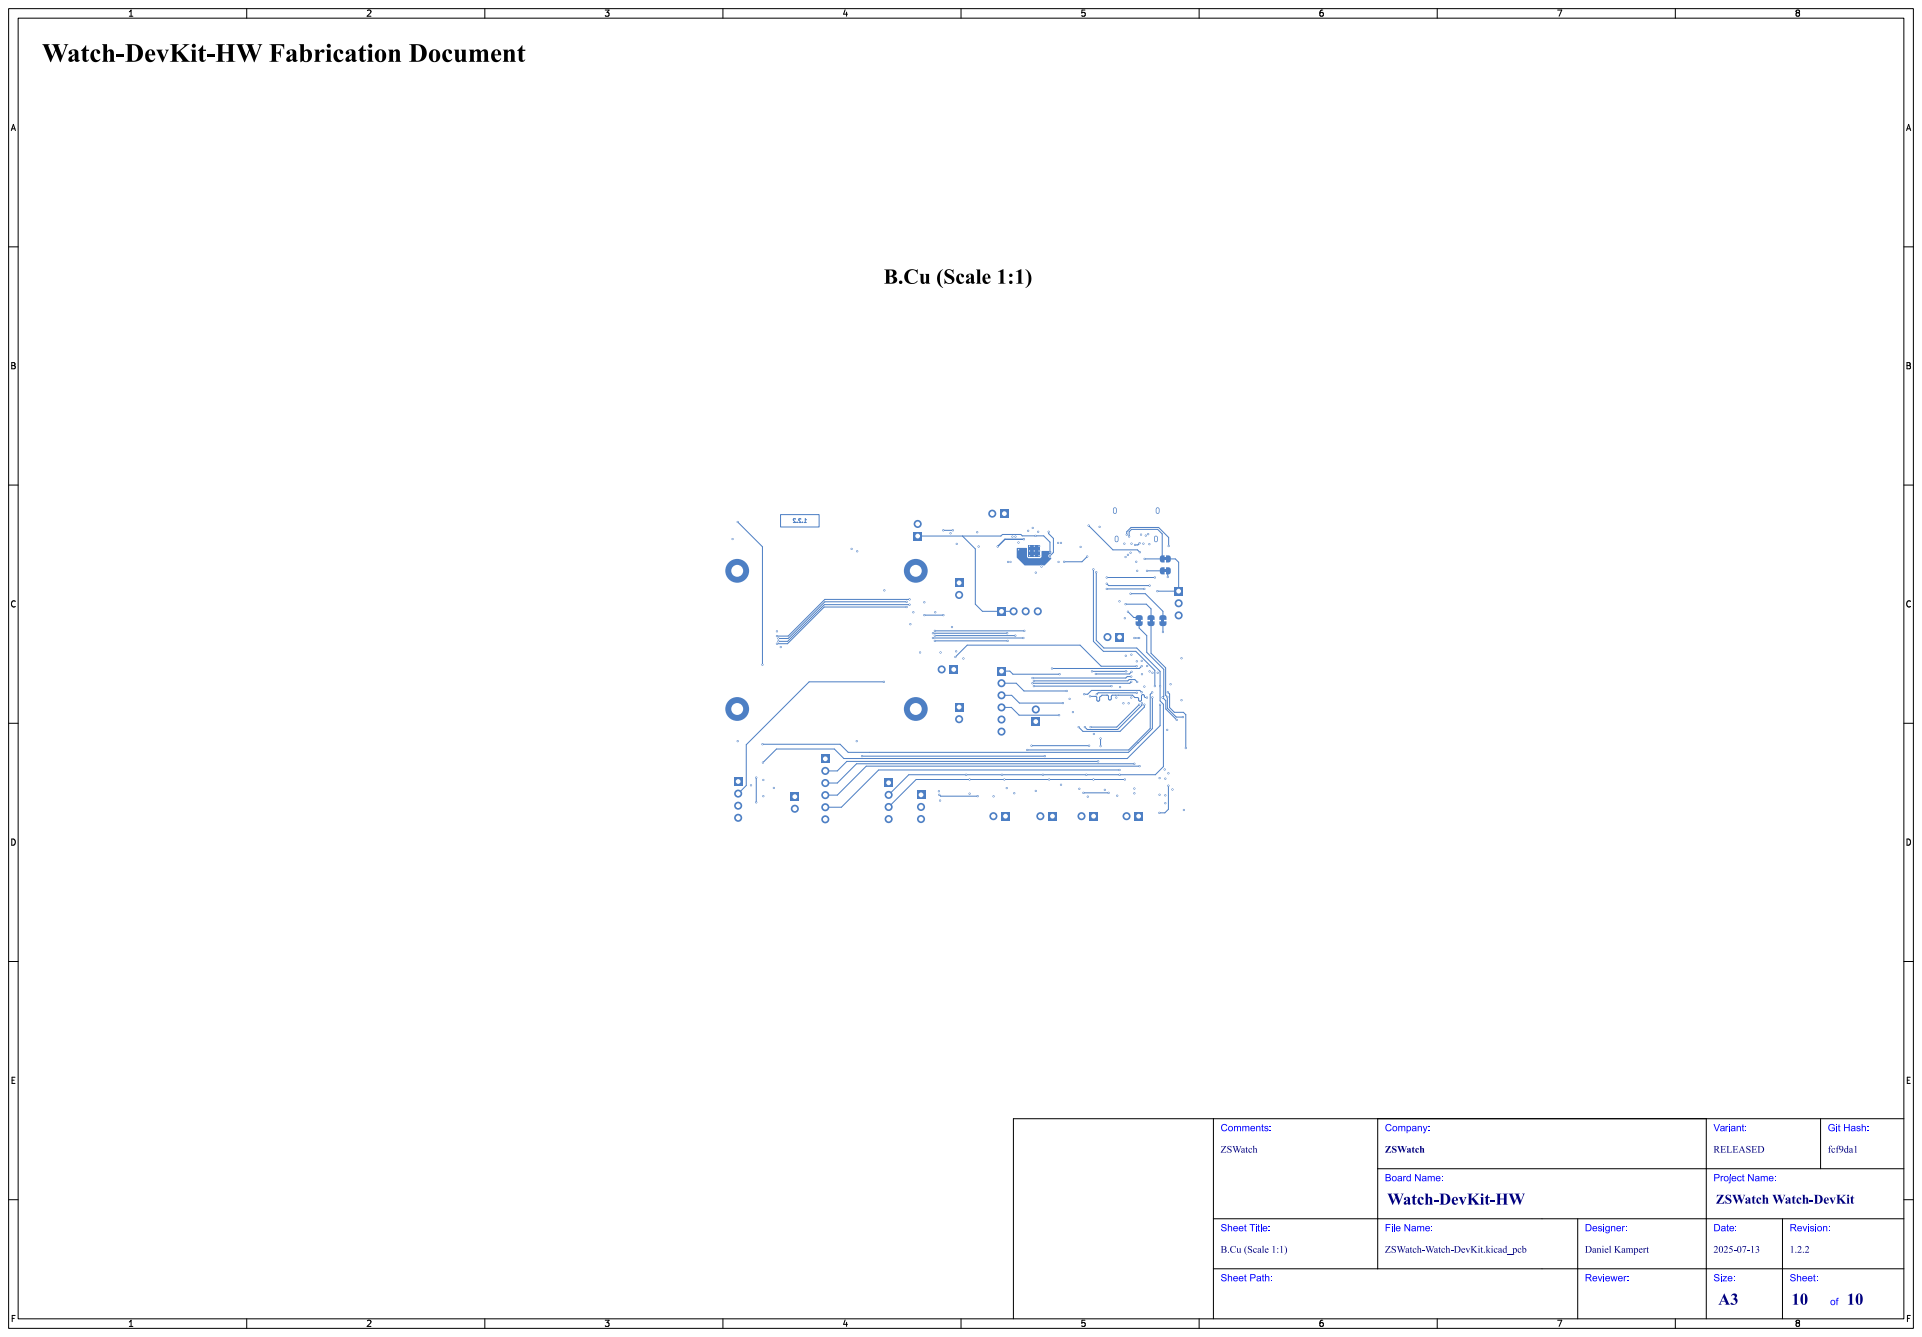
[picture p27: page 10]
Git; Hash:; fcf9da1; ZSWatch; Comments:; B.Cu (Scale 1:1); Sheet Title:; File Name:; Watch-DevKit-HW; ZSWatch Watch-DevKit; Company:; RELEASED; Variant:; Board Name:; ZSWatch-Watch-DevKit.kicad_pcb; Daniel Kampert; Designer:; Project Name:; Date:; Revision:

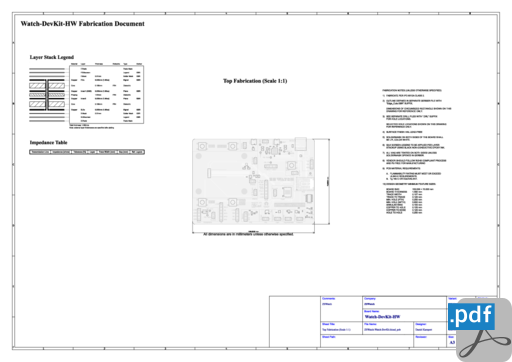
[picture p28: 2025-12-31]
production/watch-dk-RELEASED/HTML/images/cat_pdf_fabrication_ZSWatch-Watch-DevKit-fabrication.png

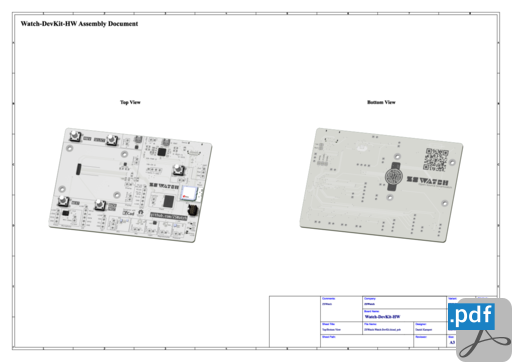
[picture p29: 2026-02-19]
production/watch-dk-PRELIMINARY/HTML/images/cat_pdf_assembly_ZSWatch-Watch-DevKit-assembly.png

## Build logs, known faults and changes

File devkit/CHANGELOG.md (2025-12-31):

# Changelog

## [Unreleased]

## [1.2.2] - 2025-12-31

### Added

-       Add additional header for VSYS (#181)
-   Add additional GPIO to I2S header (#180)
-   Bring back ZSWatch logo (#182)

### Changed

-   Change part number for SWD connector to BD125-10-A-0305-0580-L-B (#164)
-   Replace 0R with closed jumper (#173)
-       USB VBUS In Improvements (#184)
-       Allow powering RTC from any voltage source (#186)
-   Replace mounting holes with holes with a bigger margin (#187)

### Fixed

-   Fix wrong resistor for VREF2 pin for the level shifter (#172)
-   Fix wrong silkscreen for Display current (#179)

### Removed

-   Remove 0R and 5k1 CC resistors (#183)

## [1.2.1] - 2025-09-26

### Added

-   Add missing pull-ups for I2C lines (#158)

### Fixed

-   Fix wrong ship mode button (#155)

### Changed

-   Change part number for SWD connector to 62201021121 (#157)
-   Set pull-up for Flash CS to NA (#158)
-   Center the mounting holes for the display (#159)

## [1.2.0] - 2025-09-07

### Fixed

-   Fix wrong orientation for SWD header (#117)

### Added

-   Add pull-up resistor for display enable signal. Can be disabled via GPIO. (#123)
-   Add new KiBot template (#116)
-   Add orientation marker for IMU (#124)
-   Add power LEDs (#128)
-   Add reset button (#131)
-   Add testpoints for microphone I2S (#145)

### Changed

-   Shrink down the PCB to save costs (#115)
-   Replace pin headers with THT to make them more robust (#121)
-   Rename "Power" jumpers to "Current" (#129)
-   Replace level shifter for RTC with PCA9306GF (#133)
-   Switch back to old LED driver (#134)
-   Power microphone from PMIC (#145)

### Removed

-   Remove APDS-9306 interrupt (#122)

[Unreleased]: https://github.com/ZSWatch/Watch-DevKit-HW/compare/1.2.2...HEAD

[1.2.2]: https://github.com/ZSWatch/Watch-DevKit-HW/compare/1.2.1...1.2.2

[1.2.1]: https://github.com/ZSWatch/Watch-DevKit-HW/compare/1.2.0...1.2.1

[1.2.0]: https://github.com/ZSWatch/Watch-DevKit-HW/compare/fc3844fb6a647a23e214f3085a47ce2212e0d98a...1.2.0

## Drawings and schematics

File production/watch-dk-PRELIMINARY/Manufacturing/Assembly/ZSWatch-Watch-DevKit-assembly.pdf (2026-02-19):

# Watch-DevKit-HW Assembly Document

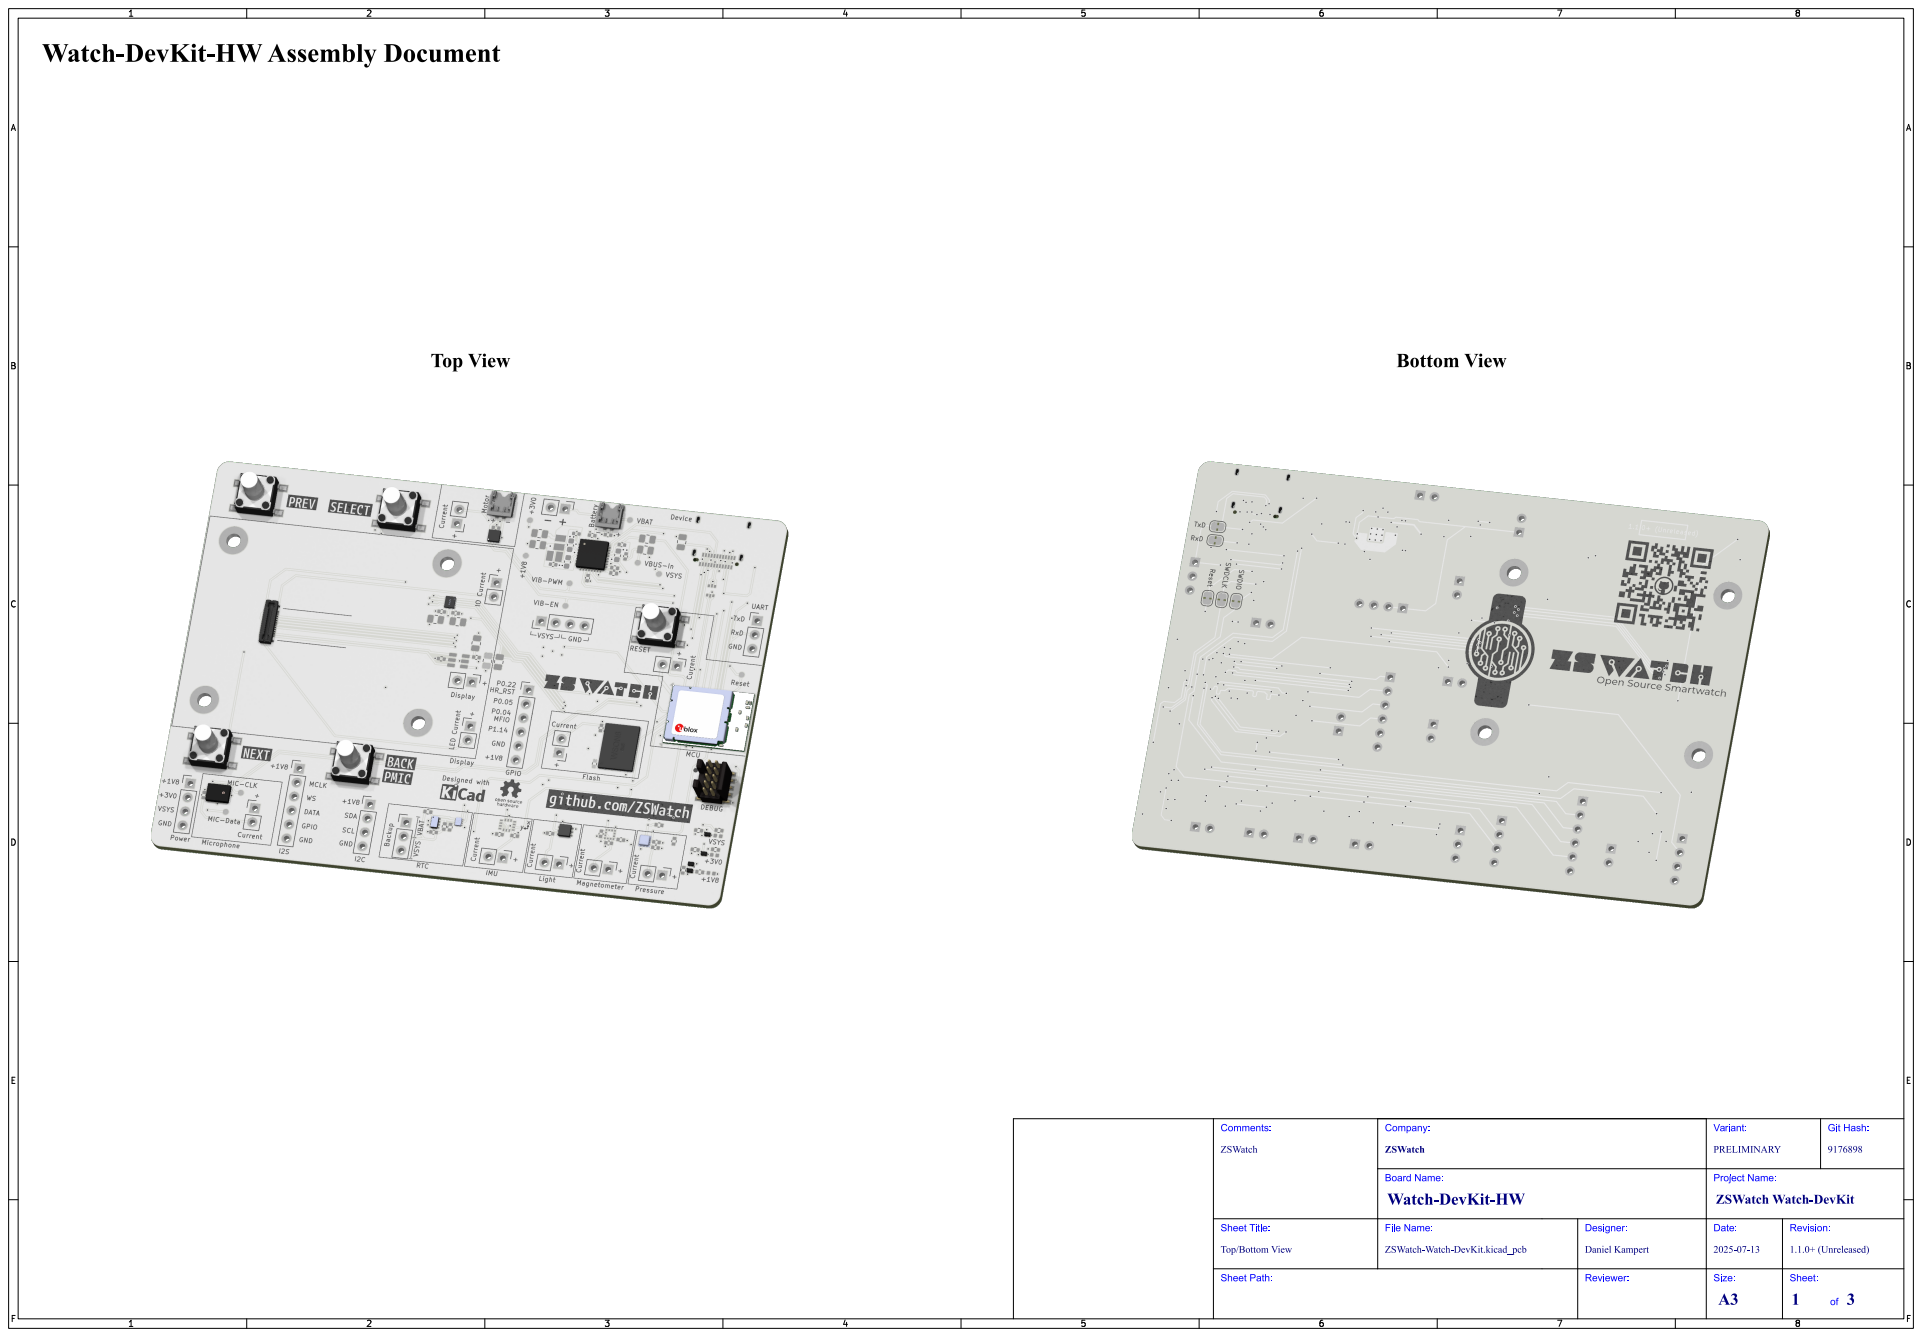
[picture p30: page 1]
Git; Hash:; ZSWatch; Comments:; Sheet Path:; Sheet Title:; File Name:; Watch-DevKit-HW; ZSWatch Watch-DevKit; Company:; PRELIMINARY; Variant:; Board Name:; ZSWatch-Watch-DevKit.kicad_pcb; Daniel Kampert; Designer:; Reviewer:; Project Name:; Date:; 1.1.0+ (Unreleased); Revision:; Size:; Sheet:

Top/Bottom View

# Top Assembly (Scale 1:1)

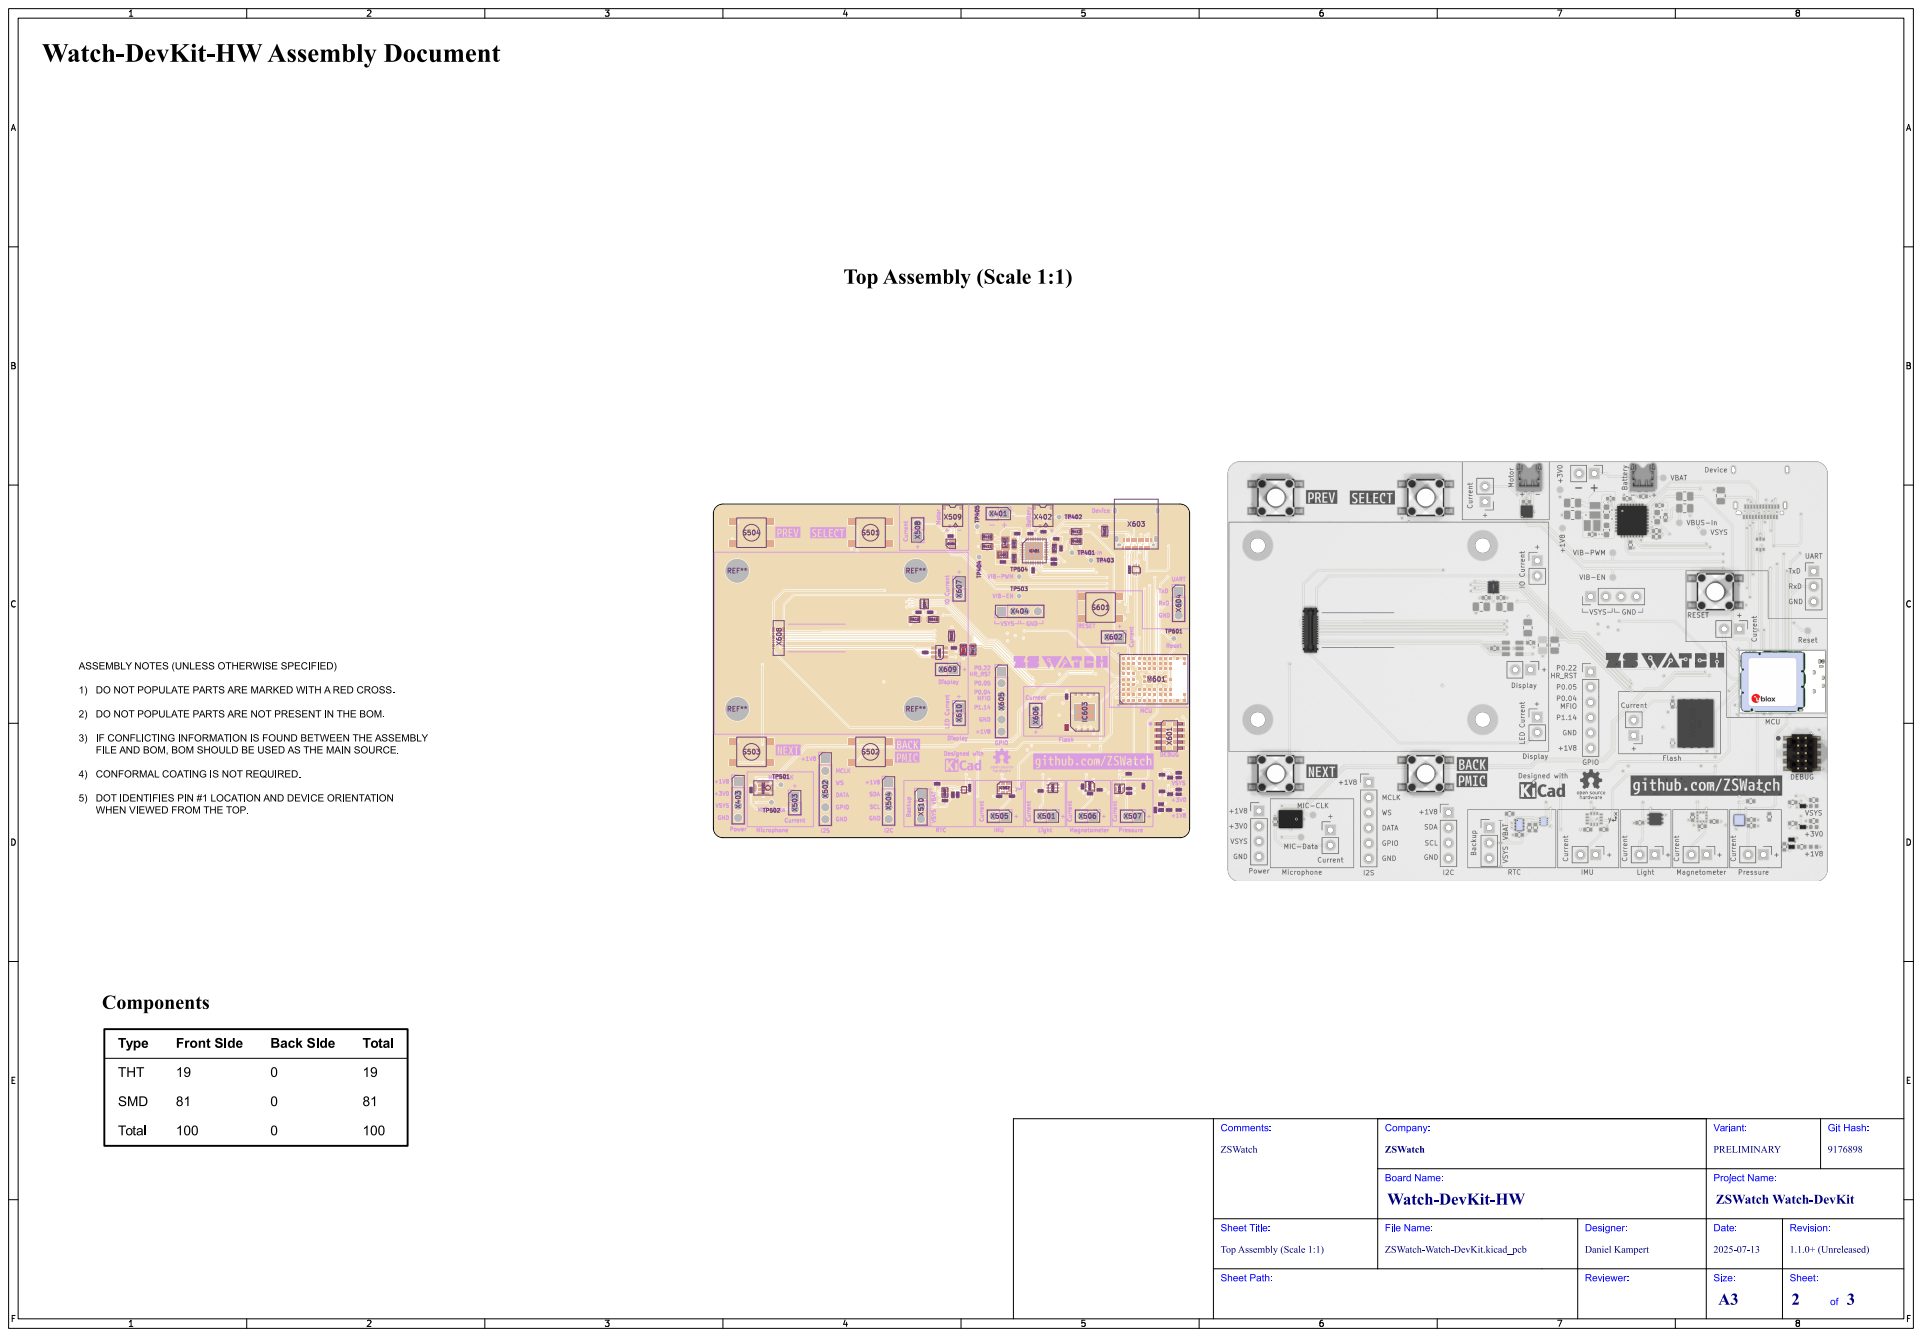
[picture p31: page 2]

# Bottom Assembly (Scale 1:1)

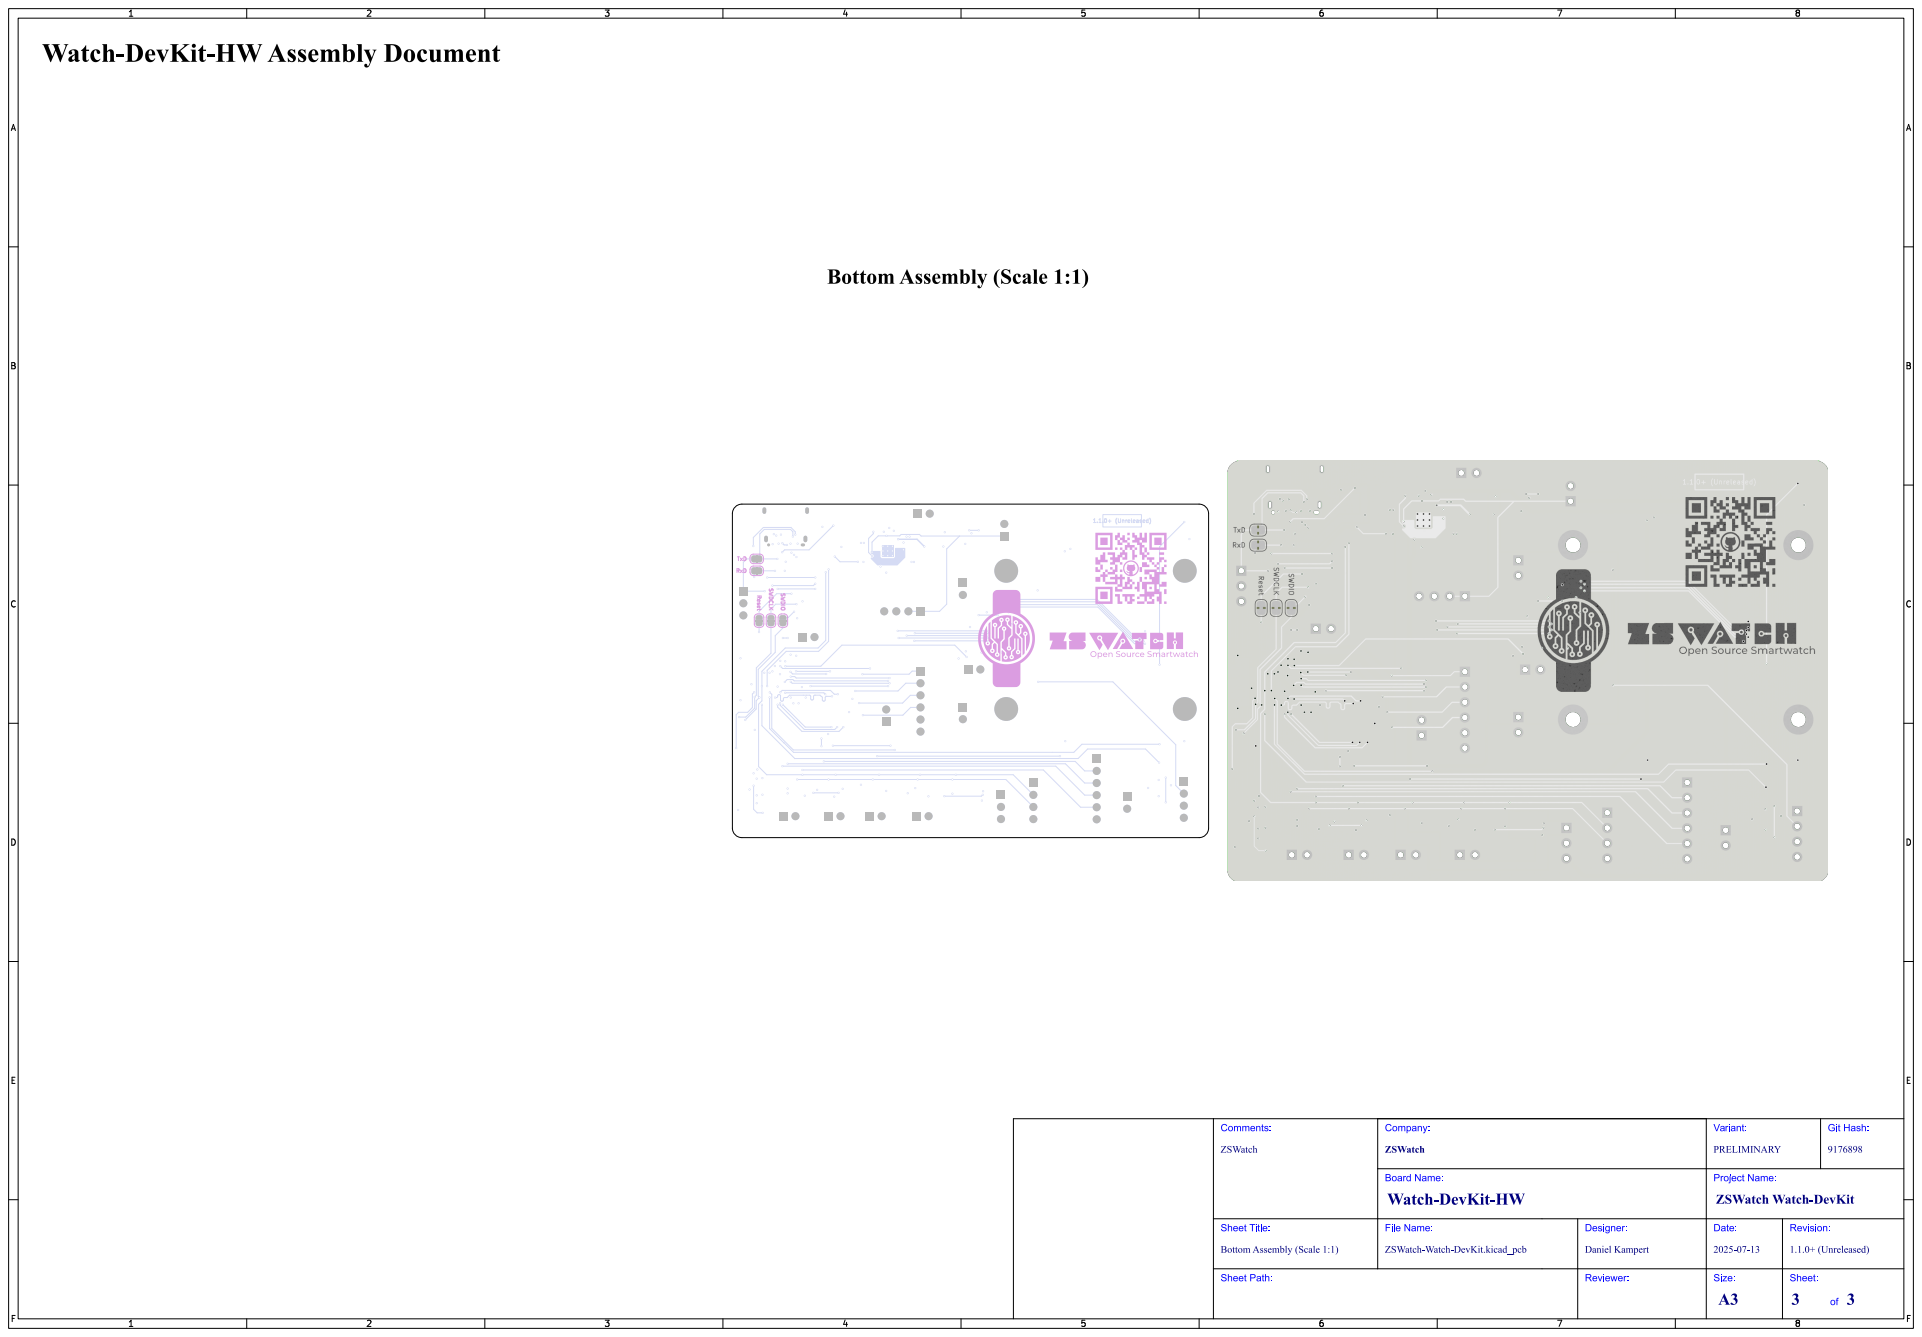
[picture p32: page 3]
Git; Hash:; ZSWatch; Comments:; Sheet Title:; File Name:; Watch-DevKit-HW; ZSWatch Watch-DevKit; Company:; PRELIMINARY; Variant:; Board Name:; ZSWatch-Watch-DevKit.kicad_pcb; Daniel Kampert; Designer:; Project Name:; Date:; 1.1.0+ (Unreleased); Revision:; 8 Reset; SWDIO; TxD; SWDCLK; RxD

Bottom Assembly (Scale 1:1)

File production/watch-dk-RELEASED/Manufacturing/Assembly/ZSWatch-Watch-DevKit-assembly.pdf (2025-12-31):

# Watch-DevKit-HW Assembly Document

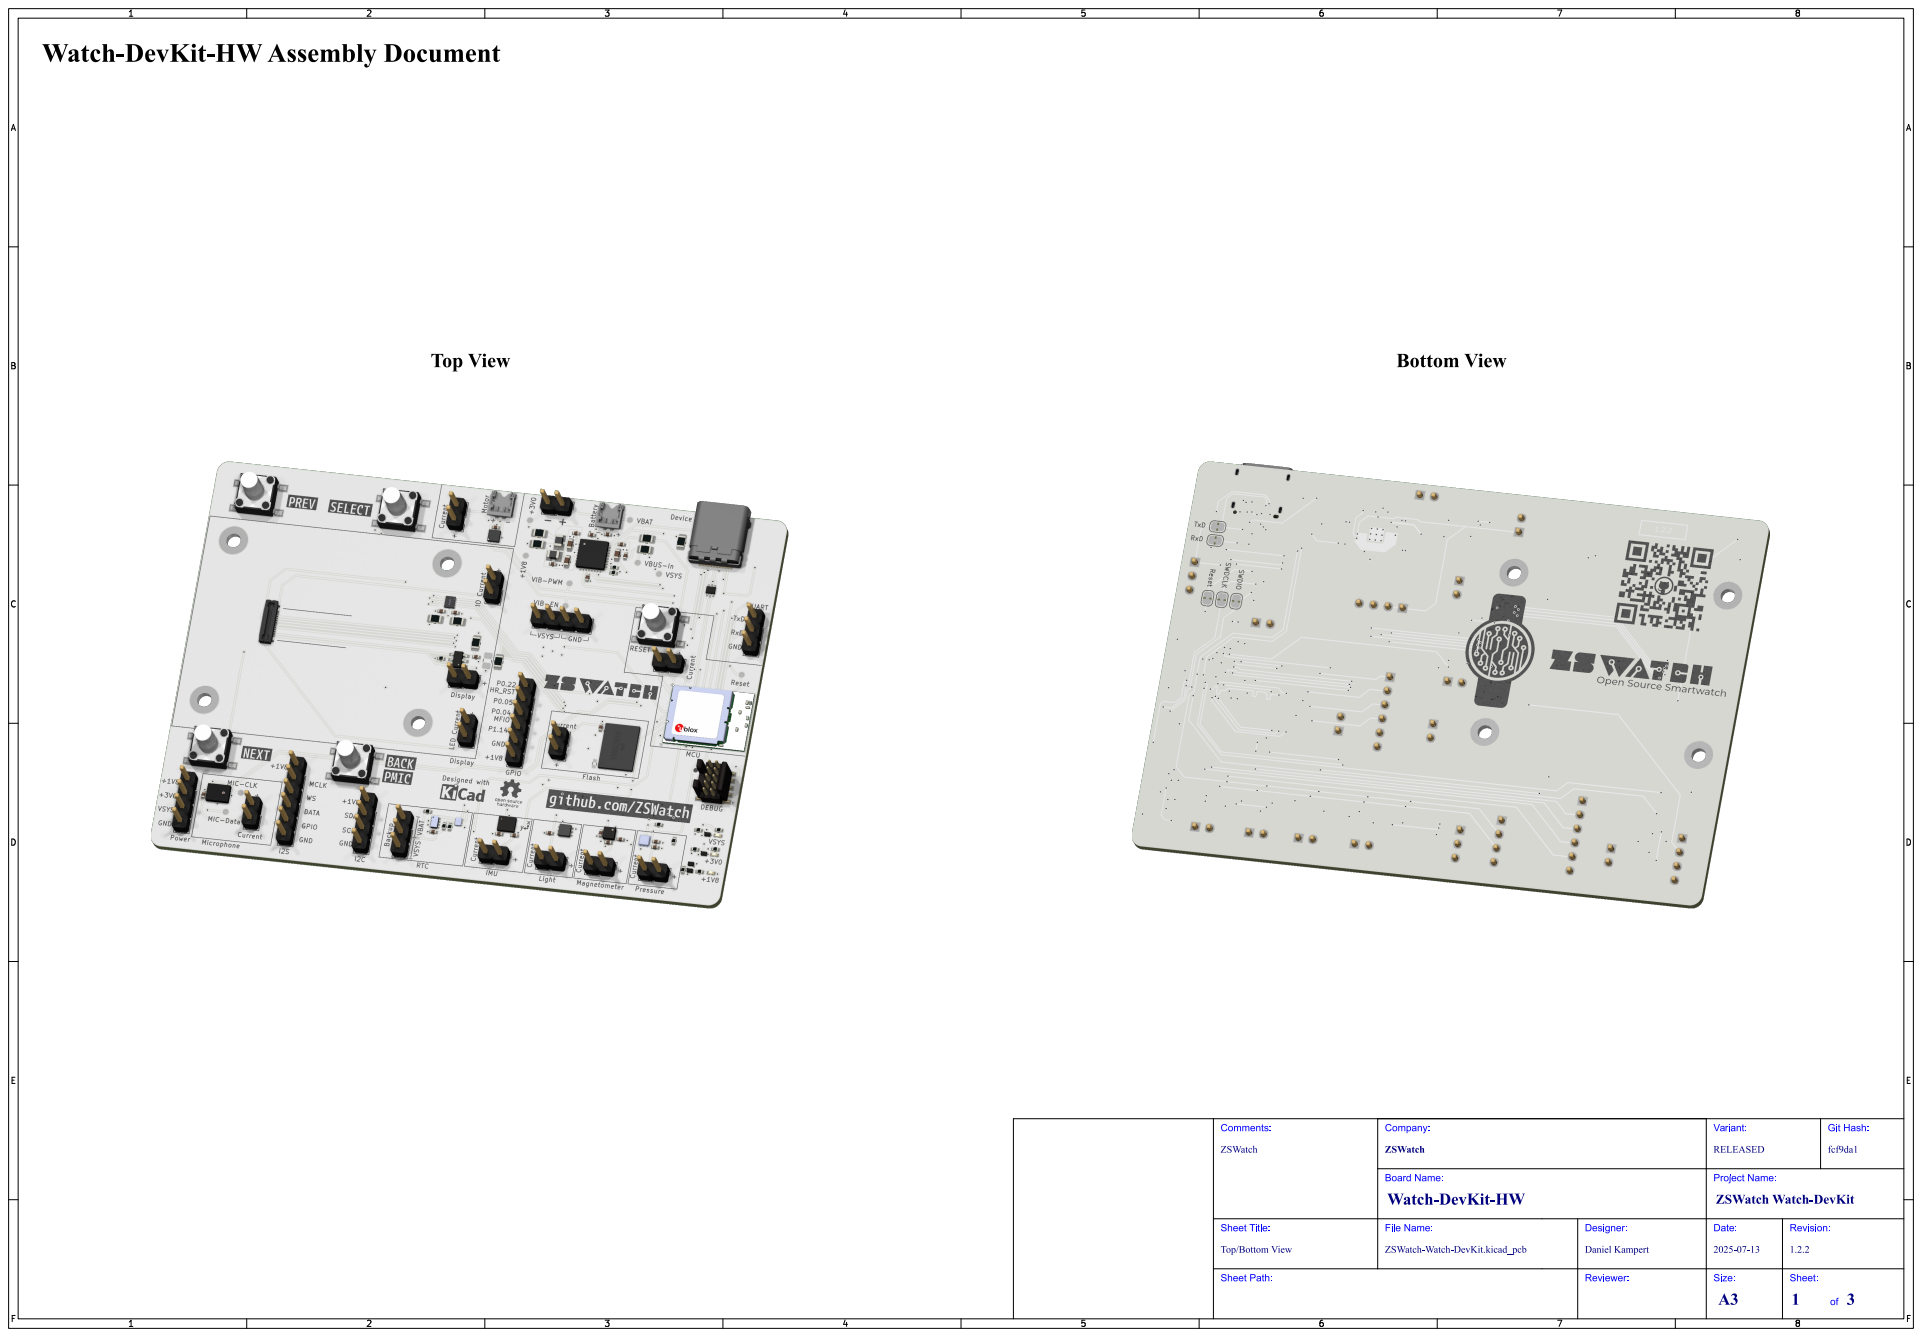
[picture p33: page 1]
Git; Hash:; fcf9da1; ZSWatch; Comments:; Sheet Path:; Sheet Title:; File Name:; Watch-DevKit-HW; ZSWatch Watch-DevKit; Company:; RELEASED; Variant:; Board Name:; ZSWatch-Watch-DevKit.kicad_pcb; Daniel Kampert; Designer:; Reviewer:; Project Name:; Date:; Revision:; Size:; Sheet:

Top/Bottom View

# Top Assembly (Scale 1:1)

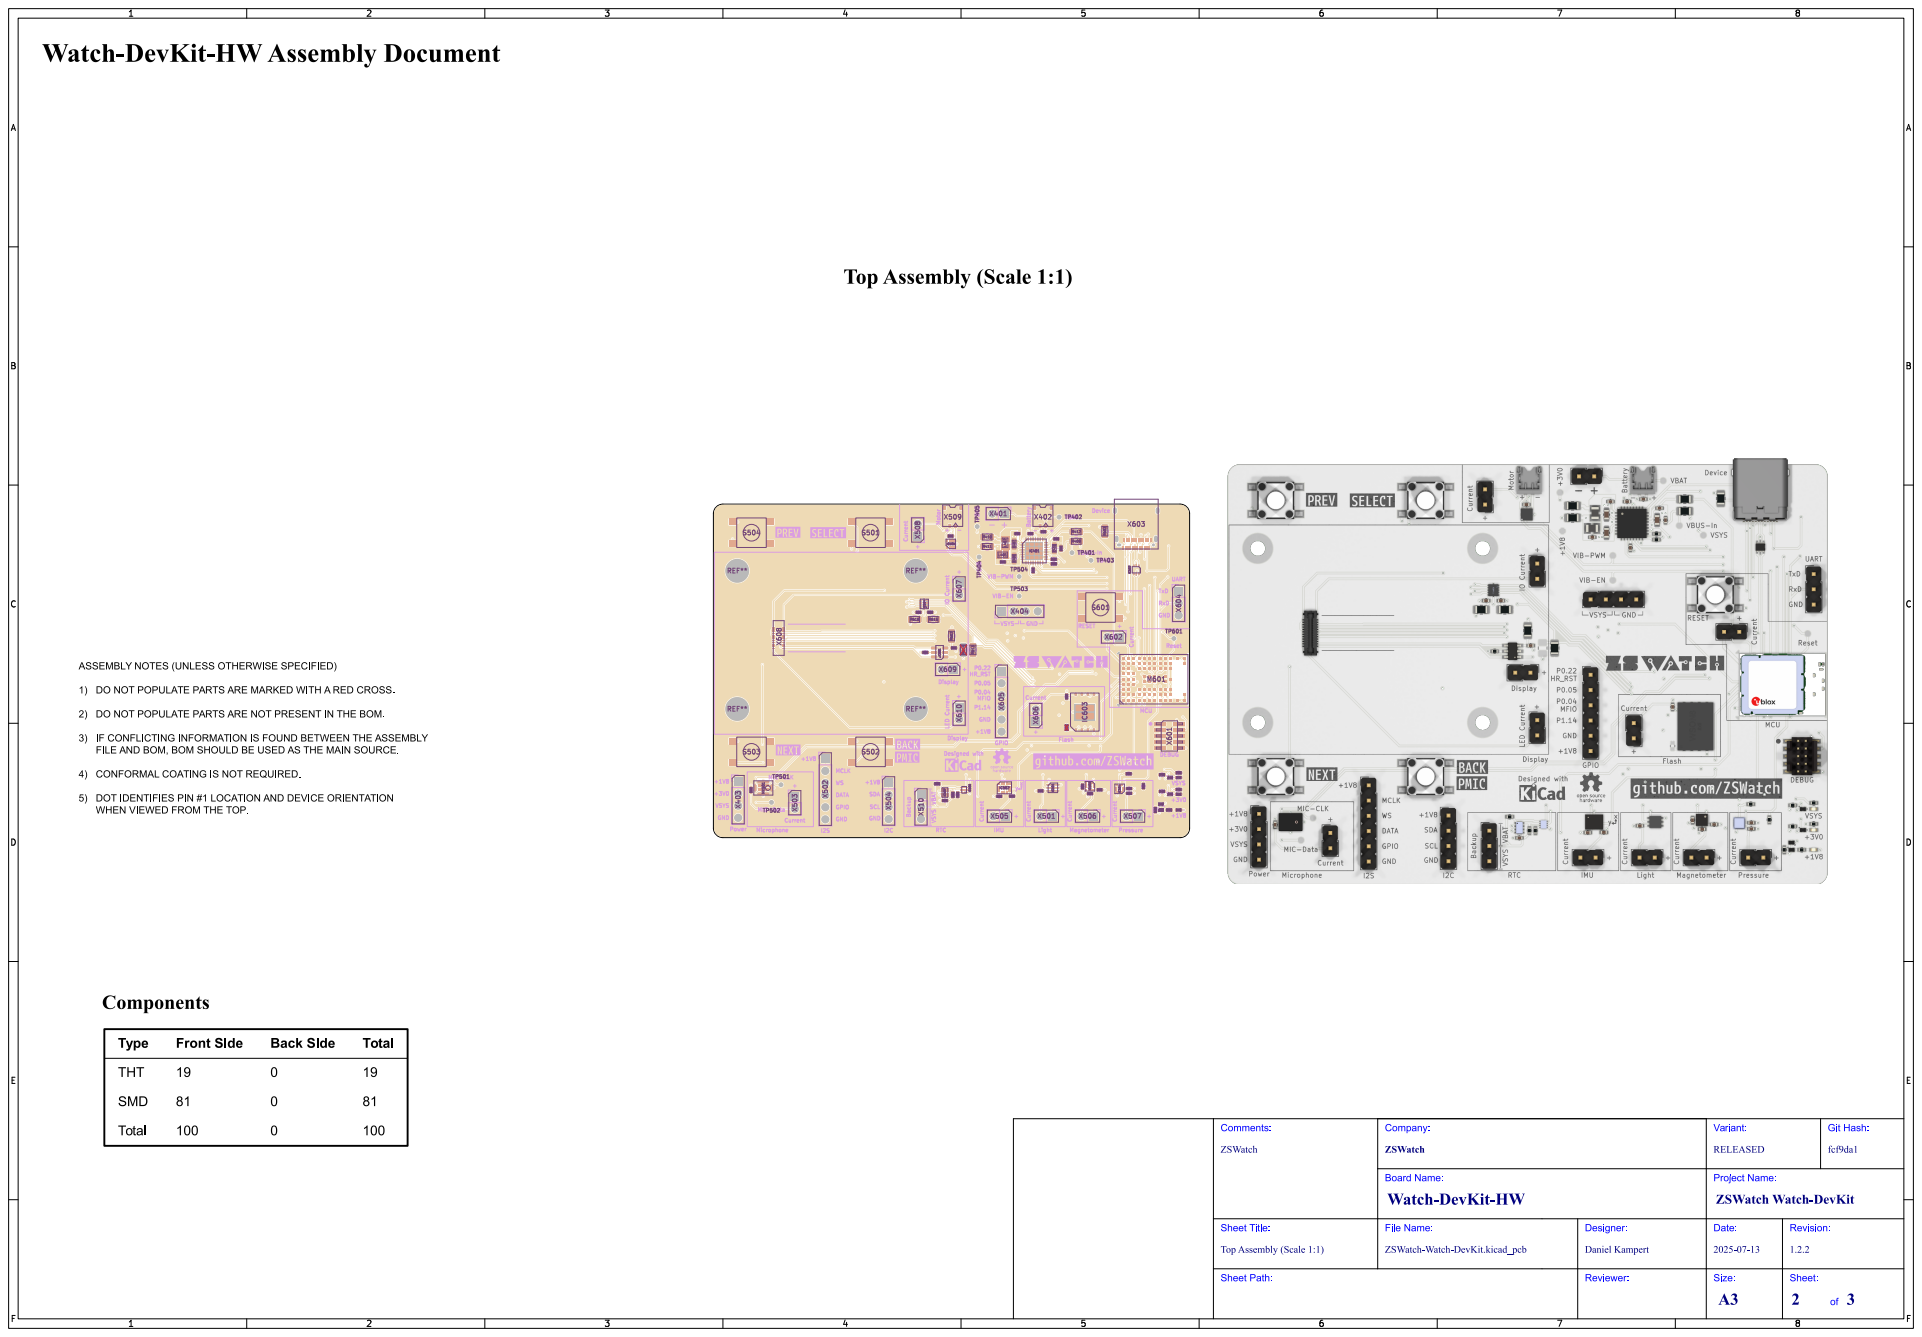
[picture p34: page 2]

# Bottom Assembly (Scale 1:1)

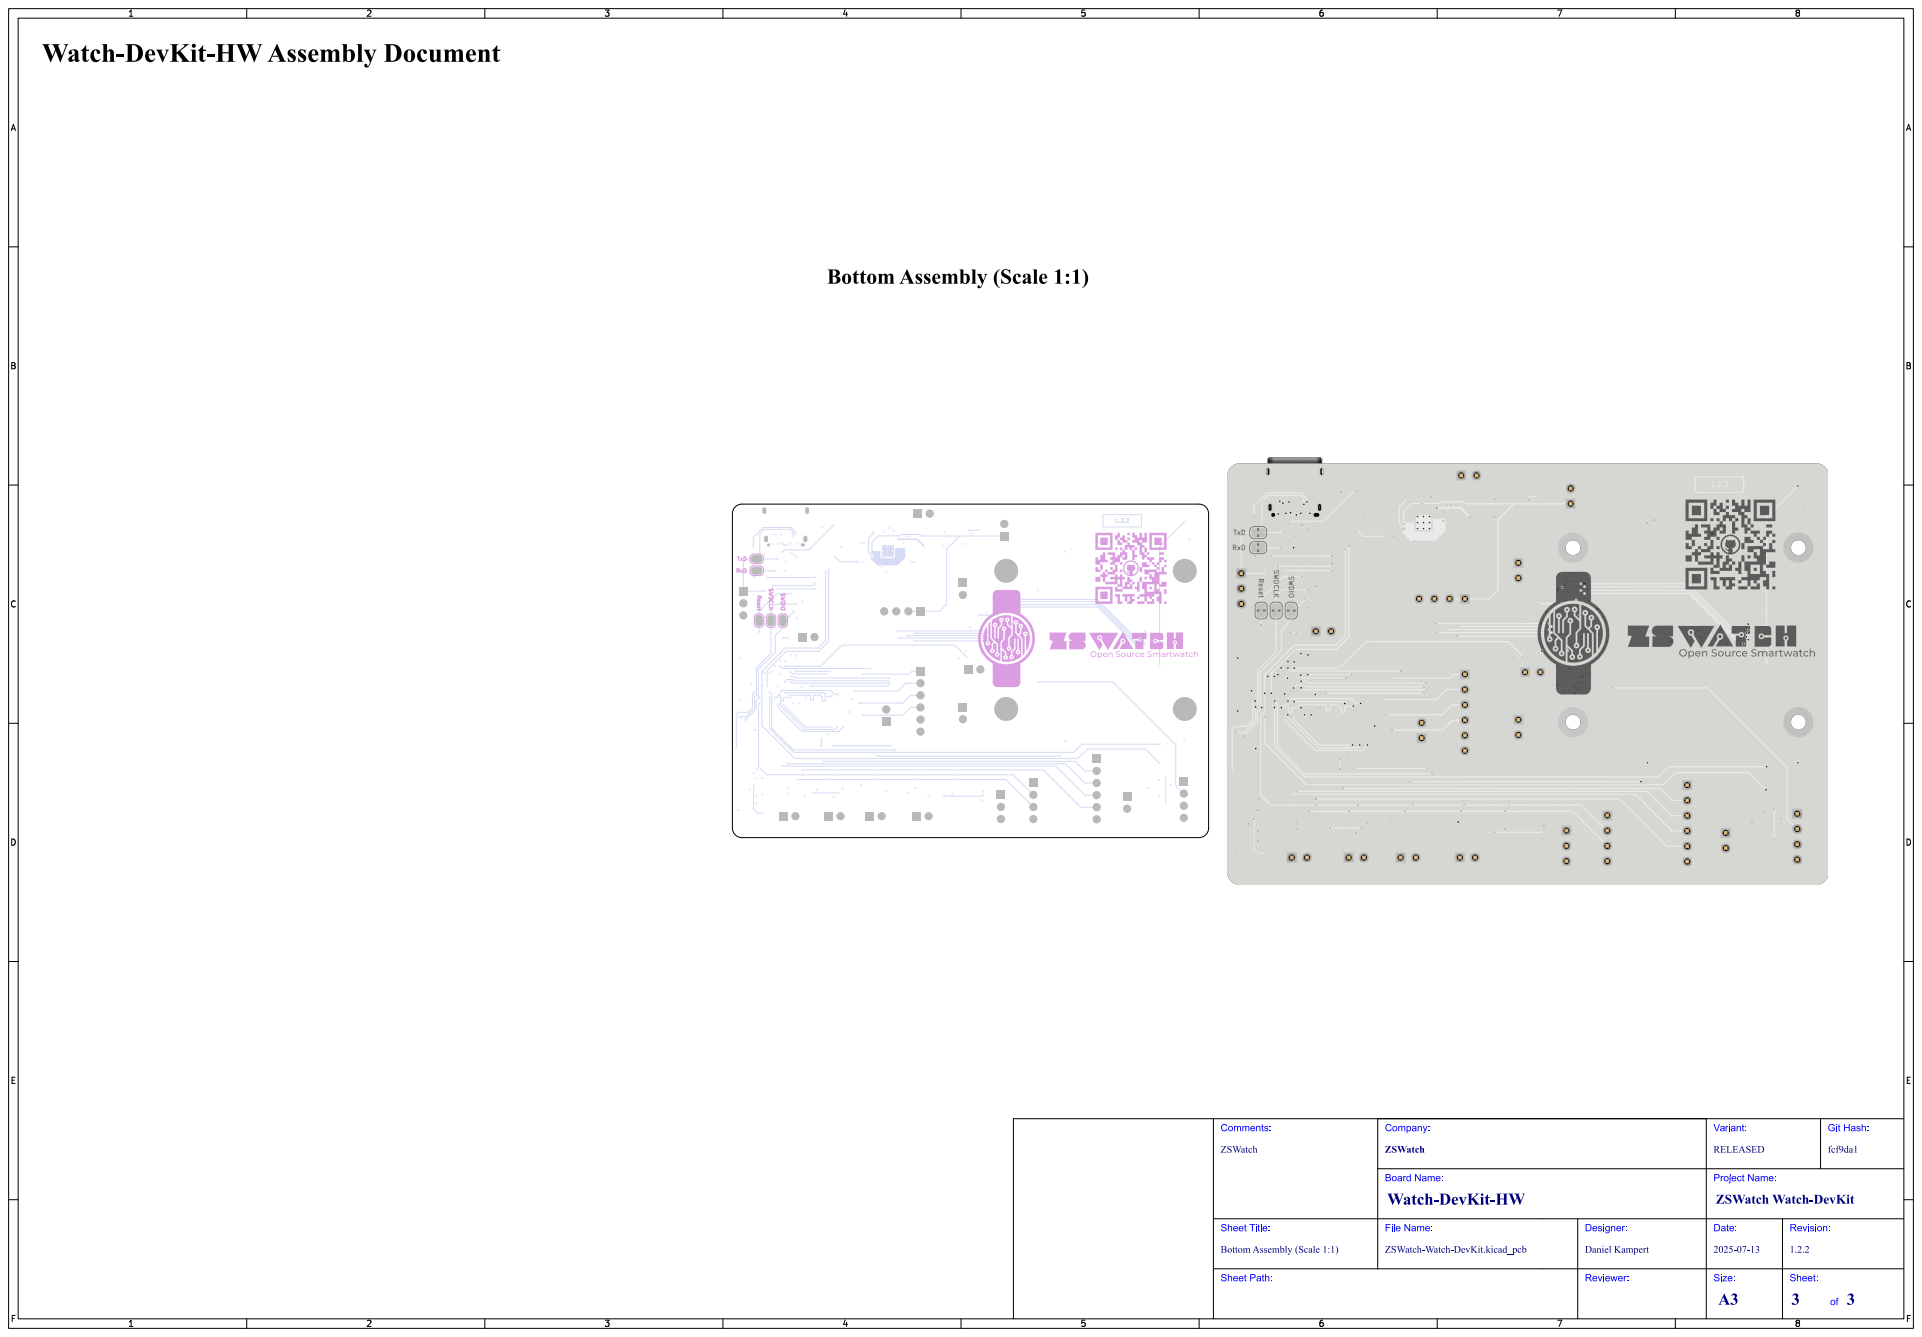
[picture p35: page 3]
Git; Hash:; fcf9da1; ZSWatch; Comments:; Sheet Title:; File Name:; Watch-DevKit-HW; ZSWatch Watch-DevKit; Company:; RELEASED; Variant:; Board Name:; ZSWatch-Watch-DevKit.kicad_pcb; Daniel Kampert; Designer:; Project Name:; Date:; Revision:; 8 Reset; SWDIO; TxD; SWDCLK; RxD

Bottom Assembly (Scale 1:1)

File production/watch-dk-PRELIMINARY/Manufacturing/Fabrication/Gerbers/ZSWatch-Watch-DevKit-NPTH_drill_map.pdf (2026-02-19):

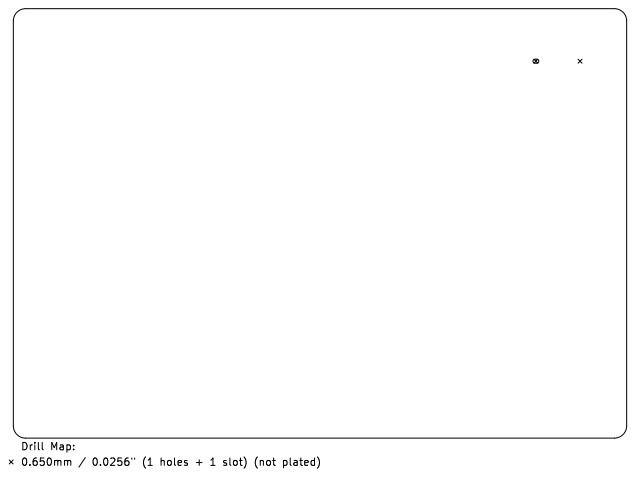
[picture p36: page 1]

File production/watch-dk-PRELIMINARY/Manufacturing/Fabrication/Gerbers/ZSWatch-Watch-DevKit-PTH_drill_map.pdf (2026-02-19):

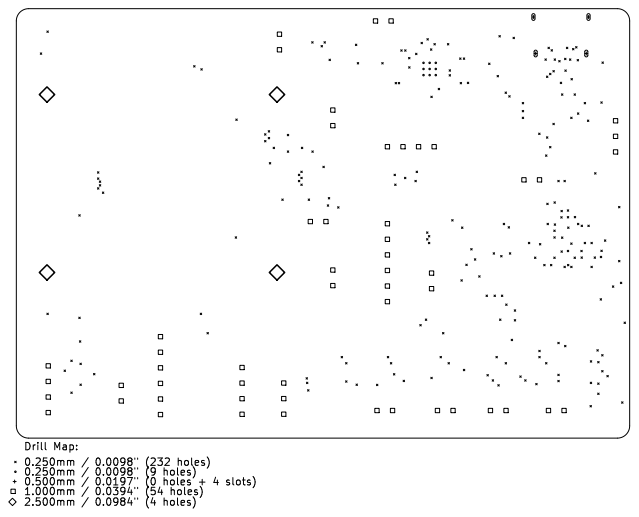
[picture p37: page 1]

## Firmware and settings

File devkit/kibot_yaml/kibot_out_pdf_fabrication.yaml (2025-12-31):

# KiBot output for generating Fabrication Document in PDF format
# https://kibot.readthedocs.io/en/latest/configuration/outputs/pcb_print.html

kibot:
  version: 1

outputs:
- name: @NAME@
  comment: '@COMMENT@'
  type: pcb_print
  category: '@DIR@'
  dir: '@DIR@'
  options:
    colored_pads: false
    colored_vias: false
    color_theme: '@COLOR_THEME@'
    output: '%f-fabrication%I%v.%x'
    format: 'PDF'
    title: '@DOC_TITLE@ Document'
    realistic_solder_mask: false
    dpi: 1200
    dnf_filter: _kibom_dnf_Config
    frame_plot_mechanism: 'internal' 
    sheet_reference_layout: '@SHEET_WKS@'
    drill:
      unify_pth_and_npth: '@PTH_NPTH@'
      group_slots_and_round_holes: @GROUP_ROUND_SLOTS@
    include_table:
      outputs:
        - name: '@NAME_TP_TOP@'
          text_alignment: 'left'
          invert_columns_order: false
          border_width: 0.4
          header_rule_width: 0.2
          horizontal_rule_width: 0
          vertical_rule_width: 0.2
          top_rule_width: 0.2
          bottom_rule_width: 0.2
          column_spacing: 2
          force_font_width: 1.27 # mm
        - name: '@NAME_TP_BOTTOM@'
          text_alignment: 'right'
          invert_columns_order: true
          border_width: 0.4
          header_rule_width: 0.2
          horizontal_rule_width: 0
          vertical_rule_width: 0.2
          top_rule_width: 0.2
          bottom_rule_width: 0.2
          column_spacing: 2
          force_font_width: 1.27 # mm
        - name: '@NAME_IMPEDANCE_TABLE@'
          text_alignment: 'left'
          invert_columns_order: false
          border_width: 0.4
          header_rule_width: 0.2
          horizontal_rule_width: 0
          vertical_rule_width: 0.2
          top_rule_width: 0.2
          bottom_rule_width: 0.2
          row_spacing: 3
          column_spacing: 2
          row_spacing: 3
        - name: '@NAME_DRILL_TABLE@'
          text_alignment: 'left'
          invert_columns_order: false
          border_width: 0.4
          header_rule_width: 0.2
          horizontal_rule_width: 0
          vertical_rule_width: 0.2
          top_rule_width: 0.2
          bottom_rule_width: 0.2
          row_spacing: 3
          column_spacing: 2
          force_font_width: 1 # mm

    pages:
      - scaling: @SCALING@
        title: '@DOC_TITLE@'
        sheet: 'Top Fabrication (Scale @SCALING@:1)'
        layer_var: 'Top Fabrication (Scale @SCALING@:1)'
        sheet_reference_color: '#000000'
        colored_holes: true
        holes_color: "#FFFFFF"
        layers:
          - layer: Edge.Cuts
            color: '#000000'
          - layer: F.Cu
            color: '#F2F2F2'
          - layer: F.Mask
            color: '#E2E2E2'
          - layer: F.Paste
            color: '#E2E2E2'
          - layer: F.Silkscreen
            color: '#DBDBDB'
          - layer: F.Fab
            plot_footprint_refs: false
            plot_footprint_values: false
            color: '#818181'
          - layer: F.Dimensions
            color: '#000000'

      - scaling: @SCALING@
        mirror: true
        mirror_pcb_text: false
        title: '@DOC_TITLE@'
        sheet: 'Bottom Fabrication (Scale @SCALING@:1)'
        layer_var: 'Bottom Fabrication (Scale @SCALING@:1)'
        sheet_reference_color: '#000000'
        colored_holes: true
        holes_color: "#FFFFFF"
        layers:
          - layer: Edge.Cuts
            color: '#000000'
          - layer: B.Cu
            color: '#F2F2F2'
          - layer: B.Mask
            color: '#E2E2E2'
          - layer: B.Paste
            color: '#E2E2E2'
          - layer: B.Silkscreen
            color: '#DBDBDB'
          - layer: B.Fab
            plot_footprint_refs: false
            plot_footprint_values: false
            color: '#818181'
          - layer: B.Dimensions
            color: '#000000'

      - scaling: @SCALING@
        title: '@DOC_TITLE@'
        sheet: 'Drill Drawing (%lp)'
        layer_var: 'Drill Drawing %lp (Scale @SCALING@:1)'
        sheet_reference_color: '#000000'
        colored_holes: true
        holes_color: "#FFFFFF"
        repeat_for_layer: '@LAYER_DRILL_MAP@'
        repeat_layers: 'drill_pairs'
        layers:
          - layer: '@LAYER_DRILL_MAP@'
            color: '#000000'
          - layer: 'Edge.Cuts'
            color: '#000000'
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

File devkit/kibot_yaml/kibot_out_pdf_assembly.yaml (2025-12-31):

# KiBot output for generating Assembly Document in PDF format
# https://kibot.readthedocs.io/en/latest/configuration/outputs/pcb_print.html

kibot:
  version: 1

outputs:
- name: @NAME@
  comment: '@COMMENT@'
  type: pcb_print
  category: '@DIR@'
  dir: '@DIR@'
  options:
    colored_vias: false
    colored_pads: false
    color_theme: '@COLOR_THEME@'
    output: '%f-assembly%I%v.%x'
    format: 'PDF'
    title: '@DOC_TITLE@ Document'
    realistic_solder_mask: false
    dpi: 1200
    dnf_filter: _kibom_dnf_Config
    sheet_reference_layout: '@SHEET_WKS@'
    include_table:
      outputs:
        - name: '@NAME_COMP_COUNT@'
          text_alignment: 'left'
          invert_columns_order: false
          border_width: 0.4
          header_rule_width: 0.2
          horizontal_rule_width: 0
          vertical_rule_width: 0
          top_rule_width: 0
          bottom_rule_width: 0
          row_spacing: 3
          column_spacing: 2
    pages:
      - scaling: @SCALING@
        layer_var: ''
        title: '@DOC_TITLE@'
        sheet: Top/Bottom View
        sheet_reference_color: '#000000'
        layers:
          - layer: '@LAYER_TITLE_PAGE@'
            color: '#000000'

      - scaling: @SCALING@
        layer_var: "Top Assembly (Scale @SCALING@:1)"
        title: '@DOC_TITLE@'
        sheet: Top Assembly (Scale @SCALING@:1)
        sheet_reference_color: '#000000'
        colored_holes: true
        holes_color: "#FFFFFF"
        layers:
          - layer: Edge.Cuts
            color: '#000000'
          - layer: F.Cu
            color: '#EEDAB5'
          - layer: F.Mask
            color: '#B9B9B9'
          - layer: F.Paste
            color: '#E1A98E'
          - layer: F.Silkscreen
            color: '#DB9DE1'
          - layer: F.Fab
            exclude_filter: '@FAB_EXCLUDE_FILTER@'
            color: '#744679'
          - layer: '@LAYER_ASSEMBLY_TEXT_TOP@'
            color: '#000000'
          - layer: '@LAYER_DNP_CROSS_TOP@'
            color: '#D63034'

      - scaling: @SCALING@
        layer_var: "Bottom Assembly (Scale @SCALING@:1)"
        mirror: true
        mirror_pcb_text: false
        title: '@DOC_TITLE@'
        sheet: Bottom Assembly (Scale @SCALING@:1)
        sheet_reference_color: '#000000'
        colored_holes: true
        holes_color: "#FFFFFF"
        layers:
          - layer: Edge.Cuts
            color: '#000000'
          - layer: B.Cu
            color: '#D5DBF4'
          - layer: B.Mask
            color: '#B9B9B9'
          - layer: B.Paste
            color: '#BCB9DD'
          - layer: B.Silkscreen
            color: '#DB9DE1'
          - layer: B.Fab
            exclude_filter: '@FAB_EXCLUDE_FILTER@'
            color: '#400080'
          - layer: '@LAYER_ASSEMBLY_TEXT_BOTTOM@'
            color: '#000000'
          - layer: '@LAYER_DNP_CROSS_BOTTOM@'
            color: '#D63034'

...
definitions:
  NAME: pdf_assembly
  COMMENT: Assembly document in PDF format
  DIR: Manufacturing/Assembly
  DOC_TITLE: Assembly
  COLOR_THEME: Altium_Theme
  SHEET_WKS: ${KIPRJMOD}/templates/KDT_Template_PCB_GIT_A4.kicad_wks
  SCALING: 1.0
  FAB_EXCLUDE_FILTER: exclude_testpoints
  LAYER_TITLE_PAGE: TitlePage
  LAYER_ASSEMBLY_TEXT_TOP: F.AssemblyText
  LAYER_ASSEMBLY_TEXT_BOTTOM: B.AssemblyText
  LAYER_DNP_CROSS_TOP: F.DNP
  LAYER_DNP_CROSS_BOTTOM: B.DNP
  NAME_COMP_COUNT: csv_comp_count

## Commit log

2025-09-23 Bug: Issue #155
    The ship mode pin of the nPM1300 has an internal pull-up to VSYS.
    Disconnect button 2 from the MCU and read it directly from the nPM1300.
    Closes #155
    [MCU.kicad_sch, ZSWatch-Watch-DevKit.kicad_pcb]
2025-09-23 Task: Issue #157
    - Change part number for SWD connector to 62201021121
    Closes #157
    [MCU.kicad_sch, ZSWatch-Watch-DevKit.kicad_pcb]
2025-09-23 Bug: Issue #158
    - Fix silkscreens
    - Add pull-up resistors to I2C lines
    - Set the Pull-Up for Flash CS to NA
    - Fix wrong part number for the I2C header
    Closes #158
    [MCU.kicad_sch, Peripherals.kicad_sch, Power.kicad_sch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]
2025-09-23 Task: Issue #159
    - Center the mounting holes of the display in the PCB
    Closes #159
    [ZSWatch-Watch-DevKit.kicad_pcb]
2025-09-23 Release 1.2.1
    [Revision History.kicad_sch]
2025-09-26 Update outputs (release)
    [ZSWatch-Watch-DevKit-(L1-L4)_NPTH_drill_table.csv, ZSWatch-Watch-DevKit-(L1-L4)_drill_table.csv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]
2025-12-31 Initialize development branch for version 1.2.2
    [ZSWatch-Watch-DevKit-(L1-L4)_NPTH_drill_table.csv, ZSWatch-Watch-DevKit-(L1-L4)_drill_table.csv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]
2025-12-31 Bug: Issue #165
    Replace SWD connector with BD125-10-A-0305-0580-L-B
    Closes #165
    [MCU.kicad_sch, ZSWatch-Watch-DevKit.kicad_pcb]
2025-12-31 Bug: Issue #168
    - Remove value from XLSX BOM to avoid KiCost based issues
    with wrong component values.
    - Clean up
    - Fix swapped manf and manf# for Lumex LED
    Closes #168
    [Power.kicad_sch, ZSWatch-Watch-DevKit.kicad_pcb]
2025-12-31 Task: Issue #170
    - Rename DISPLAY-EN signal to TOUCH-EN
    Closes #170
    [MCU.kicad_sch, Power.kicad_sch, ZSWatch-Watch-DevKit.kicad_pcb]
2025-12-31 Bug: Issue #171
    Fix KiBot warnings for power LEDs
    Closes #171
    [Power.kicad_sch, ZSWatch-Watch-DevKit.kicad_pcb]
2025-12-31 Bug: Issue #172
    - Fix wrong resistor for VREF2 pin for the level shifter
    - Update changelog
    Closes #172
    [Peripherals.kicad_sch, ZSWatch-Watch-DevKit.kicad_pcb]
2025-12-31 Feature: Issue #174
    Add allignment markers for the MCU module to the copper layer
    Closes #174
    [ZSWatch-Watch-DevKit.kicad_pcb]
2025-12-31 Task: Issue #144
    - Add STL for the display frame holder
    Closes #144
    [Display_Holder.stl]
2025-12-31 Bug: Issue #175
    - Swap "Prev" and "Next" silkscreen
    Closes #175
    [ZSWatch-Watch-DevKit.kicad_pcb]
2025-12-31 Bug: Issue #179
    - Wrong silkscreen for Display current
    Closes #179
    [MCU.kicad_sch, ZSWatch-Watch-DevKit.kicad_pcb]
2025-12-31 Feature: Issue #180
    - Add additional pin to I2S header
    Closes #180
    [MCU.kicad_sch, Peripherals.kicad_sch, Project Architecture.kicad_sch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]
2025-12-31 Feature: Issue #180
    - Add additional header for VSYS
    - Fix wrong silkscreen size for the I2S header
    - Fix wrong CHANGELOG entry for issue #180
    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
    [Power.kicad_sch, ZSWatch-Watch-DevKit.kicad_pcb]
2025-12-31 Task: Issue #182
    - Bring back ZSWatch logo
    - Move some silkscreen elements and components for better visibility
    Closes #182
    [ZSWatch-Watch-DevKit.kicad_pcb]
2025-12-31 Task: Issue #173
    - Replace 0R with closed jumper
    Closes #173
    [MCU.kicad_sch, ZSWatch-Watch-DevKit.kicad_pcb]
2025-12-31 Task: Issue #183
    - Remove 0R and 5k1 CC resistors
    Closes #183
    [MCU.kicad_sch, ZSWatch-Watch-DevKit.kicad_pcb]
2025-12-31 Task: Fix DNP layers
    - Bring back Eco1 and Eco2 layers
    - Add additional layers for DNP components
    [ZSWatch-Watch-DevKit.kicad_pcb]
2025-12-31 Feature: Issue #184
    - Add 0R to disconnect VBUS from the USB connector
    - Add bridge to remove VBUS from nPM1300
    Closes #184
    [MCU.kicad_sch, Power.kicad_sch, ZSWatch-Watch-DevKit.kicad_pcb]
2025-12-31 Bug: Issue #185
    - Set all solder jumpers to not assembled and remove them from BOM
    Closes #185
    [MCU.kicad_sch, ZSWatch-Watch-DevKit.kicad_pcb]
2025-12-31 Feature: Issue #186
    Allow powering RTC from any voltage source
    Closes #186
    [Peripherals.kicad_sch, ZSWatch-Watch-DevKit.kicad_pcb]
2025-12-31 Fix wrong page numbers in Project Architecture schematic
    [Project Architecture.kicad_sch]
2025-12-31 Add logo and QR code to backside silkscreen.
    [ZSWatch-Watch-DevKit.kicad_pcb]
2025-12-31 Task: Issue #187
    Replace mounting holes with holes with a bigger margin
    Closes #187
    [ZSWatch-Watch-DevKit.kicad_pcb]
2025-12-31 Fix wrong logo and template path
    [kibot_out_pdf_assembly.yaml, kibot_out_pdf_fabrication.yaml]
2025-12-31 Push outputs from CI/CD (2025-12-18 09:31:01)
    [ZSWatch-Watch-DevKit-(L1-L4)_NPTH_drill_table.csv, ZSWatch-Watch-DevKit-(L1-L4)_drill_table.csv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]
2025-12-31 Revert "Push outputs from CI/CD (2025-12-18 09:31:01)"
    This reverts commit 18f20ee4dfb665363af7d56629fbcb7e6c1b05b0.
    [ZSWatch-Watch-DevKit-(L1-L4)_NPTH_drill_table.csv, ZSWatch-Watch-DevKit-(L1-L4)_drill_table.csv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]
2025-12-31 Revert "Fix wrong logo and template path"
    This reverts commit 8fd3e9ab9207343e0e09c2526f1a5cb8a6d33322.
    [kibot_out_pdf_assembly.yaml, kibot_out_pdf_fabrication.yaml]
2025-12-31 Revert "Task: Issue #187"
    This reverts commit 0d9e70aa795245cd32cfea7446207e34cd6ffd31.
    [ZSWatch-Watch-DevKit.kicad_pcb]
2025-12-31 Revert "Add logo and QR code to backside silkscreen."
    This reverts commit 72bffc7b9b4678faa50e0150c8a60641f706a446.
    [ZSWatch-Watch-DevKit.kicad_pcb]
2025-12-31 Revert "Fix wrong page numbers in Project Architecture schematic"
    This reverts commit 85922ebd93d309191d5d3522e6a6ede7ddadbc08.
    [Project Architecture.kicad_sch]
2025-12-31 Revert "Feature: Issue #186"
    This reverts commit 73512b60dac517a3d61ff56758c38d705b52f64d.
    [Peripherals.kicad_sch, ZSWatch-Watch-DevKit.kicad_pcb]
2025-12-31 Revert "Bug: Issue #185"
    This reverts commit 3b9bfdeb6c5eb0a24956d5269e31e46a928e9a1e.
    [MCU.kicad_sch, ZSWatch-Watch-DevKit.kicad_pcb]
2025-12-31 Revert "Feature: Issue #184"
    This reverts commit f0a18e2688c143ce39ba7e204db2730629a8a8a3.
    [MCU.kicad_sch, Power.kicad_sch, ZSWatch-Watch-DevKit.kicad_pcb]
2025-12-31 Revert "Task: Fix DNP layers"
    This reverts commit 63d903d66526086c67e651f4df410e946d6cd481.
    [ZSWatch-Watch-DevKit.kicad_pcb]
2025-12-31 Revert "Task: Issue #183"
    This reverts commit 95470eee4245e75bc118c43db889d62a8661c396.
    [MCU.kicad_sch, ZSWatch-Watch-DevKit.kicad_pcb]
2025-12-31 Revert "Task: Issue #173"
    This reverts commit e04384c88487c0ad4268dbede6dd77cc14cfed5f.
    [MCU.kicad_sch, ZSWatch-Watch-DevKit.kicad_pcb]
2025-12-31 Revert "Task: Issue #182"
    This reverts commit db6fa3bc4ee1549e0a4aae51d8962b8cbad367bc.
    [ZSWatch-Watch-DevKit.kicad_pcb]
2025-12-31 Revert "Feature: Issue #180"
    This reverts commit e294da7cfd2de151837bcacc2c2eee3b2a5acfa5.
    [Power.kicad_sch, ZSWatch-Watch-DevKit.kicad_pcb]
2025-12-31 Revert "Feature: Issue #180"
    This reverts commit 364f4bbc8b17cbfb7f0155205af3315526997ba0.
    [MCU.kicad_sch, Peripherals.kicad_sch, Project Architecture.kicad_sch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]
2025-12-31 Revert "Bug: Issue #179"
    This reverts commit 61532d731451c58d7eb1f76348ddf49b975551aa.
    [MCU.kicad_sch, ZSWatch-Watch-DevKit.kicad_pcb]
2025-12-31 Revert "Bug: Issue #175"
    This reverts commit 3845c44b3bc90674c1ebe198ac0160466ee981d9.
    [ZSWatch-Watch-DevKit.kicad_pcb]
2025-12-31 Revert "Task: Issue #144"
    This reverts commit ef1faedca92302927e7efd11f3b023b8c5af0ee2.
    [Display_Holder.stl]
2025-12-31 Revert "Feature: Issue #174"
    This reverts commit a258055a47c56b8763088da3e06577d57b5d3abc.
    [ZSWatch-Watch-DevKit.kicad_pcb]
2025-12-31 Revert "Bug: Issue #172"
    This reverts commit d2b21792fba04b32ee89f1631bab4de80096e44a.
    [Peripherals.kicad_sch, ZSWatch-Watch-DevKit.kicad_pcb]
2025-12-31 Revert "Bug: Issue #171"
    This reverts commit 7b6ad907520e90ad5be791828e13b3994ee96338.
    [Power.kicad_sch, ZSWatch-Watch-DevKit.kicad_pcb]
2025-12-31 Revert "Task: Issue #170"
    This reverts commit 9a9aff6ecb6cca4ce76948ecb2e13e9bd5125142.
    [MCU.kicad_sch, Power.kicad_sch, ZSWatch-Watch-DevKit.kicad_pcb]
2025-12-31 Revert "Bug: Issue #168"
    This reverts commit 94dc1bb3614500285b5ecbd3fff22a02d7d92872.
    [Power.kicad_sch, ZSWatch-Watch-DevKit.kicad_pcb]
2025-12-31 Revert "Bug: Issue #165"
    This reverts commit cfd33f8e9c92730593ade52965219aace560bf60.
    [MCU.kicad_sch, ZSWatch-Watch-DevKit.kicad_pcb]
2025-12-31 Revert "Initialize development branch for version 1.2.2"
    This reverts commit 4288295dc87037d9f0f59f8c8a7b9da29675ea11.
    [ZSWatch-Watch-DevKit-(L1-L4)_NPTH_drill_table.csv, ZSWatch-Watch-DevKit-(L1-L4)_drill_table.csv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]
2025-12-31 Push outputs from CI/CD (2025-12-31 09:51:36)
    [ZSWatch-Watch-DevKit-(L1-L4)_NPTH_drill_table.csv, ZSWatch-Watch-DevKit-(L1-L4)_drill_table.csv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]
2026-02-19 Push outputs from CI/CD (2026-02-19 10:48:54)
    [ZSWatch-Watch-DevKit-B_Cu.gbr, ZSWatch-Watch-DevKit-B_Mask.gbr, ZSWatch-Watch-DevKit-B_Paste.gbr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]
2026-02-19 Push outputs from CI/CD (2026-02-19 11:22:16)
    [ZSWatch-Watch-DevKit-B_Cu.gbr, ZSWatch-Watch-DevKit-B_Mask.gbr, ZSWatch-Watch-DevKit-B_Paste.gbr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]
